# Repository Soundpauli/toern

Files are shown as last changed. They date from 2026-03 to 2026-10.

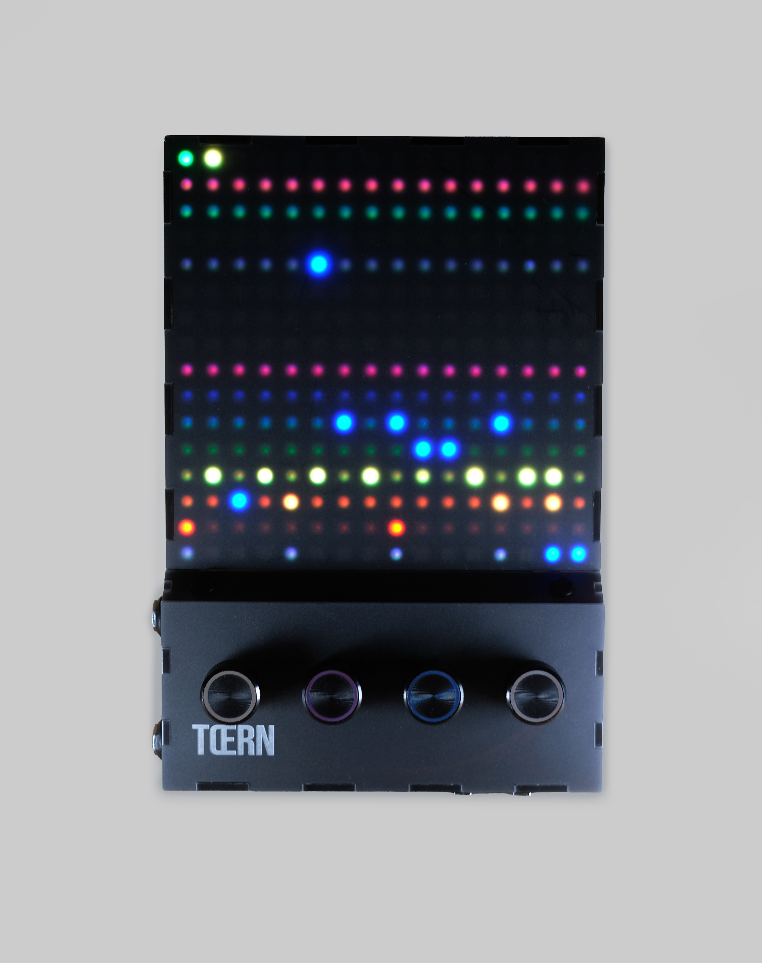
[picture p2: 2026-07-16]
handbook/topview.jpg

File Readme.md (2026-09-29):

# TŒRN `[tɜːn]`

**Open-source sequencer and sampler** — by [warft_ctrl](mailto:jpkuntoff@gmail.com)

> Say it like *turn*. As in: turn the knobs. Turn a doodle into a beat. Turn “I can’t play piano” into “wait, that slap though.”

TŒRN is a sequenced musical device for beginners, makers, and anyone who likes blinking lights more than plugin menus. Think **Etch-A-Sketch™ energy**, but instead of drawing a wobbly staircase you draw drums, synths, and happy accidents — on a vivid **16×16 RGB LED matrix** that is both the screen *and* the keyboard.

It sits on a Teensy 4.1, runs from a Micro SD card full of your WAVs, and is happy on a desk, in a backpack, or on battery at the park where strangers will ask “what *is* that?”

**Status:** under very active development. Things move fast. Stay tuned, and don’t be surprised if yesterday’s weird bug is today’s charming feature (or the other way around).

---

## What it is (in plain language)

You get:

- **8 sample voices** for drums, one-shots, loops, and “that weird recording from the metro”
- **1 three-voice polyphonic synth** with presets (bass, keys, chiptune, pads… the usual suspects)
- **2 monophonic synths** with LFO and arpeggiator for leads that refuse to sit still
- A **16-step × 16-page** sequencer (256 steps of room to overthink), pattern chaining into songs, MIDI in/out, filters, bitcrush, reverb, and enough real-time knobs to keep your hands busy and your laptop jealous

No laptop required once it’s built. Samples live on the SD card. Patterns autosave. You twist, tap, and suddenly it’s 2 a.m.

For the friendly guided tour (first beat in about a minute), open the **[handbook](./handbook/index.html)** in this repo.

---

## A tiny history

TŒRN builds on the legacy of the **NI404**, with more features, fewer cables dangling off the side, and a custom PCB where everything mounts cleanly. The older “extra boards and hope” era is over.

Meet the glow-up:

- **RGB-I2C rotary encoders** — smoother, prettier, and they light up like they mean it  
- **Custom PCB** — codec, charging, and jacks on one board  
- **USB-C** — because micro-USB was a character-building experience we no longer need  
- **LiPo charging port** — optional battery for true “make beats on a train” energy (battery not included; we trust you with electricity)  
- **Proper audio I/O** — 6.35 mm headphone out, line in/out, mic in, *plus* a built-in mic for “sample the room right now” moments  
- **TRS MIDI in/out** — play nice with the rest of your setup  
- **On/off switch** — underrated luxury  
- **Touch buttons** — for the things knobs shouldn’t monopolize  
- **Laser-cut acrylic case** — files included; looks finished, not “breadboard cosplay”  
- **JST connectors** — expansion leads plug in  

Open source as always: schematics, code, and design files are here for you to poke, fork, and improve.

---

## Features (the longer version)

### Sequencer

- **16 channels** in spirit: 8 sample voices (1–8), one 3-voice poly synth (11), two mono synths (13–14)  
- **16 steps per page × 16 pages** → 256 steps per song arrangement space  
- **Voice mode**: each voice keeps its own pattern length. It loops the pages that hold its notes, pitches included, while the other voices keep looping on their own  
- **FIRE** (ETC menu): optional playhead sparks when a chosen voice’s notes light white  
- Store up to **999 patterns**, **999 samples**, **100 samplepacks**  
- **Autosave / autoload** so your 3 a.m. genius doesn’t vanish at boot  
- **Switch patterns live** without stopping playback  
- **Song mode**: chain up to **64** patterns into something resembling a composition  
- Pattern ops: copy/paste, transpose page/channel (±1 octave), smart random notes (major/minor + rhythm ideas), clear page/channel  

### Sample voices (channels 1–8)

- Up to **~12 seconds** per voice at 44.1 kHz  
- Browse and load samples **while playing** (yes, really)  
- Per-voice start/end trim, forward/reverse  
- Samplepacks (including pack 0 = custom per-voice assignment)  
- Record from **built-in mic / line-in / mic-in** straight in the sample browser  
- Save or merge used samples back to the SD card as a pack  

### Synth voices

**Channel 11 — poly synth**

- 3 oscillators per voice × 3 voices  
- Presets: BASS, KEYS, CHPT, PAD, WOW, ORG, FLT, LEAD, ARP, BRSS  
- Per-voice ADSR, filter envelope, pan, volume, pitch (cents & semitones), waveform  

**Channels 13–14 — mono synths**

- 2 oscillators each  
- ADSR, LFO (rate/depth), arpeggiator (step/span)  
- Waveforms: sine, saw, square, triangle  

### Effects (all channels)

- **ADSR** — attack / decay / sustain / release (0–32 range)  
- **Bitcrusher** — bit depth 1–16 (0 = bypass), sample-rate reduction down to glorious crunch  
- **Filter** — LP / HP / BP, 0–10 kHz, resonance 0.7–5.0, smooth transitions  
- **Reverb** — room size, damping, wet/dry  
- Fast filter access on encoder #3 during runtime (assignable default per channel)  

### MIDI, clock & extras

- TRS MIDI in/out, clock send/receive, notes, transport  
- BPM **40–300**, internal clock, external MIDI clock, tap tempo via touch  
- Live recording / looping (touch-hold), up to ~12 s per voice  
- Note probability, velocity, condition triggers (those “only every other bar” tricks)  
- Global transpose, per-channel detune & octave, fine cents on the poly synth  
- Mute / solo, pattern modes (OFF, ON, SONG, NEXT)  
- Stereo routing options, optional external WS2812 strip for ripple eye-candy synced to the music  

---

## Tech specs

| | |
|---|---|
| **Brain** | Teensy 4.1, PSRAM fitted. Audio codec is the SGTL5000 on the carrier |
| **Memory** | 16 MB PSRAM target; Micro SD (handbook suggests up to 64 GB, SanDisk Ultra) |
| **Audio** | 44.1 kHz, 16-bit mono WAV |
| **Controls** | 4× RGB illuminated I2C rotary-push encoders, 3 touch switches |
| **Display** | 16×16 RGB LED matrix (FastLED); up to 2 modules → 32×16 |
| **LED strip** | External 5 V WS2812 connector (configurable length) |
| **I/O** | 6.35 mm headphones, line in/out, mic in; built-in mic; TRS MIDI in/out |
| **Power** | USB-C or optional LiPo + charging |

---

## SD card over USB (Menu → ETC → SD)

TŒRN does **not** mount the Micro SD as USB mass storage. That would be too easy, and also fight the audio engine. Instead:

While **Menu → ETC → SD** is open (screen: WAIT → OK), you can browse and transfer files over **USB Serial**.

### Primary — browser tool

1. On the device: open **Menu → ETC → SD**  
2. On a computer: open **[https://sdtool.tyng.app](https://sdtool.tyng.app)** in desktop **Chrome or Edge**  
3. Click **Connect**, pick the Teensy serial port  
4. Stay on ETC → SD for the whole session  

WAV uploads are converted in the browser to **44.1 kHz mono 16-bit**. Drag folders, multi-file drops, and zip archives are supported.

### Secondary — local CLI / scripting

Any USB Type that includes Serial (e.g. **Serial + MIDI**):

```bash
cd standalone-tools/sd-tool-standalone
pip install pyserial
python3 toern_sd.py -p /dev/cu.usbmodemXXXX list /
# also: put / rm / mkdir / get
python3 toern_sd.py web       # optional local UI at http://127.0.0.1:8787
```

Insert or eject the SD card only with the unit **off** — the firmware re-indexes on boot.

---

## Repo map (where stuff lives)

| Path | What’s there |
|---|---|
| `toern.ino` + `toern_*.ino` | Firmware (the fun / terrifying part) |
| `src/` | Modified audio bits (resampler, freeverb DMA) |
| [`BUILD.md`](./BUILD.md) | Order the rev H board, what to solder, first power-up |
| [`info.md`](./info.md) | Compile and flash (PlatformIO) |
| `PCB/toern_revH/` | Current KiCad board, gerbers, JLCPCB BOM |
| `handbook/` | Human-friendly operator’s guide (how to *use* the device) |
| `devdocs/` | [Docusaurus](./devdocs/) code and hardware (rev H) docs → published at `/docs/` |
| `tools/` / `standalone-tools/` | Helpers; SD tool, sample converter, browser sim → tyng.app |
| `standalone-tools/web-standalone/` | Browser simulator → [sim.tyng.app](https://sim.tyng.app/) |
| `standalone-tools/teensyloader-standalone/` | Firmware flasher → [firmware.tyng.app](https://firmware.tyng.app/) (GPL-3.0) |
| `website/` | Project site (local/deploy-only; handbook + docs copied in manually) |

---

## External libraries & modifications

This project leans on several libraries. Some are stock; some got lovingly (and necessary-ly) poked.

### Modified

- **ResamplingReader.h** (`teensy-variable-playback`)  
  Variable rates, interpolation, multi-channel, loop types (repeat / ping-pong), crossfading — in `src/resamplerReader.h`

- **Freeverb** (`effect_freeverb_dmabuf`)  
  DMAMEM-friendly reverb for Teensy 4.1 — `src/effect_freeverb_dmabuf.*`

- **FastLED**  
  `FASTLED_ALLOW_INTERRUPTS 0` so LEDs and audio don’t argue mid-beat; custom `FastLEDshow()` / `FastLEDclear()` wrappers

- **MIDI**  
  Bigger Serial8 buffers for dense clock traffic (`RX 2048`, `TX 128`) and custom TRS MIDI settings

### Standard / upstream

- **TeensyPolyphony** by Nic Newdigate — polyphonic heart of the thing  
- **Audio Library** (PJRC)  
- **WS2812Serial**, **i2cEncoderLibV2**, **FastTouch**

---

## Get one

Order a TŒRN at **[toern.live](https://toern.live/)**. Questions go to **info@toern.live**.

When it arrives, open the **[handbook](./handbook/index.html)** and start at First beat. Power is USB-C. A battery and a microSD card are not in the parcel; the buy page and the handbook hardware chapter name what to get.

Firmware changes: [`info.md`](./info.md) to flash, [`devdocs/`](./devdocs/) for how the code is shaped, [`firmware-edits`](./devdocs/docs/contributing/firmware-edits.md) for a new menu page. Fabricating a board from the design files is [`BUILD.md`](./BUILD.md) — that is not how a TŒRN is ordered.

---

## License

- **Software / code**: [MIT](./LICENSE) — free for personal and commercial use.  
- **Firmware loader** (`standalone-tools/teensyloader-standalone/` and `tools/teensyloader/`): [GPL-3.0](./standalone-tools/teensyloader-standalone/LICENSE), because that tool is Teensy Loader Javascript. GPL-3.0 applies only to those folders.  
- **Hardware design files** (schematics, PCB layouts, Gerbers, etc.): [CC BY-NC 4.0](https://creativecommons.org/licenses/by-nc/4.0/) — personal / non-commercial use and modification. **Commercial hardware use needs written consent.**

Commercial hardware licensing: Jan aka **warft_ctrl** — jpkuntoff@gmail.com (Hamburg, Germany)

---

## Thank you

Huge thanks to **Paul Stoffregen** and the PJRC crew for Teensy, to the wider open-source audio community, and an especially loud shoutout to **Nic Newdigate** for teensy-polyphony — basically the soul of this project.

Made with too many late nights and exactly the right number of RGB LEDs.

**Jan aka warft_ctrl** (formerly soundpauli)  
Hamburg, 2026

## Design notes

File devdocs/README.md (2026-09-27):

# TŒRN Code Docs

Developer documentation for the TŒRN firmware — how the code is structured and how the pieces talk to each other.

This is **not** the operator handbook (device usage). That lives in the repo-root [`handbook/`](../handbook/) tree (copied into `website/handbook/` for deploy, same pattern as this docs site).

## Layout

| Path | Role |
|---|---|
| `devdocs/` | This Docusaurus app (source of truth in the repo) |
| `website/docs/` | Built static files served at `/docs/` (copied in manually for deploy) |

Like `handbook/`, sources live at the repo root. Publish by building here and copying the output into `website/docs/` before deploy.

## Local preview

```bash
cd devdocs
npm install
npm start
```

Open the URL from the terminal (routes are under `/docs/…`).  
`baseUrl` is `/docs/` to match production: https://toern.live/docs/

## Production build (then copy into website)

```bash
cd devdocs
npm install
npm run build
# copy build/ → website/docs/  (manual, like handbook → website/handbook/)
```

Or from the website package (if present locally):

```bash
cd website
npm run build:docs   # uses scripts/sync-docs.js against ../devdocs
```

Details: [docs → Contributing → This docs site](./docs/contributing/docs-site.md).

## Docs sections

| Section | What it covers |
|---|---|
| Architecture | Big picture, file map, main loop / ISR split |
| Core concepts | Modes, note/pattern data, channel map |
| Audio | Teensy Audio graph, samples, synths, FX |
| Subsystems | UI/LEDs, MIDI/clock, menu, SD |
| Tools | Sample converter, simulator, SD tool, firmware loader, color editor |
| Hardware (rev H) | KiCad board map, connectors, power, fab exports |
| Contributing | Firmware build, menu/EEPROM edit map, memory tips, this docs site |

Edit Markdown under `docs/`. Sidebar order is in `sidebars.js`.

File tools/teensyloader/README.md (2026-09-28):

# Teensy Loader Javascript for Chromium Browsers

This folder is **GPL-3.0** (see `LICENSE`). It is the upstream Teensy Loader Javascript tree. The TŒRN-hosted copy, with the project hex files, is `standalone-tools/teensyloader-standalone/` and is under the same license. The rest of the TŒRN repository is MIT.

This repository hosts a minimal web page and JavaScript library for flashing Teensy firmware via WebHID and opening a Serial connection.

## Quick Start

To test this repository go to the Github pages deployment here: https://coelacant1.github.io/Teensy-Loader-Javascript/Teensy-Loader-Example.html




## Repository Structure

- Teensy-Loader.js  
  The core library containing classes for FirmwareFile, TeensyFlasher, and SerialPortManager.

- Teensy-Loader-Example.html  
  A simple HTML page demonstrating how to:
  - Load a local .hex or .bin file
  - Select a Teensy device via WebHID
  - Flash the firmware
  - Open/close a serial port to display text output

- firmware/
  Example firmware files (e.g., blink_slow_Teensy40.hex, blink_slow_Teensy41.hex). These can be downloaded directly via links or used with the test page.

- .github/workflows/DeployPages.yml  
  A GitHub Actions workflow file that builds and deploys this project to the gh-pages branch, allowing GitHub Pages hosting.

## Local Development

1. Clone or download this repository.
2. If you want to run locally, open a terminal in the project’s directory and start a local server. For example:
```bash
python -m http.server
```
3. Visit http://localhost:8000/Teensy-Loader-Example.html in your browser (Chrome or Edge) and navigate to the HTML file.
4. Select your firmware file and click “Select Teensy Device” to pick a board via WebHID, then “Upload Firmware” to flash. You can also open or close a serial port to see debug output from the Teensy.

## Questions and Support

For additional information or recommendations, use the **Discussions** tab on GitHub.

## Contributing

Contributions are welcome! To contribute:
1. Fork the repository on GitHub.
2. Commit your changes with a descriptive message (git commit -m 'Add YourFeature').
3. Push the branch (git push origin main).
4. Submit a pull request on GitHub.

## License Agreement

This project is licensed under the [GPL-3.0](./LICENSE). The copy in this repository is GPL-3.0, not AGPL.

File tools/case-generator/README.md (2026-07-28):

# Case Generator

Parametric laser-cut case designer. Defaults to an editable profile derived from the outer contour of the production **TŒRN M1 FRONT** panel.

> **Attention:** this is (still) only a demo. If you want to print your own case, use [`TOERN_M1_FINAL.dxf`](./TOERN_M1_FINAL.dxf) (kerf: ca. −0.125 mm) and adapt to your needs. Do not think the results will be 110% perfect ;)

## Run

```bash
cd tools
python3 -m http.server 8766
# open http://127.0.0.1:8766/case-generator/
```

Or from this folder: `npm start` (serves the `tools/` parent so `../tool-shell.css` resolves).

## Workflow

1. **Profile** — click-draw free outline (diagonals OK; **Shift** = H/V). Drag corners, click edge/**+** to add one point, **Delete** to remove. Profile is simplified on close/generate.
2. **Viewer** — orbit the finished plywood case with visible finger joints (opaque).
3. **Nest / Export** — generate and inspect all panels from the FRONT profile. Set **kerf**, export SVG.
4. **Features** — add circles / rounded rects on any panel. Set a profile corner as the **template origin** (FRONT default: bottom-left `(0,0)`), then apply the built-in **TŒRN revG holes** template (from `TOERN_M1_FINAL.dxf`, nudged toward `toern_revG`) or save your own.

## Tips

- The FRONT preset strips the individual production teeth but includes their 3 mm top/bottom depth in the sloped outer contour.
- Drawn profile = finished outside size. Joints are generated on an inset body so male tabs restore that envelope; gaps stay on the baseline (no inward “negative” notches).
- Colinear mid-edge points are removed automatically before finger generation.
- Hole templates use assembly X/Y/Z offsets from the selected profile origin and persist in project JSON plus the browser library.
- Save JSON to reopen a design later.

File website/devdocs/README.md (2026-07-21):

# TŒRN Code Docs

Developer documentation for the TŒRN firmware — how the code is structured and how the pieces talk to each other.

This is **not** the operator handbook (device usage). That lives in [`../handbook/`](../handbook/) on the site, and in the repo-root `handbook/` tree.

## Layout (important for Netlify)

| Path | Role |
|---|---|
| `website/devdocs/` | This Docusaurus app (source of truth) |
| `website/docs/` | Built static files served at `/docs/` |
| `website/scripts/sync-docs.js` | `npm run build:docs` helper |

Netlify uses **`base = website`**, so the docs app must live **inside** `website/` (a repo-root `devdocs/` sibling is invisible to that build).

## Local preview

```bash
cd website/devdocs
npm install
npm start
```

Open the URL from the terminal (routes are under `/docs/…`).  
`baseUrl` is `/docs/` to match production: https://toern.live/docs/

## Production build

```bash
cd website
npm run build:docs   # or full site: npm run build
```

Details: [docs → Contributing → This docs site](./docs/contributing/docs-site.md).

## Docs sections

| Section | What it covers |
|---|---|
| Architecture | Big picture, file map, main loop / ISR split |
| Core concepts | Modes, note/pattern data, channel map |
| Audio | Teensy Audio graph, samples, synths, FX |
| Subsystems | UI/LEDs, MIDI/clock, menu, SD |
| Tools | Sample converter, MIDI convert, SD tool, firmware loader, color editor |
| Hardware (rev G) | KiCad board map, connectors, power, fab exports |
| Contributing | Firmware build, memory tips, this docs site |

Edit Markdown under `docs/`. Sidebar order is in `sidebars.js`.

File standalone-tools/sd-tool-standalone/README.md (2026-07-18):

# TŒRN SD tool (standalone)

Serial file explorer for the TŒRN SD card. The unit does **not** mount the card as USB mass storage; transfers use the USB Serial file server while **Menu → ETC → SD** is open.

## Hosted site (Web Serial)

https://sdtool.tyng.app serves **static files**. The browser talks to the Teensy over **Web Serial**.

### Usage

1. On the device: **Menu → ETC → SD** (screen shows **WAIT**, then **OK** when a host connects)
2. On a computer: open the site in **Chrome or Edge** (desktop)
3. Click **Connect** and pick the Teensy serial port
4. Browse, upload, download, rename, or delete files — stay on **ETC → SD** for the whole session

**Notes:**

- Desktop Chrome/Edge only. Android / Pixel Chrome usually cannot see the Teensy USB serial port.
- Opening the serial port can reboot the Teensy — if the screen leaves the SD page, open **ETC → SD** again after Connect.
- WAV uploads are converted in the browser to **44.1 kHz mono 16-bit**.
- Drag-and-drop accepts **multiple files**, **folders** (nested paths kept), and **`.zip`** archives (extracted in the browser into the current folder). Use **Folder** in the toolbar to pick a directory.

### Deploy to `/var/www/sdtool.tyng.app`

```bash
rsync -avz --delete \
  /Users/jank/git/toern/tools/sd-tool-standalone/index.html \
  /Users/jank/git/toern/tools/sd-tool-standalone/styles.css \
  /Users/jank/git/toern/tools/sd-tool-standalone/tool-shell.css \
  /Users/jank/git/toern/tools/sd-tool-standalone/favicon.svg \
  root@tyng.app:/var/www/sdtool.tyng.app/
```

Apache should use **DocumentRoot** (no Python reverse proxy):

```apache
<VirtualHost *:80>
    ServerName sdtool.tyng.app
    DocumentRoot /var/www/sdtool.tyng.app
    <Directory /var/www/sdtool.tyng.app>
        Options -Indexes +FollowSymLinks
        AllowOverride None
        Require all granted
        DirectoryIndex index.html
    </Directory>
</VirtualHost>
```

Then `certbot --apache -d sdtool.tyng.app` for HTTPS.

Disable the old Python service if it was installed:

```bash
systemctl disable --now toern-sdtool
```

## Local CLI / local web (Python + pyserial)

Still useful for scripting or when Web Serial is unavailable:

```bash
pip install pyserial
python3 toern_sd.py ports
python3 toern_sd.py -p /dev/cu.usbmodemXXXX list /
python3 toern_sd.py web   # http://127.0.0.1:8787 (also uses explorer.html)
```

Requires USB Type with Serial (e.g. **Serial + MIDI**). Protocol commands include ACK-framed `GET` / `PUT`.

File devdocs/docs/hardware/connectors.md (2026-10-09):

---
sidebar_position: 2
title: Connectors & pinouts
description: Audio jacks, MIDI, USB-C, microSD, and JST expansion headers on toern_revH.
---

# Connectors & pinouts (rev H)

Pin tables below follow the **rev H netlist** (`toern_revH.net`). Teensy pin names use the schematic global-label style (`18_A4_SDA` = digital pin 18 / A4 / SDA, etc.). The [schematic PDF](../../../PCB/toern_revH/schematic.pdf) wins if a silk label disagrees.

For *which jack is which on the finished box*, see the handbook hardware page — this doc is the electrical map.

## Panel audio / MIDI / USB

| Ref | Footprint (BOM) | Role |
|-----|---|---|
| **J4** | USB-C receptacle | Host USB (D+/D−, VBUS) |
| **J1** | 6.35 mm Neutrik-style | Headphone out from SGTL5000 HP_L / HP_R / HP_VGND |
| **J5**, **J6** | 6.35 mm | Line-level paths (AC-coupled nets into/out of the codec side) |
| **J7** | 6.35 mm | Mic / related input path (tip tied toward mic capsule net; sleeve GND) |
| **J3**, **J17** | CUI SJ1-3533 (3.5 mm) | TRS MIDI in/out (opto / serial side via TLP2361 etc.) |
| **MK1** | POM-2244P condenser | Built-in mic → codec MIC / MICBIAS path |
| **J8** | Hirose microSD | SPI SD: CS=`10`, MOSI=`11`, MISO=`12`, SCK=`13`, VDD=+3.3V |

Exact silk labels on a built unit may use friendly names (LINE OUT, MIDI IN, …); match by connector family and position on the edge.

## Power / speaker

| Ref | Type | Pins (PCB) |
|-----|---|---|
| **J16** | JST-PH 1×02 | `1` GND · `2` VBAT — LiPo |
| **J10** | JST-PH 1×02 | Speaker outputs from PAM8403 (`U13`) |
| **J9** | JST-PH 1×03 | Matrix / strip: pin 1 = Teensy **17** through **R20** (220 Ω), pin 2 = GND, pin 3 = switched 5 V from **TPS22918** `U8` (enable is Teensy **36**) |
| **S1** | EG2219 slide switch | Main power path between charger system rail and +5V distribution |

## Encoder sockets (I2C RGB encoders)

Several **1×05 pin sockets** share the same bus (examples: `J2`, `J18`–`J24`):

| Pad | Net |
|-----|-----|
| 1 | GND |
| 2 | +5V |
| 3 | `18` SDA |
| 4 | `19` SCL |
| 5 | `27` — encoder interrupt (`INT_PIN` in firmware) |

These match Duppa / i2cEncoderLibV2-style modules used in firmware.

## Analog clock / sidechain (JST-PH 1×02)

Silk on rev H. Pads: **1** = signal, **2** = GND.

| Silk | Ref | Teensy pin | Path |
|---|-----|---|---|
| **CLK-OUT(5V)** | **J25** | **37** | MCU → 74AHCT1G125 (`U15`, 5 V) → 1 kΩ → jack |
| **CLK-IN(3-5V)** | **J26** | **38** | Jack → 22 kΩ → Schottky clamp (`D2`) → 74LVC1G17 Schmitt (`U14`, 3.3 V) → MCU |
| **SIDEC-5V** | **J27** | **28** | MCU → 74AHCT1G125 (`U16`, 5 V) → 1 kΩ → jack |

Firmware: MENU → MIDI → PPQN drives **J25** (rate / width / polarity / STOP). MENU → MIDI → **CIN** sets the **J26** rate (1–32 PPQN) and hold-off. The pin-38 interrupt is attached only in BPM orange EXT and then calls `playNote()` / `playFillNote()` directly; `fillTimer` stays stopped, and `playTimer` only runs as a pulse-relocked one-shot that spaces the extra steps at 1/2 PPQN. **D2** is BAT54S in standard SOT-23 (`toern:BAT54S`: pin 1 anode to GND, pin 2 cathode to +3.3 V, pin 3 common to the clamp node). Early rev H boards used KiCad `D_Schottky_Dual_Series_ACK` (pin 2 = common, pin 3 = cathode), which pulled U14's input to 3.3 V; those boards need D2 removed or bodged. MENU → MIDI → **SIDE** picks which voice pulses **J27** (same width/polarity as PPQN; OFF disables).

Do not use **J11** pin 31 for clock — that pad is unused GPIO.

## Expansion JST-PH 1×05

| Ref | Pad 1 | Pad 2 | Pad 3 | Pad 4 | Pad 5 |
|-----|---|---|---|---|---|
| **J11** | `24` SCL2 | `25` SDA2 | `31` CTX3 | **+3.3V** | GND |
| **J11.5** | `24` SCL2 | `25` SDA2 | `31` CTX3 | **+5V** | GND |
| **J12** | `22` | `5` IN2 | `15` | +3.3V | GND |
| **J13** | `2` OUT2 | `4` BCLK2 | `3` LRCLK2 | `6` | `39` |
| **J14** | `14` | `9` | `16` | +3.3V | GND |
| **J15** | `33` MCLK2 | `32` | `41` | +3.3V | GND |

**J11** / **J11.5** are I2C2 + pin 31 expansion, not the analog clock jacks (those are **J25–J27** above).

## Codec I²C

SGTL5000 (`U3`) control lines:

- SDA → Teensy `18`  
- SCL → Teensy `19`  

Same I²C bus as the encoder chain (distinct 7-bit addresses).

## Schematic PDF

Full readable schematic: [`PCB/toern_revH/schematic.pdf`](../../../PCB/toern_revH/schematic.pdf).

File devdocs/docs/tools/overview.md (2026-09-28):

---
sidebar_position: 1
title: Overview
description: Host-side tools that support TŒRN — sample conversion, SD transfer, firmware, and more.
---

# Tools overview

Besides the firmware and PCB, the repo ships **browser and CLI tools** for samples, patterns, SD files, firmware flashing, and docs imagery.

## Public / hosted

| Tool | URL | Source |
|---|-----|---|
| Sample converter | [audioconvert.tyng.app](https://audioconvert.tyng.app/) | `standalone-tools/audio-converter-standalone/` |
| SD tool | [sdtool.tyng.app](https://sdtool.tyng.app/) | `standalone-tools/sd-tool-standalone/` |
| Browser simulator | [sim.tyng.app](https://sim.tyng.app/) | `standalone-tools/web-standalone/` |
| Firmware tool | [firmware.tyng.app](https://firmware.tyng.app/) | `standalone-tools/teensyloader-standalone/` (GPL-3.0) |
| Color scheme editor | [toern.live/tools/colorsheme/](https://toern.live/tools/colorsheme/) | `tools/colorsheme/` |
| Case generator (demo) | [toern.live/tools/case-generator/](https://toern.live/tools/case-generator/) | `tools/case-generator/` |

## Local / contributor helpers

| Tool | Path | Role |
|---|---|---|
| SD CLI | `standalone-tools/sd-tool-standalone/toern_sd.py` | Scripted list/put/get over USB serial |

## How they relate to the device

```mermaid
flowchart LR
  WAV[WAVs / ZIPs] --> CONV[Sample converter]
  CONV --> SD[microSD layout]
  MID[MIDI file] --> SIM[Simulator]
  HOST[Browser / CLI] --> SDTOOL[SD tool]
  SDTOOL -->|ETC → SD serial| TEENSY[Teensy]
  HEX[.hex firmware] --> LOADER[Firmware tool]
  LOADER -->|WebHID| TEENSY
```

Operator-facing how-to stays in the **handbook**; these pages describe **what each tool is, where the code lives, and how to run or extend it**.

## Next

- [Sample converter](./sample-converter)  
- [SD tool](./sd-tool)  
- [Firmware loader](./firmware-loader)  
- [Color scheme editor](./color-scheme)

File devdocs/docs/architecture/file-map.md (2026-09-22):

---
sidebar_position: 2
title: File map
description: What each firmware file is responsible for.
---

# File map

Arduino builds every `.ino` in the sketch root as one program. Treat the filenames as modules even though they share a global namespace.

## Sketch root

| File | Responsibility |
|---|---|
| [`toern.ino`](https://github.com/Soundpauli/toern/blob/main/toern.ino) | Version, includes, enums, `Mode`/`Note`/`Device`/`GlobalVars`, encoder + touch input, mode switching, playback timers, `setup`/`loop`, most glue |
| [`toern_ui.ino`](https://github.com/Soundpauli/toern/blob/main/toern_ui.ino) | LED matrix drawing: grid, cursor, status, BPM screen, overlays |
| [`toern_menu.ino`](https://github.com/Soundpauli/toern/blob/main/toern_menu.ino) | Nested menu UI (LOOK / RECS / MIDI / VOL / ETC), settings persistence hooks |
| [`toern_helpers.ino`](https://github.com/Soundpauli/toern/blob/main/toern_helpers.ino) | Pattern generation helpers, sample browser lists, misc utilities |
| [`toern_sample.ino`](https://github.com/Soundpauli/toern/blob/main/toern_sample.ino) | Sample preview, trim, load into voices, SD I/O yielding while audio runs |
| [`toern_synths.ino`](https://github.com/Soundpauli/toern/blob/main/toern_synths.ino) | Poly/mono synth voice allocation, presets, `playSound` / `stopSound` |
| [`toern_midi.ino`](https://github.com/Soundpauli/toern/blob/main/toern_midi.ino) | MIDI in/out, clock master/slave, transport, pulse-clock options |
| [`toern_filter.ino`](https://github.com/Soundpauli/toern/blob/main/toern_filter.ino) | Apply filter/FX graph parameters; smooth mixer gain transitions |
| [`toern_filterUI.ino`](https://github.com/Soundpauli/toern/blob/main/toern_filterUI.ino) | Filter-mode sliders on the matrix, encoder color cues |
| [`toern_parameters.ino`](https://github.com/Soundpauli/toern/blob/main/toern_parameters.ino) | Defaults and parameter setters (`setParams`, envelopes, synth presets) |
| [`toern_fileoperations.ino`](https://github.com/Soundpauli/toern/blob/main/toern_fileoperations.ino) | Pattern/project save & load on SD |
| [`toern_sd_serial.ino`](https://github.com/Soundpauli/toern/blob/main/toern_sd_serial.ino) | USB-serial SD file server (Menu → ETC → SD) |
| [`toern_leds.ino`](https://github.com/Soundpauli/toern/blob/main/toern_leds.ino) | Optional external WS2812 strip ripples synced to notes |

## Headers

| File | Responsibility |
|---|---|
| [`audioinit.h`](https://github.com/Soundpauli/toern/blob/main/audioinit.h) | Full Teensy Audio object graph + connections |
| [`notes.h`](https://github.com/Soundpauli/toern/blob/main/notes.h) | Pitch/frequency tables |
| [`colors.h`](https://github.com/Soundpauli/toern/blob/main/colors.h) | Channel / UI color definitions |
| [`font_3x5.h`](https://github.com/Soundpauli/toern/blob/main/font_3x5.h) | Tiny bitmap font for matrix text |
| [`icons.h`](https://github.com/Soundpauli/toern/blob/main/icons.h) | Icon bitmaps for menu/status |

## `src/` (custom audio)

| File | Responsibility |
|---|---|
| [`src/resamplerReader.h`](https://github.com/Soundpauli/toern/blob/main/src/resamplerReader.h) | Modified variable-rate sample playback (from teensy-variable-playback lineage) |
| [`src/effect_freeverb_dmabuf.*`](https://github.com/Soundpauli/toern/blob/main/src/effect_freeverb_dmabuf.h) | Freeverb variant that keeps large buffers in DMAMEM |

## Other trees (not the firmware sketch)

| Path | Role |
|---|---|
| `handbook/` | End-user guide (HTML); copied into `website/handbook/` for deploy |
| `PCB/toern_revH/` | Current KiCad board — see [Hardware overview](../hardware/overview) |
| `tools/`, `standalone-tools/` | Host-side utilities — see [Tools overview](../tools/overview) |
| `devdocs/` | **This** Docusaurus site (code + hardware + tools docs) → published at `/docs/` |
| `website/docs/` | Built static output copied in for deploy (see [This docs site](../contributing/docs-site)) |
| `website/` | Project website (local / deploy-only; gitignored) |
| `_internal-docs/` | Scratch notes / plans (gitignored) |

## Size intuition

`toern.ino` is the largest file by far (~8k+ lines). Prefer adding focused logic to an existing `toern_*.ino` (or a new one) rather than growing the main file further when practical.

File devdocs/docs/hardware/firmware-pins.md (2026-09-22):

---
sidebar_position: 4
title: Firmware pin map
description: How toern.ino pin defines line up with toern_revH nets.
---

# Firmware ↔ rev H pin map

Defines live in [`toern.ino`](../../../toern.ino). Net names below match the rev H netlist (`PCB/toern_revH/toern_revH.net`). The [schematic PDF](../../../PCB/toern_revH/schematic.pdf) wins if a silk label disagrees.

## Core defines

| Firmware | Teensy pin | Board use |
|---|---|---|
| `DATA_PIN` | **17** | WS2812 data. Series **R20** (220 Ω) then **J9 pin 1** |
| `INT_PIN` | **27** | Shared encoder interrupt (pad 5 on encoder sockets) |
| `INT_SD` | **10** | microSD chip-select |
| `SWITCH_1` | **2** | Touch / TTP223 — single mode |
| `SWITCH_2` | **3** | Touch — menu |
| `SWITCH_3` | **4** | Touch — record |
| `SWITCH_4` | **6** | Extra switch net (board-dependent) |
| `SWITCH_5` | **39** | Extra switch net (board-dependent) |
| `BATT_ADC_PIN` | **A16** (40) | VBAT divider |

MIDI on **Serial8** uses pins **34/35** (`RX8`/`TX8`) with enlarged buffers — TRS jacks go through the opto / buffer stage (`TLP2361` `U4`, Schmitt `74LVC2G14` `U5`).

## Buses (by convention)

| Bus | Pins | Devices |
|-----|---|---|
| I²C0 | 18 / 19 | Encoders + SGTL5000 control |
| SPI (SD) | 10–13 | microSD `J8` |
| I²S (codec) | (Audio library defaults on Teensy 4 + SGTL wiring) | `U3` data/clocks — see schematic |
| USB | D+/D− pads on `U6` | USB-C `J4` via pogo pins **CN1** (D−) and **CN2** (D+) |

## When changing pins

1. Update the PCB net / jumper **and** the `#define`s.  
2. Re-check encoder INT (must be common open-drain style as wired).  
3. Re-check SD CS vs any other SPI CS uses.  
4. Battery divider in firmware must match the assembled resistors. On rev H that is **R15** 1 MΩ (VBAT → A16) and **R19** 1.5 MΩ (A16 → GND).

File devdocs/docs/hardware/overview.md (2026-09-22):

---
sidebar_position: 1
title: Overview (rev H)
description: Current PCB revision — KiCad sources, major blocks, and how hardware docs relate to the handbook.
---

# Hardware overview — toern_revH

Current board lives in [`PCB/toern_revH/`](../../../PCB/toern_revH/). Ordering, the off-board shopping list, and first power-up are in the repo-root [BUILD.md](../../../BUILD.md). These pages are the electrical map, not how to play the device (that’s the [handbook](../../../handbook/index.html)).

## What rev H is

A custom carrier that mounts a **Teensy 4.1** and an **SGTL5000** codec, and brings the panel I/O out on **JST** headers. Jacks, sockets, and the power switch are through-hole; the shopping list is in [BUILD.md](../../../BUILD.md).

| Area | On-board parts (high level) |
|---|---|
| MCU | Teensy 4.1 (`U6`) |
| Audio codec | SGTL5000 (`U3`) |
| Power | USB-C (`J4`), BQ24075 charger (`IC1`), EG2219 switch (`S1`), SPX3819 LDOs, TPS22918 load switch |
| Storage | microSD (`J8`) |
| User I/O | 6.35 mm jacks, 3.5 mm MIDI TRS, mic, encoder / expansion JST headers |
| Speaker amp | PAM8403 (`U13`) optional speaker path |

Board stackup: **4-layer**, **1.6 mm** (`F.Cu` / `In1.Cu` / `In2.Cu` / `B.Cu`).

## Files in `PCB/toern_revH/`

| Path | Role |
|---|---|
| [`toern_revH.kicad_pro`](../../../PCB/toern_revH/toern_revH.kicad_pro) / `.kicad_sch` / `.kicad_pcb` | KiCad project (schematic + layout) |
| [`schematic.pdf`](../../../PCB/toern_revH/schematic.pdf) | Plot of the schematic |
| [`Gerber/`](../../../PCB/toern_revH/Gerber) | Gerber + drill export |
| [`jlcpcb/`](../../../PCB/toern_revH/jlcpcb) | JLCPCB-oriented gerbers, BOM, CPL |
| [`teensy/teensy.kicad_sym`](../../../PCB/toern_revH/teensy/teensy.kicad_sym) | Teensy 4.1 symbol, vendored so the schematic opens off this repo |
| `LIB_*`, `TPS22918DBVR/`, `SJ1-3533/` | Local footprints / symbols for key parts. The `LIB_*` trees also contain unused EasyEDA / Eagle / Altium exports |
| `toern_revH-backups/` | KiCad autosave archives |

## Block diagram

```mermaid
flowchart TB
  USB[USB-C J4] --> CHG[BQ24075 IC1]
  BAT[LiPo J16] --> CHG
  CHG --> SW[Power switch S1]
  SW --> LDO[SPX3819 3V3 / 1V8]
  SW --> FIVE[+5V rail]
  LDO --> MCU[Teensy 4.1 U6]
  LDO --> CODEC[SGTL5000 U3]
  FIVE --> ENC[Encoder sockets]
  FIVE --> AMP[PAM8403 U13]
  MCU --> CODEC
  MCU --> SD[microSD J8]
  MCU --> LED[Matrix / strip headers]
  CODEC --> HP[Headphone / line jacks]
  CODEC --> MIC[Mic MK1 / mic jack]
```

## License

Hardware design files are **[CC BY-NC 4.0](https://creativecommons.org/licenses/by-nc/4.0/)** — personal / non-commercial use and modification. Commercial hardware use needs written consent (see root README).

## Next

- [Connectors & pinouts](./connectors) — jacks and JST headers as laid out  
- [Power](./power) — USB, battery, rails, load switch  
- [Firmware pin map](./firmware-pins) — how `toern.ino` matches the board  
- [Fabrication](./fabrication) — ordering from Gerbers / JLCPCB exports

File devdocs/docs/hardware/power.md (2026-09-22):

---
sidebar_position: 3
title: Power
description: USB-C, LiPo charger, regulators, switch, and load-switched accessory rail.
---

# Power (rev H)

## Sources

1. **USB-C (`J4`)** — VBUS into the charger / power-path IC; D+/D− to the Teensy USB pads.  
2. **LiPo (`J16`)** — VBAT / GND into **BQ24075** (`IC1`).

The BQ24075 provides USB-friendly charging and power-path management (system rail while charging). Status LEDs **D4** (red) / **D5** (yellow) hang off charger status pins.

## Main switch

**EG2219 (`S1`)** sits between the charger system output path and the board **+5V** distribution used by Teensy VIN-side power, encoder 5V, PAM8403, etc.

`JP1` is a 3-pad solder jumper and it **ships open**. The center pad goes to the “on” side of **S1**. The switch common is the board **+5V** rail (Teensy VIN, the LDOs, encoder 5 V, PAM8403). With no bridge, sliding the switch does nothing and the rail stays dead.

Bridge **one** side only:

| Bridge | What runs |
|---|---|
| Center ↔ **VYS** (pad B, the end opposite the pin-1 mark) | Normal use. +5V comes from the BQ24075 system output. USB and the LiPo both feed the board through the charger, and **S1** switches that rail. |
| Center ↔ **VBUS** (pad A, the pin-1 end) | USB only. +5V is raw USB 5 V, ahead of the charger output. Unplugging USB kills the rail even if a battery is connected. Useful while checking the board before you trust the charger path. |

Bridging both ends shorts USB 5 V to the charger output.

## Regulated rails

| Regulator | Part | Rail |
|---|---|---|
| `U1`, `U7` | SPX3819 3.3V | `+3.3V` (logic / SD / parts of codec digital) |
| `U2` | SPX3819 1.8V | `+1V8` (SGTL5000) |
| Codec analog | derived | `+3.3VA` net for SGTL analog supply |

Keep digital and analog returns as in the layout — don’t casually short `+3.3V` and `+3.3VA` plane strategy when editing copper.

## Load switch (accessory / strip)

**TPS22918 (`U8`)**:

- Input from **+5V**  
- Enable from Teensy pin **`36`**  
- Switched output feeds **`J9`** (with GND)

Firmware can gate power to an external WS2812 strip / accessory so it isn’t drawing when disabled.

## Battery sense (firmware)

Firmware reads battery through **`A16` (pin 40)** with a divider documented in `toern.ino`:

- **1M (`R15`)** top (VBAT → A16), **1.5M (`R19`)** bottom (A16 → GND), plus smoothing cap  
- Nominal divider ratio: `1.5 / (1.0 + 1.5) = 0.600`; firmware uses calibrated `0.595`

See [Firmware pin map](./firmware-pins) for the ADC constants.

## Speaker amp

**PAM8403 (`U13`)** runs from **+5V**, takes analog feed from the audio path, and drives **`J10`**. Shutdown / control ties into Teensy GPIO (net `30_CRX3` on the enable-related pin in the PCB netlist).

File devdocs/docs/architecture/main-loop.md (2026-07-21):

---
sidebar_position: 3
title: Main loop & timers
description: What runs in ISRs vs loop — and why that split matters.
---

# Main loop & timers

Playback must stay steady even when the UI is busy (drawing LEDs, talking I2C to encoders, reading the SD card). The firmware splits work into **timer ISRs** and **`loop()`**.

## Timers

Declared in `toern.ino`:

| Timer | Job |
|---|-----|
| `playTimer` | Advance sequencer / trigger notes (`playNote` path) |
| `midiClockTimer` | MIDI clock related timing |
| `fillTimer` | Fill triggers at a multiple of beat rate |

`playNote()` is ISR-facing: keep it short. No Serial spam, no SD, no I2C encoder RGB writes, no `FastLED.show()` inside the hot path.

## Main `loop()` responsibilities

Rough order of concerns (see `void loop()` in `toern.ino`):

1. Optional SD serial server poll when Menu → ETC → SD is open  
2. MIDI input (`checkMidi`) early for latency  
3. Deferred settings backup / pause UI / autosave flags  
4. Encoder + button + touch handling (`checkEncoders`, `checkButtons`, `checkTouchInputs`, …)  
5. Mode-specific UI updates and drawing  
6. A single (or carefully limited) LED refresh per frame  

Flags such as `pendingPauseUIUpdate` / `pendingPauseAutoSave` exist so pause can return quickly from timing-sensitive code and finish I2C/SD on a later iteration.

## ISR → loop handoff pattern

```text
ISR sets volatile flag / queues minimal data
        │
        ▼
loop() notices flag
        │
        ▼
does Serial / I2C / SD / FastLED / autosave
```

Example: play-button LED redraw is deferred via `isrPlayButtonTick` so the ISR never blocks on matrix updates.

## SD + audio coexistence

Sample load and file ops call `sdIoBeginAudioSafe()` / `sdIoYield()` / `sdIoEndAudioSafe()` (see `toern_sample.ino`) so the Audio library keeps getting CPU while the SD card stalls.

## Practical rules when editing

1. **If it must happen on the beat** → keep it in the timer path, but only the minimal trigger.  
2. **If it touches hardware slowly** (I2C, SD, Serial, LEDs) → do it from `loop()`.  
3. **Avoid nested `FastLED.show()`** inside draw helpers — prefer one show per frame (see historical notes in `_internal-docs/OPTIMIZATION_PLAN.md` locally).  
4. **Don’t add `yield()` per pixel** in `light()`-style helpers; yield at frame/block granularity.

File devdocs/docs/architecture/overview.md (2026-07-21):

---
sidebar_position: 1
title: Overview
description: How firmware subsystems connect — data, modes, audio, and timing.
---

# Architecture overview

TŒRN is a single Teensy sketch that behaves like a small OS for a sampler-sequencer: a **mode machine** drives the UI, a **note grid** is the musical source of truth, **IntervalTimers** advance playback, and the **Teensy Audio library** renders sound.

```mermaid
flowchart TB
  subgraph inputs [Inputs]
    ENC[Encoders + buttons]
    TOUCH[Touch switches]
    MIDI_IN[TRS / USB MIDI]
    SD[Micro SD]
  end

  subgraph core [Core]
    MODE[currentMode]
    GLOB[GLOB / SMP]
    NOTE["note[x][y]"]
    LOOP[loop]
    ISR[playTimer ISR]
  end

  subgraph out [Outputs]
    LED[16×16 LED matrix]
    ENCLED[Encoder RGB]
    AUDIO[Audio graph]
    MIDI_OUT[MIDI out / clock]
  end

  ENC --> LOOP
  TOUCH --> LOOP
  MIDI_IN --> LOOP
  SD --> LOOP
  LOOP --> MODE
  LOOP --> GLOB
  LOOP --> NOTE
  LOOP --> LED
  LOOP --> ENCLED
  ISR --> NOTE
  ISR --> AUDIO
  ISR --> MIDI_OUT
  MODE --> LOOP
  GLOB --> LOOP
  NOTE --> ISR
```

## Mental model in one paragraph

You edit a 2D grid of `Note` cells (step × pitch/row). Playback walks the X axis on a timer interrupt and triggers sample or synth voices through the Audio graph. The UI never owns music data directly — it mutates `note[][]`, `GLOB`, and `SMP`, then redraws LEDs to mirror that state. Modes (`DRAW`, `FILTERMODE`, `MENU`, …) only change which encoder axes mean what and what `loop()` draws.

## Runtime pillars

### 1. Mode machine

`Mode *currentMode` points at a struct with name, encoder min/max/pos, and knob colors. Switching modes (`switchMode`) rebinds encoder hardware to those ranges. See [Modes](../core/modes).

### 2. Pattern + session state

- `note[x][y]` — packed note events for the loaded pattern (in EXTMEM)  
- `Device SMP` — BPM, samplepack/paths, filter/synth params, mutes, song arrangement  
- `GlobalVars GLOB` — cursor, channel, page, velocity, copy state, …

See [Data model](../core/data-model).

### 3. Timing

`IntervalTimer playTimer` calls playback logic in an ISR so the sequencer keeps running during SD/UI stalls. Heavy work (Serial, I2C, SD, FastLED) is deferred to `loop()` via flags. See [Main loop](./main-loop).

### 4. Audio graph

Declared in `audioinit.h`: sample players, synth oscillators, envelopes, bitcrushers, filters, freeverb, mixers → SGTL5000. Parameters are applied from filter/synth setting arrays. See [Audio graph](../audio/graph).

## Channel map (quick)

| Channels | Engine |
|---|---|
| 1–8 | Sample voices (`AudioPlayArrayResmp`) |
| 11 | 3-voice poly synth |
| 13–14 | Mono synths (LFO / arp capable) |

Details: [Channels](../core/channels).

## Where to change things

| You want to… | Start in… |
|---|---|
| Change what a knob does in a screen | Mode defs + handlers in `toern.ino`, UI in `toern_ui.ino` / `toern_filterUI.ino` |
| Change how notes play | Playback / `playNote` path in `toern.ino` |
| Change sound routing or FX order | `audioinit.h` + `toern_filter.ino` / `toern_parameters.ino` |
| Change menu pages | `toern_menu.ino` |
| Change MIDI / clock | `toern_midi.ino` |
| Change sample load/browse | `toern_sample.ino` + `toern_helpers.ino` |
| Change LED drawing primitives | `toern_ui.ino` / `toern_leds.ino` |

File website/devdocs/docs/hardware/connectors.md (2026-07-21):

---
sidebar_position: 2
title: Connectors & pinouts
description: Audio jacks, MIDI, USB-C, microSD, and JST expansion headers on toern_revG.
---

# Connectors & pinouts (rev G)

Pin tables below are taken from the **rev G PCB netlist** (`toern_revG.kicad_pcb`). Teensy pin names use the schematic global-label style (`18_A4_SDA` = digital pin 18 / A4 / SDA, etc.).

For *which jack is which on the finished box*, see the handbook hardware page — this doc is the electrical map.

## Panel audio / MIDI / USB

| Ref | Footprint (BOM) | Role |
|-----|---|---|
| **J4** | USB-C receptacle | Host USB (D+/D−, VBUS) |
| **J1** | 6.35 mm Neutrik-style | Headphone out from SGTL5000 HP_L / HP_R / HP_VGND |
| **J5**, **J6** | 6.35 mm | Line-level paths (AC-coupled nets into/out of the codec side) |
| **J7** | 6.35 mm | Mic / related input path (tip tied toward mic capsule net; sleeve GND) |
| **J3**, **J17** | CUI SJ1-3533 (3.5 mm) | TRS MIDI in/out (opto / serial side via TLP2361 etc.) |
| **MK1** | POM-2244P condenser | Built-in mic → codec MIC / MICBIAS path |
| **J8** | Hirose microSD | SPI SD: CS=`10`, MOSI=`11`, MISO=`12`, SCK=`13`, VDD=+3.3V |

Exact silk labels on a built unit may use friendly names (LINE OUT, MIDI IN, …); match by connector family and position on the edge.

## Power / speaker

| Ref | Type | Pins (PCB) |
|-----|---|---|
| **J16** | JST-PH 1×02 | `1` GND · `2` VBAT — LiPo |
| **J10** | JST-PH 1×02 | Speaker outputs from PAM8403 (`U13`) |
| **J9** | JST-PH 1×03 | Load-switched rail via **TPS22918** (`U8`, enable on Teensy `36`) — typically external LED-strip / accessory 5V |
| **S1** | EG2219 slide switch | Main power path between charger system rail and +5V distribution |

## Encoder sockets (I2C RGB encoders)

Several **1×05 pin sockets** share the same bus (examples: `J2`, `J18`–`J24`):

| Pad | Net |
|-----|-----|
| 1 | GND |
| 2 | +5V |
| 3 | `18` SDA |
| 4 | `19` SCL |
| 5 | `27` — encoder interrupt (`INT_PIN` in firmware) |

These match Duppa / i2cEncoderLibV2-style modules used in firmware.

## Expansion JST-PH 1×05

| Ref | Pad 1 | Pad 2 | Pad 3 | Pad 4 | Pad 5 |
|-----|---|---|---|---|---|
| **J11** | `24` SCL2 | `25` SDA2 | `31` CTX3 | **+3.3V** | GND |
| **J11.5** | `24` SCL2 | `25` SDA2 | `31` CTX3 | **+5V** | GND |
| **J12** | `22` | `5` IN2 | `15` | +3.3V | GND |
| **J13** | `2` OUT2 | `4` BCLK2 | `3` LRCLK2 | `6` | `39` |
| **J14** | `14` | `9` | `16` | +3.3V | GND |
| **J15** | `33` MCLK2 | `32` | `41` | +3.3V | GND |

Handbook note: **J11** exposes pin **31** (+ GND) for a DIY pulse-clock / trigger cable (MIDI → PPQN). Prefer the **3.3V** header (`J11`) for logic-level accessories unless the peripheral needs 5V (`J11.5`).

## Codec I²C

SGTL5000 (`U3`) control lines:

- SDA → Teensy `18`  
- SCL → Teensy `19`  

Same I²C bus as the encoder chain (distinct 7-bit addresses).

## Schematic PDF

Full readable schematic: [`PCB/toern_revG/schematic.pdf`](https://github.com/Soundpauli/toern/blob/main/PCB/toern_revG/schematic.pdf).

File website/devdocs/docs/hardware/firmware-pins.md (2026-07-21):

---
sidebar_position: 4
title: Firmware pin map
description: How toern.ino pin defines line up with toern_revG nets.
---

# Firmware ↔ rev G pin map

Defines live in [`toern.ino`](https://github.com/Soundpauli/toern/blob/main/toern.ino). Net names below are from the rev G PCB.

## Core defines

| Firmware | Teensy pin | Board use |
|---|---|---|
| `DATA_PIN` | **17** | WS2812 / matrix data (`17_A3_TX4_SDA1` net family) |
| `INT_PIN` | **27** | Shared encoder interrupt (pad 5 on encoder sockets) |
| `INT_SD` | **10** | microSD chip-select |
| `SWITCH_1` | **2** | Touch / TTP223 — single mode |
| `SWITCH_2` | **3** | Touch — menu |
| `SWITCH_3` | **4** | Touch — record |
| `SWITCH_4` | **6** | Extra switch net (board-dependent) |
| `SWITCH_5` | **39** | Extra switch net (board-dependent) |
| `BATT_ADC_PIN` | **A16** (40) | VBAT divider |

MIDI on **Serial8** uses pins **34/35** (`RX8`/`TX8`) with enlarged buffers — TRS jacks go through the opto / buffer stage (`TLP2361` `U4`, Schmitt `74LVC2G14` `U5`).

## Buses (by convention)

| Bus | Pins | Devices |
|-----|---|---|
| I²C0 | 18 / 19 | Encoders + SGTL5000 control |
| SPI (SD) | 10–13 | microSD `J8` |
| I²S (codec) | (Audio library defaults on Teensy 4 + SGTL wiring) | `U3` data/clocks — see schematic |
| USB | D+/D− pads on `U6` | Via USB-C `J4` |

## When changing pins

1. Update the PCB net / jumper **and** the `#define`s.  
2. Re-check encoder INT (must be common open-drain style as wired).  
3. Re-check SD CS vs any other SPI CS uses.  
4. Battery divider ratios in firmware must match the assembled resistors.

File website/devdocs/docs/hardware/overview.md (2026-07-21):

---
sidebar_position: 1
title: Overview (rev G)
description: Current PCB revision — KiCad sources, major blocks, and how hardware docs relate to the handbook.
---

# Hardware overview — toern_revG

Current production-oriented board lives in [`PCB/toern_revG/`](https://github.com/Soundpauli/toern/tree/main/PCB/toern_revG). These pages document the **design files and electrical architecture**, not how to play the device (that’s the [handbook](https://github.com/Soundpauli/toern/tree/main/handbook)).

## What rev G is

A custom carrier that mounts a **Teensy 4.1**, integrates an **SGTL5000** codec path (same role as the Teensy Audio Board), and brings out front-panel I/O with **JST** interconnects so the usual build avoids soldering the harness.

| Area | On-board parts (high level) |
|---|---|
| MCU | Teensy 4.1 (`U6`) |
| Audio codec | SGTL5000 (`U3`) |
| Power | USB-C (`J4`), BQ24075 charger (`IC1`), EG2219 switch (`S1`), SPX3819 LDOs, TPS22918 load switch |
| Storage | microSD (`J8`) |
| User I/O | 6.35 mm jacks, 3.5 mm MIDI TRS, mic, encoder / expansion JST headers |
| Speaker amp | PAM8403 (`U13`) optional speaker path |

Board stackup: **4-layer**, **1.6 mm** (`F.Cu` / `In1.Cu` / `In2.Cu` / `B.Cu`).

## Files in `PCB/toern_revG/`

| Path | Role |
|---|---|
| [`toern_revG.kicad_pro`](https://github.com/Soundpauli/toern/blob/main/PCB/toern_revG/toern_revG.kicad_pro) / `.kicad_sch` / `.kicad_pcb` | KiCad 7+ project (schematic + layout) |
| [`schematic.pdf`](https://github.com/Soundpauli/toern/blob/main/PCB/toern_revG/schematic.pdf) | Plot of the schematic |
| [`Gerber/`](https://github.com/Soundpauli/toern/tree/main/PCB/toern_revG/Gerber) | Gerber + drill export |
| [`jlcpcb/`](https://github.com/Soundpauli/toern/tree/main/PCB/toern_revG/jlcpcb) | JLCPCB-oriented gerbers, BOM, CPL |
| `LIB_*`, `TPS22918DBVR/`, `SJ1-3533/` | Local footprints / symbols for key parts |
| `toern_revG-backups/` | KiCad autosave archives |
| Older `toern_revF_*` copies | Historical leftovers inside the rev G folder |

Also in `PCB/`: `toern_revF/` (previous revision) and `backups/`.

## Block diagram

```mermaid
flowchart TB
  USB[USB-C J4] --> CHG[BQ24075 IC1]
  BAT[LiPo J16] --> CHG
  CHG --> SW[Power switch S1]
  SW --> LDO[SPX3819 3V3 / 1V8]
  SW --> FIVE[+5V rail]
  LDO --> MCU[Teensy 4.1 U6]
  LDO --> CODEC[SGTL5000 U3]
  FIVE --> ENC[Encoder sockets]
  FIVE --> AMP[PAM8403 U13]
  MCU --> CODEC
  MCU --> SD[microSD J8]
  MCU --> LED[Matrix / strip headers]
  CODEC --> HP[Headphone / line jacks]
  CODEC --> MIC[Mic MK1 / mic jack]
```

## License

Hardware design files are **[CC BY-NC 4.0](https://creativecommons.org/licenses/by-nc/4.0/)** — personal / non-commercial use and modification. Commercial hardware use needs written consent (see root README).

## Next

- [Connectors & pinouts](./connectors) — jacks and JST headers as laid out  
- [Power](./power) — USB, battery, rails, load switch  
- [Firmware pin map](./firmware-pins) — how `toern.ino` matches the board  
- [Fabrication](./fabrication) — ordering from Gerbers / JLCPCB exports

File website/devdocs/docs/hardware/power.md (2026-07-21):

---
sidebar_position: 3
title: Power
description: USB-C, LiPo charger, regulators, switch, and load-switched accessory rail.
---

# Power (rev G)

## Sources

1. **USB-C (`J4`)** — VBUS into the charger / power-path IC; D+/D− to the Teensy USB pads.  
2. **LiPo (`J16`)** — VBAT / GND into **BQ24075** (`IC1`).

The BQ24075 provides USB-friendly charging and power-path management (system rail while charging). Status LEDs **D4** (red) / **D5** (yellow) hang off charger status pins.

## Main switch

**EG2219 (`S1`)** sits between the charger system output path and the board **+5V** distribution used by Teensy VIN-side power, encoder 5V, PAM8403, etc.

`JP1` is a 3-pad solder jumper between **VBUS**, a center node, and **VYS** (charger SYS) — for alternate power wiring / bring-up; leave as designed unless you know you need to change it.

## Regulated rails

| Regulator | Part | Rail |
|---|---|---|
| `U1`, `U7` | SPX3819 3.3V | `+3.3V` (logic / SD / parts of codec digital) |
| `U2` | SPX3819 1.8V | `+1V8` (SGTL5000) |
| Codec analog | derived | `+3.3VA` net for SGTL analog supply |

Keep digital and analog returns as in the layout — don’t casually short `+3.3V` and `+3.3VA` plane strategy when editing copper.

## Load switch (accessory / strip)

**TPS22918 (`U8`)**:

- Input from **+5V**  
- Enable from Teensy pin **`36`**  
- Switched output feeds **`J9`** (with GND)

Firmware can gate power to an external WS2812 strip / accessory so it isn’t drawing when disabled.

## Battery sense (firmware)

Firmware reads battery through **`A16` (pin 40)** with a divider documented in `toern.ino`:

- Target: **1.5M** top (VBAT → A16), **1M** bottom (A16 → GND), plus smoothing cap  
- BOM includes **1.5M (`R19`)** and **1M (`R15`)** matching that intent  

See [Firmware pin map](./firmware-pins) for the ADC constants.

## Speaker amp

**PAM8403 (`U13`)** runs from **+5V**, takes analog feed from the audio path, and drives **`J10`**. Shutdown / control ties into Teensy GPIO (net `30_CRX3` on the enable-related pin in the PCB netlist).

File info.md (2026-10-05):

# Compile & upload

Hardware order and first power-up: [BUILD.md](BUILD.md).

Firmware for **Teensy 4.1**. Open the sketch from the **repo root** (`toern.ino` plus the `toern_*.ino` tabs). Custom audio lives in `src/` and is compiled with the sketch.

Match these board options in both Arduino IDE and PlatformIO
(canonical / verified config — keep FLASHMEM on large UI handlers):

| Setting | Value |
|---|---|
| Board | Teensy 4.1 |
| USB Type | **Serial + MIDI + Audio** (`USB_MIDI_AUDIO_SERIAL`) |
| CPU Speed | **816 MHz** |
| Optimize | **Smallest Code** (`TEENSY_OPT_SMALLEST_CODE`) |
| Serial | required for the SD tool and diagnostics |

Serial monitor: **115200** baud.

ITCM (RAM1 code) must stay **under 262144 bytes**. Crossing that line steals a FlexRAM bank from DTCM and the link fails (`free for local variables: -544`). Keep ISR-heavy audio (`src/effect_freeverb_dmabuf.cpp`) small.

---

## PlatformIO (preferred)

Pinned env: `platformio.ini` → `env:teensy41` (`platformio/teensy@6.0.0`). A pre-build script (`scripts/platformio_patch_dependencies.py`) applies the project’s sampler / amplitude-ramp / resampler patches to the downloaded libraries, so you do **not** need hand-edited Arduino libraries.

```bash
cd /path/to/toern
pio run                         # .pio/build/teensy41/firmware.hex
pio run --target upload         # build + Teensy Loader
pio device monitor              # 115200
pio run --target compiledb      # compile_commands.json
```

### CLI upload (no PIO upload target)

Build first, then push the hex with PJRC’s helper (same binary PlatformIO uses). If another Teensy Loader window is already open, quit it so it does not steal the board.

**macOS / Linux** (PlatformIO package install):

```bash
pio run

TEENSY_TOOLS="$HOME/.platformio/packages/tool-teensy"
"$TEENSY_TOOLS/teensy_post_compile" \
  -v \
  -file=firmware \
  -path="$(pwd)/.pio/build/teensy41" \
  -tools="$TEENSY_TOOLS" \
  -board=TEENSY41 \
  -reboot
```

**Windows** (PowerShell):

```powershell
pio run
$tools = "$env:USERPROFILE\.platformio\packages\tool-teensy"
& "$tools\teensy_post_compile.exe" -v -file=firmware `
  -path="$PWD\.pio\build\teensy41" -tools=$tools -board=TEENSY41 -reboot
```

If the helper prints **No Teensy boards were found**, tap the **PROGRAM** button on the Teensy and run the same command again.

Arduino IDE Teensyduino tools (if PlatformIO is not installed):

```bash
# typical Arduino Boards Manager path — adjust the Teensyduino version
TEENSY_TOOLS="$HOME/Library/Arduino15/packages/teensy/tools/teensy-tools/1.59.0"   # macOS
# TEENSY_TOOLS="$HOME/.arduino15/packages/teensy/tools/teensy-tools/1.59.0"        # Linux
# HEX is the .hex Arduino produced, e.g. /tmp/arduino/sketches/.../toern.ino.hex

"$TEENSY_TOOLS/teensy_post_compile" \
  -v -file=toern.ino -path=/path/to/hex-directory \
  -tools="$TEENSY_TOOLS" -board=TEENSY41 -reboot
```

`-file` is the hex **basename without `.hex`**. `-path` is the directory that contains it.

---

## Arduino IDE

1. Install [Arduino IDE](https://www.arduino.cc/) and [Teensyduino](https://www.pjrc.com/teensy/td_download.html) (1.59.x / Teensy AVR core **1.59.0** matches this tree).
2. **File → Open** `toern.ino` from the repo root (not a copy of a single tab).
3. **Tools**:
   - Board: **Teensy 4.1**
   - USB Type: **Serial + MIDI + Audio**
   - CPU Speed: **816 MHz**
   - Optimize: **Smallest Code**
4. **Sketch → Upload** (opens Teensy Loader). Or compile only, then use `teensy_post_compile` as above.

### Libraries

Teensyduino already provides Audio, SD, SdFat, EEPROM, SPI, Wire, LittleFS, SerialFlash, WS2812Serial.

Install (Library Manager or git), versions as in `platformio.ini` where pinned:

| Library | Notes |
|---|---|
| FastLED **3.9.10** | sketch sets `FASTLED_ALLOW_INTERRUPTS 0` |
| MIDI Library **5.0.2** (FortySevenEffects) | |
| Adafruit BusIO **1.17.4** | |
| Adafruit seesaw **1.7.9** | |
| Mapf **1.0.2** | |
| [ArduinoDuPPaLib](https://github.com/Fattoresaimon/ArduinoDuPPaLib) **v1.2.0** | `i2cEncoderLibV2.h` |
| [FastTouch](https://github.com/AdrianFreed/FastTouch) | |
| [teensy-polyphony](https://github.com/newdigate/teensy-polyphony) `#548180ac` | last commit before the multi-channel MIDI API break |
| [teensy-variable-playback](https://github.com/newdigate/teensy-variable-playback) **1.0.16** | |

Arduino IDE does **not** run `scripts/platformio_patch_dependencies.py`. Either build with PlatformIO, or apply the same sampler / `ResamplingReader.h` / `playresmp.h` changes by hand (the repo copies used by PIO are `src/resamplerReader.h` and the patch script).

### Arduino CLI

```bash
arduino-cli compile --fqbn teensy:avr:teensy41:usb=serialmidi,speed=600,opt=o2std

# Upload uses Teensy Loader, not a normal serial port:
arduino-cli upload --fqbn teensy:avr:teensy41:usb=serialmidi,speed=600,opt=o2std
```

If upload cannot see the board, press **PROGRAM** on the Teensy.

---

## After flashing

USB enumerates as **Serial + MIDI**. Keep **Menu → ETC → SD** open if you use the SD serial tool. Insert or eject the Micro SD only with the unit **off**.

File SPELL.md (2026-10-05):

# Spell — concept

Spell is a **2-slot DJ player** product concept for the TŒRN hardware (Teensy 4.1 + 32×16 LED matrix + 4 encoders + 2 capacitive touches + SD + MIDI). It is **not** a step sequencer. The `spell` git branch exists to hold this concept and future implementation; it is not a live firmware product yet.

This document is the source of truth for UX, audio, storage, and implementation constraints.

---

## Product intent

Turn the same physical device into a dual-deck looper / DJ sketch:

- Load one long WAV into **slot 1** and another into **slot 2**
- Play both at once, mix volumes, tweak playback speed per slot
- Browse and preview songs from the SD card without a sequencer grid
- Keep the parts of TŒRN that already feel solid: boot, SD mount, encoders, MIDI clock, headphone/VOL path

Everything sequencer-shaped (grid paint, pages, fills, pattern save, synth channels, etc.) is out of scope for Spell.

---

## Hardware assumptions

| Item | Spell requirement |
|---|---|
| LED matrix | **Always 2 modules** → `maxX = 32`, `maxY = 16` (LEDS=2). Persist this so UI never boots 16-wide by accident. |
| Encoders | 4 × i2cEncoderLibV2 (same addresses / interrupt pin as main) |
| Touches | Touch1 + Touch2 (capacitive); chord = both |
| Audio | SGTL5000 + existing Teensy Audio graph habits |
| Storage | BUILTIN SD; library WAVs live under **`songs/`** (create on first boot if missing) |
| MIDI | Serial8 DIN; clock in/out; BPM report/send |
| Host file transfer | USB Serial SD server (existing `toern_sd.py` / web tool) stays available to move WAVs onto the card |

---

## Modes

Three modes only:

1. **`spellSlots`** — default home (slot view)
2. **`spellBrowse`** — shared file browser, targeted at slot 1 or 2
3. **`menu`** — pruned settings (BPM, VOL, MIDI, SD)

No DRAW / SINGLE / FILTER / SET_WAV-as-product / SONG / IMG / etc. as user-facing modes.

---

## Slot view (home)

### Display (32×16)

- **Row `y == 1`**: bottom border
  - Left half (`x = 1 … mid`): **slot 1** — blue
  - Right half (`x = mid+1 … 32`): **slot 2** — violet
- Above the border: **waveform snippet** per half (from peaks captured at load / browse)
- While a slot is playing: that slot’s waveform (and/or encoder RGB) goes **green**
- Empty slot: dim `S1` / `S2` label is fine
- Optional: battery-low warning overlay (reuse existing battery path)

### Encoder map

| Encoder | Rotate | Press |
|---|---|---|
| 1 | Slot 1 **speed** | Slot 1 **play / stop** |
| 2 | Slot 1 **volume** | — |
| 3 | Slot 2 **volume** | — |
| 4 | Slot 2 **speed** | Slot 2 **play / stop** |

Details:

- **Speed**: continuous playback rate via `AudioPlayArrayResmp::setPlaybackRate` (suggested UI range ~0.50×–2.00×, unity = 1.00×)
- **Volume**: per-slot gain into the mix (map onto voice 1 / voice 2 channel volume → amps / `setAmplitude`)
- Both slots may play and **sum** in the mixer
- Play/stop is **one-shot transport per slot**, not the sequencer playhead

### Touch map (from home)

| Gesture | Action |
|---|---|
| Touch1 | Open browser for **slot 1** |
| Touch2 | Open browser for **slot 2** |
| Touch1+2 | Enter **menu** |

---

## Browser

Shared browser UI; which slot is being filled is set when entering (`browseTarget = 1|2`).

### Behaviour

- Root directory on SD: **`songs/`** (not `samples/`)
- Create `songs/` at boot if absent
- **Enc4**: browse list + start preview of the selected WAV
- **Enc3 press**: **load** selection into the target slot’s RAM voice, capture waveform peaks, return to slot view
- **No seek / seekEnd / trim UI** — loads are full-file (within RAM budget)
- Touch1 / Touch2 again: toggle back home if already browsing that slot, or switch target slot
- Touch1+2: menu

### Preview

- Reuse SD preview path (`playSdWav1` + peak meter) for audition while browsing
- Stop preview when loading, leaving browser, or opening menu
- Do not block the UI on huge peak scans; progressive peaks are OK

### Load

- Decode WAV data chunk → EXTMEM sample buffer for voice **1** or **2**
- Refresh that slot’s peak cache for the home waveform strip
- After load: stop that slot’s playback; user presses Enc1/Enc4 to play

---

## Menu

Touch1+2 opens the existing menu **shell**, but only these top-level pages:

| Page | Role |
|---|---|
| **BPM** | Tempo + **INT / EXT** clock + brightness (same idea as today’s VOLUME_BPM screen) |
| **VOL** | MAIN, GAIN (1–4 bus + master; drop 5–8/SYN if unused), LOUT, PREV, 2-CH, SPKR, HFC |
| **MIDI** | Keep clock send mode / transport / PPQN as needed so BPM send & receive stay real |
| **SD** | USB Serial SD file server (LIST/PUT/GET/…) so a host can push WAVs into `songs/` |

Exit menu (touch or encoder back) → slot view.

### BPM / MIDI requirements

- **INT**: device is clock master; send MIDI clock at `SMP.bpm` (24 PPQN) on Serial8
- **EXT**: follow incoming MIDI clock; estimate/filter BPM; show it on the BPM page (stable indicator when locked)
- Keep battery / CrashReport / EEPROM defer-while-playing habits from main where they still apply

---

## Audio architecture

### Keep / prune

Keep a **small** sample graph:

- Voices `sound1`–`sound4` (+ envelopes / bitcrush / amps / filters / filtermixers)
- **Freeverb on all 4** (wet/dry mixers) — even if UI only uses slots 1–2
- `mixer1` → `mixer_end` → stereo → SGTL5000
- Preview: `sound0` and/or `playSdWav1`
- `AudioAnalyzePeak` for waveforms / optional output meter

Slots map to voices **1 and 2**. Voices 3–4 stay in the graph for headroom / FX consistency unless later used.

### Cut (for a real Spell firmware)

- Synths 11 / 13 / 14
- Sample bank UI for ch 5–8 as product features
- Sequencer `note[][]`, pages, fills, pattern load/save
- FIRE / IMG / EYES / SONG / SETT / RECS / DAT / KIT / WAV-as-sequencer-menu, filter UI, record, child lock, pong, etc.

### Speed

Wire encoder speed → `setPlaybackRate` on the slot’s `AudioPlayArrayResmp`. Interpolation on.

---

## Storage & host workflow

```
SD card
└── songs/
    ├── track_a.wav
    └── track_b.wav
```

- Device browses only `songs/` for Spell loads
- Host uses SD serial tool (`standalone-tools/sd-tool-standalone/toern_sd.py` or web UI) to `mkdir songs` and `put` WAVs
- Prefer simple filenames on-card (spaces work if the tool escapes them; underscore names are safer)

---

## Implementation principles (hard lessons)

These are part of the concept because ignoring them produced a broken device:

1. **Reuse original boot and I/O first**  
   Startup animation, `drawNoSD` / SD wait, encoder ISR + `checkEncoders` / touch debounce, LED power pin, CrashReport — keep working code paths. Do not rewrite the board bring-up.

2. **Do not leave the sequencer home path half-alive**  
   If home is Spell slots, encoder rotation must **not** still drive `GLOB.x` / `GLOB.y` / page cursor. That causes a visible cursor, lag, and “nothing works” while Spell drawing fights DRAW logic.

3. **I2C budget**  
   Do not write encoder RGB every frame. Update RGB on state changes only. Same for unnecessary `writeMin`/`writeMax` thrash.

4. **LEDS=2 is mandatory**  
   Force and persist 2-module mode on Spell builds.

5. **Overlay vs strip**  
   Preferred long-term: a lean Spell firmware on a branch.  
   Acceptable approach: thin overlay on main **only if** DRAW/cursor/sequencer paths are fully gated off on home. A partial overlay is worse than no Spell.

6. **Versioning**  
   Spell firmware versions should use a clear prefix, e.g. `vSpell.01a`.

---

## Suggested architecture (when implementing)

```mermaid
flowchart LR
  touch1 --> browse1[spellBrowse slot1]
  touch2 --> browse2[spellBrowse slot2]
  touchBoth --> menu[menu BPM/VOL/MIDI/SD]
  browse1 -->|enc3 load| slot1
  browse2 -->|enc3 load| slot2
  spellSlots --> mix[mixer1 to mixer_end]
  slot1 --> voice1
  slot2 --> voice2
  voice1 --> mix
  voice2 --> mix
```

**Files likely involved (when coded):**

- `toern.ino` — modes, loop, touches, encoder map, boot
- `toern_sample.ino` / helpers — `songs/` browser, preview, load, peaks
- `toern_menu.ino` — BPM / VOL / MIDI / SD only
- `toern_midi.ino` — clock send/receive, BPM estimate
- `toern_sd_serial.ino` — host WAV transfer
- `toern_ui.ino` — slot borders + dual waveforms
- `audioinit.h` — pruned 4-voice + reverb-all-4 + preview + peaks

---

## Out of scope

- Beatmatching / sync lock between slots
- EQ, cue points, loops-within-file, playlist engine
- Pattern sequencer compatibility on the Spell product build
- Keeping the full main-menu surface “just in case”

---

## Acceptance checklist (for a future first flash)

- [ ] Boot: animation + SD check; matrix is 32×16
- [ ] Home: blue/violet borders, no sequencer cursor
- [ ] Enc1/4 press play/stop; rotate speed; Enc2/3 volume; dual play mixes
- [ ] Touch1/2 browse `songs/`; Enc4 preview; Enc3 load returns home
- [ ] Touch1+2 menu: BPM (INT/EXT + send/receive), VOL, MIDI, SD
- [ ] Host can PUT WAVs into `songs/` over USB serial
- [ ] No 7-blink / encoder I2C death under normal use
- [ ] Lag feels comparable to main on home (no per-frame encoder RGB spam)

---

## Status

Concept only on branch `spell`. No Spell product firmware is checked in; mainline TŒRN sequencer firmware remains the device software until Spell is implemented deliberately against this doc.

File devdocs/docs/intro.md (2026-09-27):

---
slug: /
sidebar_position: 1
title: Introduction
description: Developer docs for how TŒRN firmware is structured — not the device handbook.
---

# TŒRN code docs

These pages explain **how the firmware is organized** and how the major pieces cooperate: sequencer data, UI modes, the Teensy Audio graph, MIDI/clock, and SD I/O — plus **hardware design docs** for the current PCB (`toern_revH`) and **host-side tools** (sample converter, simulator, SD tool, …).

If you want to *use* the device (first beat, controls, sequencing), open the **[operator handbook](https://github.com/Soundpauli/toern/tree/main/handbook)** instead.

## What you are looking at

TŒRN runs on a **Teensy 4.1** as an Arduino multi-file sketch:

| Layer | Role |
|---|---|
| `toern.ino` | Globals, mode state, setup/loop, playback timers, most interaction glue |
| `toern_*.ino` | Focused subsystems (UI draw, menu, MIDI, samples, …) compiled into one sketch |
| `*.h` | Shared tables (notes, colors, fonts) and the audio object graph (`audioinit.h`) |
| `src/` | Forked/custom audio code (resampler, DMA freeverb) |

Arduino concatenates all `.ino` files in the sketch folder; headers and `src/` are normal includes/compile units.

## Start here

1. [Architecture overview](./architecture/overview) — mental model of the whole system  
2. [File map](./architecture/file-map) — which file owns which concern  
3. [Main loop](./architecture/main-loop) — ISR vs loop work (timing-critical path)  
4. [Modes](./core/modes) — how encoders and screens switch behavior  
5. [Hardware overview (rev H)](./hardware/overview) — KiCad board, connectors, power  
6. [Tools overview](./tools/overview) — sample converter, simulator, SD tool, firmware loader, …  

## Explicit non-goals

- Device operation / music-making tutorials → handbook  
- How to play a TŒRN → handbook  
- Marketing / shop chrome → `website/` (local/deploy-only; this Docusaurus app is repo-root `devdocs/`)

## Where this site lives

Source: **`devdocs/`** in the repo. Published at **`/docs/`** on [toern.live](https://toern.live/docs/) (built output copied into `website/docs/` for deploy, like the handbook).  
How to edit and preview: [This docs site](./contributing/docs-site).

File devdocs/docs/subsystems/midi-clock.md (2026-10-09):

---
sidebar_position: 2
title: MIDI & clock
description: MIDI I/O, master/slave clock, and transport handling.
---

# MIDI & clock

[`toern_midi.ino`](https://github.com/Soundpauli/toern/blob/main/toern_midi.ino) owns MIDI parsing, clock generation/following, and note/transport bridging into the sequencer/synths.

## Hardware / library setup

- TRS MIDI via Serial (custom `MidiSettings`, enlarged Serial8 buffers in `toern.ino`)  
- `MIDI.h` handlers for note on/off, clock, start/stop  
- Analog pulse I/O: CLK-OUT pin 37 (`pulseClock*`), CLK-IN pin 38, SIDEC pin 28 (`sidechainOnVoice`, MIDI → SIDE). The CLK-IN GPIO interrupt is attached only in BPM orange EXT.

## Clock paths

| Direction | Entry points |
|---|---|
| Soft MIDI clock out | `updateMidiClockOutput`, `midiClockTick` |
| External clock in | `myClock` (MIDI F8) and `analogClockIsr` (J26, orange EXT only) |
| Sequencer beat | `playTimer` / playback aligned with transport state |

`checkMidi()` is called early in `loop()` for lower latency.

## Notes ↔ engine

- Incoming notes → `handleNoteOn` / `handleNoteOff` → sample or synth triggers (respecting mutes / child lock)  
- Outgoing notes → `MidiSendNoteOn` and related send helpers when MIDI out is enabled  

## Editing safely

Clock math and ISR interplay are easy to break. Prefer small, well-tested changes; there are local planning notes (`_internal-docs/MIDI_CLOCK_RELIABILITY_PLAN.md`) describing past reliability work if you have that folder checked out.

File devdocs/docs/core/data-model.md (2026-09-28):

---
sidebar_position: 2
title: Data model
description: Note grid, Device (SMP), GlobalVars (GLOB), and song arrangement.
---

# Data model

Music and session state live in a few global structures. UI and MIDI are views/controllers over this data.

## `Note` — one grid cell

```cpp
struct Note {
  uint8_t channel;      // 0 = empty; else voice/channel id
  uint8_t velocity;     // 0–127 internally
  uint8_t probability;  // 0–100
  uint8_t condition;    // conditional trigger encoding
  uint8_t midiPitch;    // 0–127 preserved MIDI pitch; 255 = derive from Y
} __attribute__((packed));
```

The live pattern grid:

```cpp
EXTMEM Note note[maxlen + 1][maxY + 1];
```

- **X** is step (across pages × matrix width).  
- **Y** is row / pitch lane on the matrix.  
- Empty cells use `channel == 0`.
- `midiPitch == 255` keeps the historical row-derived pitch. With
  `MIDI > CLMP` off, recorded YPOS/MIDI notes store their absolute incoming
  pitch here while Y remains a folded display/edit position.
- Condition bytes `1,2,4,8,16,17–20` encode loop conditions, `21` is F/F
  fill, and `22` is G/L destination-note glide/legato. Unknown values should
  fall back to always-trigger behavior rather than becoming sparse implicitly.

UI often maps displayed velocity (1–16 rows) to MIDI-ish 1–127 with `mapf`.

## `Device SMP` — pattern / project bag

`EXTMEM Device SMP` holds the loaded project’s non-grid settings, including:

| Field area | Meaning |
|---|---|
| `bpm`, `file`, `pack` | Tempo, pattern id, samplepack id |
| `wav[]`, `samplePathRel[][]` | Sample browser selection + custom paths |
| `param_settings` / `filter_settings` / `synth_settings` | Per-channel parameter tables |
| `mute[]`, `channelVol[]` | Mutes and channel volumes |
| `globalMutes` / `pageMutes` | Mute behavior depending on pattern mode |
| `sp0Active[]` | Samplepack-0 (per-voice custom sample) flags |
| `songArrangement[64]` | Song mode: pattern id per arrangement slot |

Placing `SMP` in **EXTMEM** (PSRAM) keeps DTCM (RAM1) free for hot code/data.

## `GlobalVars GLOB` — cursor & edit context

`GLOB` tracks ephemeral editor state: current channel, page, cursor `(x,y)`, velocity, copy/paste, seek/trim positions, note-shift amounts, subpattern index, etc.

Playback page vs edit page can diverge (e.g. FLOW mode follows `beatForUI` for the visible page while playback owns `GLOB.page` carefully — see comments in `loop()`).

Voice mode (`voiceMode`, SETT → VMOD) gives each channel its own loop length: the highest page that contains any cell of that channel. The transport cycle is the longest voice. At global page G, voice C reads page `((G − 1 + offset) mod len) + 1` in the same column. The offset is set when encoder 2 cues that voice. Notes are matched by `note.channel`, so pitches on other rows stay with the voice. While it is on, FLOW, LOOP, and pattern-mode page lock do not steer playback or the page dots. Song mode is left alone. Encoder 2 steps only pages that contain the current voice (full range if the voice is empty). Changing voice snaps the edit page to that voice. Encoder 4 does not change pages while voice mode is playing. Condition repeats count that voice’s wraps (`voiceLoopCount`).

## Song mode

- `songModeActive` — follow arrangement instead of a single pattern loop.  
- `SMP.songArrangement[i]` — pattern number at song position `i` (0 = empty).  
- `currentSongPosition` — arrangement cursor.

## Persistence

Patterns and settings are written through file-operation helpers (`toern_fileoperations.ino`) and autosave paths triggered from UI/transport (often deferred so SD I/O doesn’t land inside an ISR). EEPROM is used for a smaller set of device preferences (menu address constant `EEPROM_MENU_ADDR`, pulse-clock settings, etc.).

Pattern files retain the legacy `4096 × 4-byte Note` prefix, `FF FE` marker,
and raw `SMP` payload. New saves append an optional `TPIT` version-1 extension
containing one `midiPitch` byte per grid cell. New firmware treats files without
that extension as row-derived; older firmware ignores the trailing extension.

## Invariants worth preserving

- Treat `channel == 0` as empty; reset its probability/condition and
  `midiPitch` metadata rather than leaving orphan state.
- Prefer updating `note`/`SMP` first, then redraw — LEDs should mirror state, not invent it.  
- Large buffers belong in `EXTMEM` / `DMAMEM`, not as function-local `static` arrays (those land in RAM1).

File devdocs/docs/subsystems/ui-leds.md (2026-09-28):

---
sidebar_position: 1
title: UI & LEDs
description: Matrix drawing, encoder RGB, and optional strip ripples.
---

# UI & LEDs

The 16×16 (optionally dual-module) matrix is both display and note grid. Drawing primitives live in `toern_ui.ino`; optional external strip effects in `toern_leds.ino`.

## Matrix primitives

| Function | Role |
|---|---|
| `light(x, y, color)` | Set a logical grid pixel |
| `light_single(...)` | Address a specific module |
| `drawBase` / `drawCursor` / `drawPages` / `drawStatus` | Compose the main sequencer view |
| `drawIndicator` | Encoder-related on-matrix cues |
| `drawNumber` / overlays | Transient values (volume, channel, load %). `drawPageNrOverlay` flashes the page number on the right when CRSR is CHNR and CTRL is PAGE: digits on rows 11–15, no underline. The channel overlay stays on the left. |

Colors come from `colors.h` and mode `knobcolor[]` values.

## FastLED constraints

- `FASTLED_ALLOW_INTERRUPTS 0` — LED show must not nest badly with audio.  
- Prefer **one** show per frame from the main loop path.  
- WS2812 data pin and module count: `DATA_PIN`, `LED_MODULES`, runtime `maxX`.

## Encoder RGB

`i2cEncoderLibV2` LEDs mirror mode colors and status (e.g. blink helpers `triggerExternalOneBlink`). I2C writes belong in `loop()`, not in the playback ISR.

## External strip

`toern_leds.ino` maintains an optional WS2812 strip: length/enable settings, `triggerLedStripRipple(channel)` on note triggers, `updateLedStrip()` from the main loop.

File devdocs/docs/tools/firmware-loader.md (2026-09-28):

---
sidebar_position: 5
title: Firmware loader
description: Browser Teensy flasher (WebHID) at firmware.tyng.app. GPL-3.0.
---

# Firmware loader

**Live:** [https://firmware.tyng.app/](https://firmware.tyng.app/)  
**Source:** [`standalone-tools/teensyloader-standalone/`](https://github.com/Soundpauli/toern/tree/main/standalone-tools/teensyloader-standalone)

Based on **Teensy Loader Javascript** (WebHID flash + optional serial). Used to put a `.hex` / `.bin` onto a Teensy 4.1 from Chrome/Edge without the desktop Teensy Loader app. The same upstream tree is also kept at `tools/teensyloader/`.

## Typical flow

1. Open the tool in a Chromium desktop browser  
2. Choose the firmware file  
3. Select the Teensy via WebHID  
4. Upload / flash  

## Code / licensing

`Teensy-Loader.js` is from [coelacant1/Teensy-Loader-Javascript](https://github.com/coelacant1/Teensy-Loader-Javascript) and is **GPL-3.0**. That license covers `standalone-tools/teensyloader-standalone/` and `tools/teensyloader/` only. The rest of this repository stays MIT. See `LICENSE` in those folders.

`public/toern_firmware_3.0.ino.hex` is the frozen 3.0 build. A later firmware build copies the new hex to `public/toern_firmware_beta.ino.hex` only.

## Local run

```bash
cd standalone-tools/teensyloader-standalone
python3 -m http.server 8000
```

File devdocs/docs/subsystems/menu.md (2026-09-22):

---
sidebar_position: 3
title: Menu system
description: Nested menu state machine and settings surfaces.
---

# Menu system

[`toern_menu.ino`](https://github.com/Soundpauli/toern/blob/main/toern_menu.ino) implements the on-device settings UI entered via the `MENU` mode.

## Structure

Top-level pages fan into submenus flagged by booleans such as:

- `inLookSubmenu`  
- `inRecsSubmenu`  
- `inMidiSubmenu`  
- `inVolSubmenu`  
- `inEtcSubmenu`  

Each has a `current*Page` index. Exiting restores draw vs single via `menuEnteredFromSingleMode`.

## Notable ETC behavior

**Menu → ETC → SD** toggles the USB serial SD server (`toern_sd_serial.ino`). `loop()` watches `inEtcSubmenu` + the active menu setting id and calls `sdSerialServerSetActive` / `sdSerialServerPoll`.

## Settings backup

Menu changes can mark settings dirty (`markSettingsBackupDirty`) and later flush via `serviceSettingsBackup()` from `loop()` — keeping EEPROM/SD writes off the audio ISR path.

## Adding a menu item

The file list and the EEPROM offset table are in [Firmware edits](../contributing/firmware-edits). Short version: a free `mainSetting` id, a `MenuPage` row, a draw `case`, an encoder `case`, and a new EEPROM offset at the end of the settings block if it must survive reboot.

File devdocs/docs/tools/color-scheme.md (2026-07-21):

---
sidebar_position: 6
title: Color scheme editor
description: Edit LED / UI palette colors and sync live to a connected device.
---

# Color scheme editor

**Live:** [https://toern.live/tools/colorsheme/](https://toern.live/tools/colorsheme/)  
**Source:** [`tools/colorsheme/`](https://github.com/Soundpauli/toern/tree/main/tools/colorsheme) (`index.html` SPA)

## What it does

- Visual editor for TŒRN **palette / channel / UI colors** (previews + pickers)
- Export of scheme data for use with the device
- Optional **Live Sync** over serial to push colors while editing (needs firmware support — UI notes “Requires updated firmware”)

Typo in the folder name (`colorsheme`) is historical; keep paths as-is for existing URLs.

## Local run

Needs the parent tool shell CSS (`tools/tool-shell.css`) and site styles when opened from the website tree. Easiest:

```bash
# from a static server that can resolve ../../styles.css as on the live site
# or open via the website root:
cd website && npx serve -l 3080
# then http://127.0.0.1:3080/tools/colorsheme/
```

## Related firmware

Colors used at runtime are defined largely in [`colors.h`](https://github.com/Soundpauli/toern/blob/main/colors.h) and applied through LED/UI code (`toern_ui.ino`, `toern_leds.ino`). The editor is the host-side way to design palettes without recompiling for every tweak.

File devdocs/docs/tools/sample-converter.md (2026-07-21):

---
sidebar_position: 2
title: Sample converter
description: Browser tool that converts audio to 44.1 kHz mono WAV and ships default SD card content.
---

# Sample converter

**Live:** [https://audioconvert.tyng.app/](https://audioconvert.tyng.app/)  
**Source:** [`standalone-tools/audio-converter-standalone/`](https://github.com/Soundpauli/toern/tree/main/standalone-tools/audio-converter-standalone)

## What it does

- Accepts a **folder** of files or a single **ZIP**
- Converts everything to **44.1 kHz · mono · 16-bit WAV** (TŒRN’s sample format)
- Runs **entirely in the browser** (ffmpeg.wasm) — files are not uploaded to a server
- Normalizes awkward characters in folder/file names to ASCII
- **SD CARD** section: download **`SD-CARD-CONTENT.zip`** — default packs, settings, and folder layout for a fresh microSD

## Use with the device

1. Convert your samples (or grab the default SD ZIP).  
2. Copy the result to the card root (or into `samples/` as documented on the tool page).  
3. Or push files while the card stays in the unit via the [SD tool](./sd-tool).

## Code map

| File / area | Role |
|---|---|
| `index.html` | UI + SD card instructions |
| `client.js` / `worker.js` | Conversion pipeline |
| `ffmpeg-core.*` | In-browser ffmpeg |
| `SD-CARD-CONTENT/` | Default card tree packaged for download |

## Local run

Serve the folder over HTTP (ffmpeg workers need a proper origin):

```bash
cd standalone-tools/audio-converter-standalone
python3 -m http.server 8080
# open http://127.0.0.1:8080/
```

There is also a Netlify-oriented path under `website/` for related convert-audio functions used by the main site — the standalone tree above is the self-contained public converter.

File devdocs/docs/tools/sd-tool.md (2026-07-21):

---
sidebar_position: 4
title: SD tool
description: Web Serial and Python CLI for transferring files while Menu → ETC → SD is open.
---

# SD tool

**Live:** [https://sdtool.tyng.app/](https://sdtool.tyng.app/)  
**Source:** [`standalone-tools/sd-tool-standalone/`](https://github.com/Soundpauli/toern/tree/main/standalone-tools/sd-tool-standalone)

TŒRN does **not** expose the microSD as USB mass storage. While **Menu → ETC → SD** is open, firmware runs a **USB serial file server** (`toern_sd_serial.ino`). The SD tool is the host client.

## Browser (Web Serial)

1. Device: **Menu → ETC → SD** (WAIT → OK when connected)  
2. Computer: Chrome or Edge **desktop** → open the site → **Connect**  
3. Stay on ETC → SD for the whole session  

Features: browse, upload, download, rename, delete; multi-file / folder drops; ZIP extract in-browser; WAV → **44.1 kHz mono 16-bit** on upload.

**Caveats:** Android Chrome usually cannot see the Teensy port. Opening serial can reboot the Teensy — re-enter ETC → SD if needed.

See also firmware notes: [SD & storage](../subsystems/sd-storage).

## Python CLI / local web

```bash
cd standalone-tools/sd-tool-standalone
pip install pyserial
python3 toern_sd.py ports
python3 toern_sd.py -p /dev/cu.usbmodemXXXX list /
python3 toern_sd.py -p /dev/cu.usbmodemXXXX put ./kick.wav /samples/kick.wav
python3 toern_sd.py web   # optional UI at http://127.0.0.1:8787
```

Requires a USB type that includes **Serial**.

## Code map

| File | Role |
|---|---|
| `index.html` / `styles.css` | Hosted Web Serial UI |
| `explorer.html` | UI used by local `web` mode |
| `toern_sd.py` | CLI + local server; ACK-framed `GET` / `PUT` / list / mkdir / rm |

Firmware side: `toern_sd_serial.ino`, enabled from `loop()` when the ETC → SD menu page is active.

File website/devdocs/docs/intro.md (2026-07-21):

---
slug: /
sidebar_position: 1
title: Introduction
description: Developer docs for how TŒRN firmware is structured — not the device handbook.
---

# TŒRN code docs

These pages explain **how the firmware is organized** and how the major pieces cooperate: sequencer data, UI modes, the Teensy Audio graph, MIDI/clock, and SD I/O — plus **hardware design docs** for the current PCB (`toern_revG`) and **host-side tools** (sample converter, MIDI convert, SD tool, …).

If you want to *use* the device (first beat, controls, sequencing), open the **[operator handbook](https://github.com/Soundpauli/toern/tree/main/handbook)** instead.

## What you are looking at

TŒRN runs on a **Teensy 4.1** as an Arduino multi-file sketch:

| Layer | Role |
|---|---|
| `toern.ino` | Globals, mode state, setup/loop, playback timers, most interaction glue |
| `toern_*.ino` | Focused subsystems (UI draw, menu, MIDI, samples, …) compiled into one sketch |
| `*.h` | Shared tables (notes, colors, fonts) and the audio object graph (`audioinit.h`) |
| `src/` | Forked/custom audio code (resampler, DMA freeverb) |

Arduino concatenates all `.ino` files in the sketch folder; headers and `src/` are normal includes/compile units.

## Start here

1. [Architecture overview](./architecture/overview) — mental model of the whole system  
2. [File map](./architecture/file-map) — which file owns which concern  
3. [Main loop](./architecture/main-loop) — ISR vs loop work (timing-critical path)  
4. [Modes](./core/modes) — how encoders and screens switch behavior  
5. [Hardware overview (rev G)](./hardware/overview) — KiCad board, connectors, power  
6. [Tools overview](./tools/overview) — sample converter, MIDI, SD tool, firmware loader, …  

## Explicit non-goals

- Device operation / music-making tutorials → handbook  
- Step-by-step “build the kit” / faceplate tour → handbook hardware page (these docs are design/pinout oriented)  
- Marketing / shop chrome → the rest of `website/` (this Docusaurus app is only `website/devdocs`)

## Where this site lives

Source: **`website/devdocs/`** in the repo. Published at **`/docs/`** on [toern.live](https://toern.live/docs/).  
How to edit, preview, and how Netlify builds it: [This docs site](./contributing/docs-site).

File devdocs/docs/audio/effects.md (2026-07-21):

---
sidebar_position: 4
title: Effects & parameters
description: Filters, bitcrush, reverb, and how UI values become Audio settings.
---

# Effects & parameters

Per-channel FX and synth parameters are stored in `SMP` tables and applied by dedicated modules.

## Modules

| File | Role |
|---|---|
| `toern_filter.ino` | `setFilters`, mixer gain smoothing, filter transitions |
| `toern_filterUI.ino` | Matrix sliders, pages, encoder colors for filter mode |
| `toern_parameters.ino` | `setParams`, defaults, envelope/synth default packs, reset |

## FX chain (conceptual)

For a typical sample channel:

**envelope → bitcrusher → filter → freeverb → mixers → output**

Synth channels insert oscillator/ladder stages earlier but still land in crush/filter/verb → mix.

## UI value vs audio value

The matrix usually shows **0–32** (or enums as text). Mapping functions convert those into Hz, resonance, wet/dry, bit depth, etc. When adding a parameter:

1. Extend the settings array / `FilterType` or related enum if needed.  
2. Teach `setFilters` / `setParams` the mapping.  
3. Add a slider definition for filter UI (`SliderDefEntry` / name index tables).  
4. Keep display enums in sync with `enumNames` pointers.

## Fast filter encoder

During play, encoder #3 can adjust a per-channel “default fast filter” target (`defaultFastFilter`, `setDefaultFastFilterValue`) without entering full filter mode — useful when tracing runtime parameter paths.

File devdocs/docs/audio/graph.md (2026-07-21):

---
sidebar_position: 1
title: Audio graph
description: How audioinit.h wires samples, synths, FX, and the codec.
---

# Audio graph

The Teensy Audio design lives in [`audioinit.h`](https://github.com/Soundpauli/toern/blob/main/audioinit.h): object declarations plus `AudioConnection` patch cords. Open it like a schematic.

## High-level signal flow

```mermaid
flowchart LR
  subgraph samples [Samples 1-8]
    S[AudioPlayArrayResmp]
    SE[Envelope]
    SB[Bitcrusher]
    SF[Filter]
    SR[Freeverb]
  end

  subgraph poly [Poly synth ch11]
    PO[Oscillators]
    PM[Mix / ladder / env]
  end

  subgraph mono [Mono synths 13-14]
    MO[Oscillators]
    ME[Env / crush / filter / verb]
  end

  subgraph mix [Output]
    M1[mixer banks]
    END[mixer_end]
    COD[SGTL5000]
  end

  S --> SE --> SB --> SF --> SR --> M1
  PO --> PM --> M1
  MO --> ME --> M1
  M1 --> END --> COD
```

Exact node names differ per channel (`sound1`, `envelope1`, `bitcrusher1`, … and synth-side `Swaveform*`, `Senvelope*`, `Sladder*`).

## Why some objects are `EXTMEM`

Large Audio objects and mixers are annotated `EXTMEM` so their state lives in PSRAM. That is a deliberate RAM1 conservation strategy — see [Memory](../contributing/memory).

## Custom nodes in `src/`

| Component | Why it exists |
|---|---|
| `resamplerReader.h` | Variable-rate / interpolated playback beyond stock players |
| `effect_freeverb_dmabuf` | Freeverb buffers placed in DMAMEM for Teensy 4.1 |

`toern.ino` includes `src/effect_freeverb_dmabuf.h` and sets `FASTLED_ALLOW_INTERRUPTS 0` so LED updates don’t fight the audio ISR world.

## Changing the graph

1. Edit objects/connections in `audioinit.h` (Arduino Audio System Design Tool exports are a common starting point).  
2. Update any pointers/arrays in filter/synth code that assume channel → object mapping.  
3. Revisit mixer gain constants (`GAIN_*`, `MIX_*`) so summed voices don’t clip.  
4. Test with multiple simultaneous sample hits + synths — headroom bugs show up under load, not silence.

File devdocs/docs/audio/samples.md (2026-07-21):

---
sidebar_position: 2
title: Samples
description: Loading, previewing, and assigning WAV data to voices 1–8.
---

# Samples

Sample voices are channels **1–8**. Logic concentrates in `toern_sample.ino` and browser helpers in `toern_helpers.ino`.

## Responsibilities

- Browse folders/files on the SD card (combined list / manifest hooks)  
- Preview a WAV without committing it  
- Load into a channel’s playback buffer / resampler  
- Trim start/end (`GLOB.seek`, `GLOB.seekEnd`, …)  
- Reverse / direction handling  
- Samplepack 0: per-voice custom paths (`SMP.samplePathRel`, `SMP.sp0Active`)  
- Record paths feeding the same sample machinery  

## Audio-safe SD I/O

Long SD reads must not starve the Audio library. The sample module exposes:

- `sdIoBeginAudioSafe()` / `sdIoEndAudioSafe()`  
- `sdIoYield()`  
- channel reload busy flags (`beginChannelSampleReload` / `endChannelSampleReload`)

Call these around blocking file work when audio should keep playing.

## Players

`AudioPlayArrayResmp` instances (`sound0`…`sound8` in `audioinit.h`) play from memory with rate control via the custom resampler. Channel 0 is used for preview / utility paths; performance voices are 1–8.

## UI modes

- `SET_WAV` — browser / assign  
- `RECORD_MODE` — capture into a slot  
- `SET_SAMPLEPACK` — pack selection  

Drawing for waveforms/peaks lives with UI helpers (`showWave`, peak scan functions in `toern_sample.ino`).

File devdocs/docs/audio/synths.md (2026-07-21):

---
sidebar_position: 3
title: Synths
description: Poly channel 11 and mono channels 13–14.
---

# Synths

Synth code lives mainly in [`toern_synths.ino`](https://github.com/Soundpauli/toern/blob/main/toern_synths.ino), with graph nodes in `audioinit.h` and defaults/presets in `toern_parameters.ino`.

## Channel 11 — poly

- Up to `POLY_VOICES` (3) simultaneous voices  
- Multi-oscillator stacks per voice (`Swaveform*`, mixers, ladder filters, envelopes)  
- Instrument presets: BASS, KEYS, CHPT, PAD, WOW, ORG, FLT, LEAD, ARP, BRSS  
- Preset application: `applySynthInstrumentPreset` / `*_synth(...)` helpers  

## Channels 13–14 — mono

- Dual oscillators each (`waveform13_*`, `waveform14_*`)  
- ADSR, LFO, arpeggiator parameters in synth/filter setting tables  
- Share the crush → filter → reverb pattern with other instruments  

## Voice lifecycle

| Function | Role |
|---|---|
| `playSound(note, ch)` | Start a voice for a sequencer/MIDI note |
| `stopSound(note, ch)` | Release / stop |
| `updateSynthVoice(ch)` | Push current settings into Audio objects |
| `switchSynthVoice(...)` | Change instrument type with parameter bundle |
| `autoOffActiveNotes()` | Housekeeping for hanging voices |

Voice timing/state arrays (`voiceStartTime`, sustain levels, resonance, …) sit at the top of `toern_synths.ino`.

## Interaction with FX

Bitcrush / filter / reverb for synth channels are the same conceptual FX slots as samples, applied through `setFilters` / mixer gain helpers so UI sliders stay consistent across channel types.

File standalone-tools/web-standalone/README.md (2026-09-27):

# TŒRN simulator (standalone)

Early browser emulator of the TŒRN groovebox — concept / feel sketch, not a finished product.

## Hosted site

https://sim.tyng.app serves the Vite **build output** (`dist/`) as static files.

### Local develop

```bash
cd standalone-tools/web-standalone
npm install
npm run dev    # http://127.0.0.1:5173
```

Sample / pattern files come from `SD-CARD-CONTENT/` (dev server mounts them at `/sd/`).

### Build

```bash
npm run build   # writes dist/ (+ copies SD-CARD-CONTENT → dist/sd/)
```

### Deploy to `/var/www/sim.tyng.app`

```bash
npm run build
rsync -avz --delete \
  dist/ \
  root@tyng.app:/var/www/sim.tyng.app/
```

Apache **DocumentRoot** (same pattern as sdtool):

```apache
<VirtualHost *:80>
    ServerName sim.tyng.app
    DocumentRoot /var/www/sim.tyng.app
    <Directory /var/www/sim.tyng.app>
        Options -Indexes +FollowSymLinks
        AllowOverride None
        Require all granted
        DirectoryIndex index.html
    </Directory>
</VirtualHost>
```

Then `certbot --apache -d sim.tyng.app` for HTTPS.

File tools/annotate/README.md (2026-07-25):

# Image Annotate

Standalone tool for handbook-style callout images.

## Run

```bash
cd tools/annotate
python3 -m http.server 8765
# open http://127.0.0.1:8765/
```

Or open `index.html` via any static file server from this folder (needs `../tool-shell.css`).

## Workflow

1. **Open / drop** an image
2. **Image** — rotate, crop (handles + aspect presets), background fill
3. **Annotate** — click a target pixel, drag to place the label
4. **Select** — click / Shift·⌘-click / **Select all** (⌘A); drag target / elbow / label
5. **Align** — stack left/right, distribute Y, snap elbows (acts on selection)
6. **Line → label** — global: text flush on line, or line ends left/right of label with gap
7. **Style** — fonts, sizes, colors, line width, end-dot, text/line halo
8. **Export** — PNG (annotated), image only, or self-contained HTML; Save JSON to reopen

### Tips

- Style panel changes apply **live to all callouts** (font, size, colors, line mode)
- **Label on top of line** draws the leader under the text
- **Select all** is in the top bar (also ⌘A)
- Scroll to zoom; **Space**/Alt-drag to pan
- Crop/rotate keep callouts locked to image points

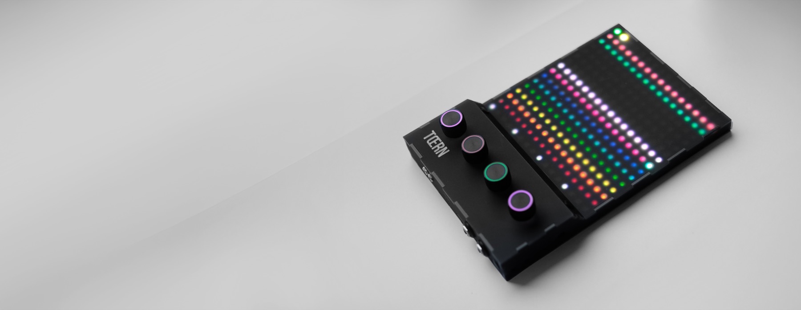
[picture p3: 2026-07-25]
handbook/device_overview.jpg

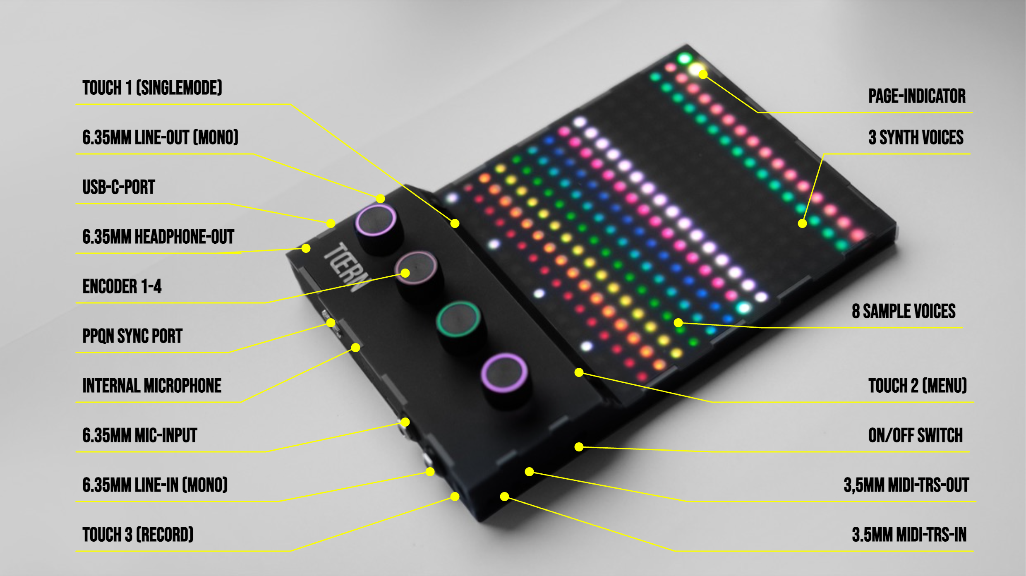
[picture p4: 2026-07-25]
handbook/annotated.png

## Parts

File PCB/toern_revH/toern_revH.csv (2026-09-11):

Reference | Value | Footprint | Qty | lcsc#
C1,C2,C9,C12,C23 | 1u | Capacitor_SMD:C_0402_1005Metric | 5 | C52923
C3,C4,C16,C17,C18,C19,C20,C22,C24,C32 | 10u | Capacitor_SMD:C_0603_1608Metric | 10 | C19702
C5,C26,C29 | 100nF | Capacitor_SMD:C_0603_1608Metric | 3 | C1590
C6 | 1000uF | Capacitor_SMD:CP_Elec_8x10.5 | 1 | C5686929
C7,C8,C25,C37,C38 | 100nF | Capacitor_SMD:C_0402_1005Metric | 5 | C1525
C10,C11,C14,C15,C21 | 100n | Capacitor_SMD:C_0402_1005Metric | 5 | C77020
C13 | 150n | Capacitor_SMD:C_0402_1005Metric | 1 | C162182
C27,C28 | 0.47uF | Capacitor_SMD:C_0603_1608Metric | 2 | C1623
C30,C31 | 1uF | Capacitor_SMD:C_0603_1608Metric | 2 | C15849
C33,C35 | 4.7uF | Capacitor_SMD:C_0603_1608Metric | 2 | C1705
C34 | 10nF | Capacitor_SMD:C_0402_1005Metric | 1 | C15195
C36 | 22µF | Capacitor_SMD:C_0603_1608Metric | 1 | C59461
D1 | BAT54J | Diode_SMD:D_SOD-323F | 1 | C130415
D4 | Red | LED_SMD:LED_0402_1005Metric | 1 | C71911
D5 | Yellow | LED_SMD:LED_0402_1005Metric | 1 | C74342
IC1 | BQ24075TRGTR | BQ24075TRGTR:QFN50P300X300X100-17N-D | 1 | C544783
J1,J5,J6,J7 | AudioJack3_Switch | Connector_Audio:Jack_6.35mm_Neutrik_NMJ6HCD2_Horizontal | 4 | C368502
J2,J18,J19,J20,J21,J22,J23,J24 | Conn_01x05_Socket | Connector_PinSocket_2.54mm:PinSocket_1x05_P2.54mm_Vertical | 8 | C50950
J3,J17 | AudioJack3_Ground | SJ1-3533:CUI_SJ1-3533 | 2 | C4991776
J4 | USB_C_Receptacle_USB2.0 | Connector_USB:USB_C_Receptacle_HRO_TYPE-C-31-M-12 | 1 | C165948
J8 | Micro_SD_Card | Connector_Card:microSD_HC_Hirose_DM3BT-DSF-PEJS | 1 | C597972
J9 | Conn_01x03 | Connector_JST:JST_PH_B3B-PH-K_1x03_P2.00mm_Vertical | 1 | C131339
J10,J16,J25,J26 | Conn_01x02 | Connector_JST:JST_PH_B2B-PH-K_1x02_P2.00mm_Vertical | 4 | C131337
J11,J11.5,J12,J13,J14,J15 | Conn_01x05 | Connector_JST:JST_PH_B5B-PH-K_1x05_P2.00mm_Vertical | 6 | C157993
J28,J29,J30,J31 | 929870-01-12-RA | 3M_929870-01-12-RA:3M_929870-01-12-RA_Assembly | 4 | C20926467
MK1 | Microphone_Condenser | Sensor_Audio:POM-2244P-C3310-2-R | 1 | C529951
R1,R2,R3,R4,R5 | 22R | Resistor_SMD:R_0402_1005Metric | 5 | C25092
R6,R20 | 220R | Resistor_SMD:R_0603_1608Metric | 2 | C22962
R7,R8 | 33R | Resistor_SMD:R_0603_1608Metric | 2 | C23140
R9,R10 | 5.1k | Resistor_SMD:R_0402_1005Metric | 2 | C25905
R11 | 2.2k | Resistor_SMD:R_0603_1608Metric | 1 | C4190
R12,R13,R16,R17,R30 | 10k | Resistor_SMD:R_0402_1005Metric | 5 | C25744
R14 | 49.9k | Resistor_SMD:R_0402_1005Metric | 1 | C100457
R15 | 1M | Resistor_SMD:R_0402_1005Metric | 1 | C26083
R18 | 200k | Resistor_SMD:R_0402_1005Metric | 1 | C25764
R19 | 1.5M | Resistor_SMD:R_0402_1005Metric | 1 | C11812
R21,R22 | 20k | Resistor_SMD:R_0805_2012Metric | 2 | C4328
R23 | 1.1k | Resistor_SMD:R_0402_1005Metric | 1 | C25860
R24 | 1.13k | Resistor_SMD:R_0402_1005Metric | 1 | C166635
R25,R26 | 1.5k | Resistor_SMD:R_0402_1005Metric | 2 | C25867
R27,R29 | 100k | Resistor_SMD:R_0402_1005Metric | 2 | C25741
R28 | 1k | Resistor_SMD:R_0402_1005Metric | 1 | C11702
S1 | EG2219 | EG2219:EG2219 | 1 | C3664594
U1,U7 | SPX3819M5-L-3-3 | Package_TO_SOT_SMD:SOT-23-5 | 2 | C9055
U2 | SPX3819M5-L-1-8 | Package_TO_SOT_SMD:SOT-23-5 | 1 | C24639
U3 | SGTL5000XNBA3 | Package_DFN_QFN:QFN-32-1EP_5x5mm_P0.5mm_EP3.6x3.6mm | 1 | C5196742
U4 | TLP2361V4_E | myLibKicad:5pin SO6_TOS | 1 | C107626
U5 | 74LVC2G14 | Package_TO_SOT_SMD:SOT-23-6 | 1 | C12401
U8 | TPS22918DBVR | TPS22918DBVR:SOT95P280X145-6N | 1 | C131941
U13 | PAM8403D | Package_SO:SOIC-16_3.9x9.9mm_P1.27mm | 1 | C17337
U14 | 74LVC1G17 | Package_TO_SOT_SMD:SOT-23-5 | 1 | C7836
U15 | 74AHCT1G125 | Package_TO_SOT_SMD:SOT-23-5 | 1 | C7484

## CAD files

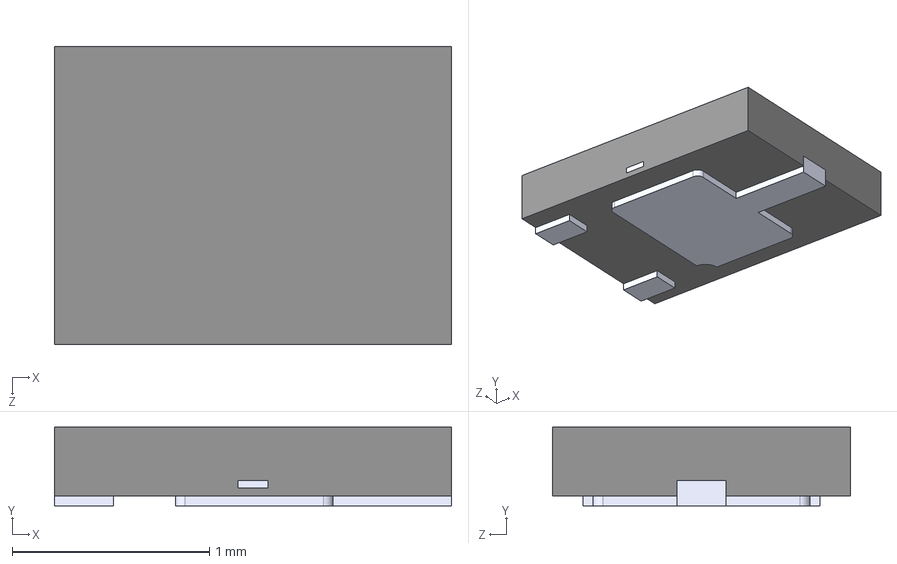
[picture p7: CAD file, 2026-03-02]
PCB/toern_revH/LIB_DMG3415UFY4Q-7/DMG3415UFY4Q-7/3D/DMG3415UFY4Q-7.stp
2.01 x 0.4 x 1.51 mm

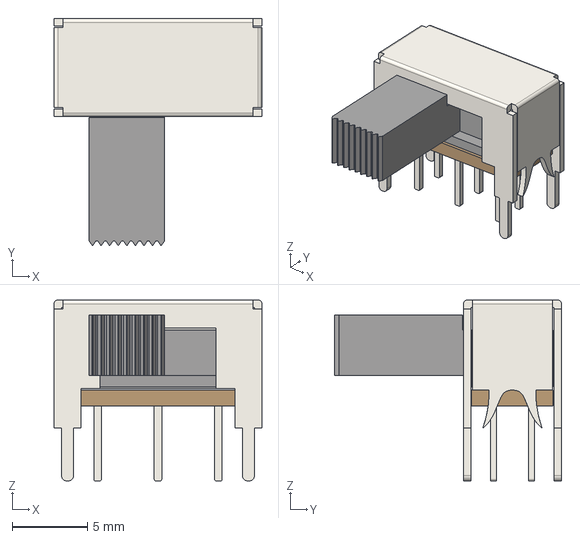
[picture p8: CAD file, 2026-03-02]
PCB/toern_revH/LIB_EG2219/EG2219/3D/EG2219.stp
13.8 x 15.1 x 12.0 mm

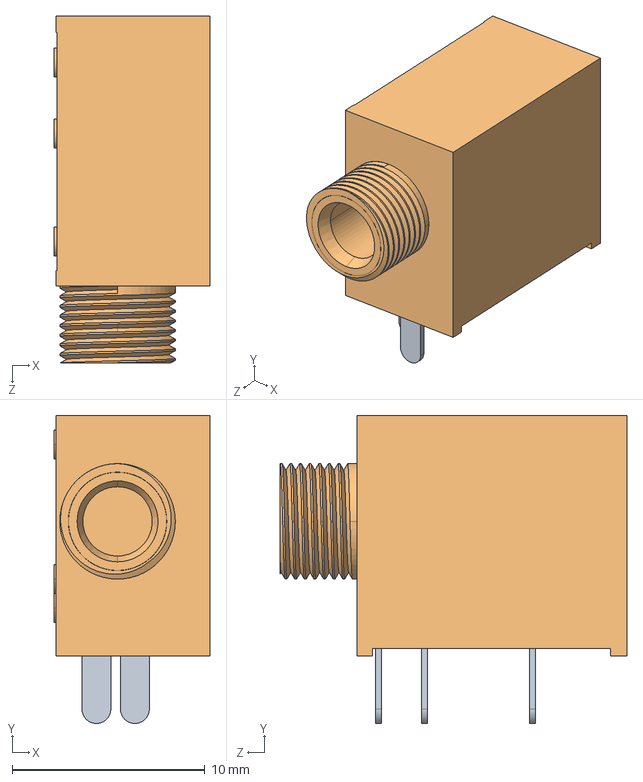
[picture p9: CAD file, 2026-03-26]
PCB/toern_revH/SJ1-3533/SJ1-3533.step
8.10 x 16.0 x 18.0 mm

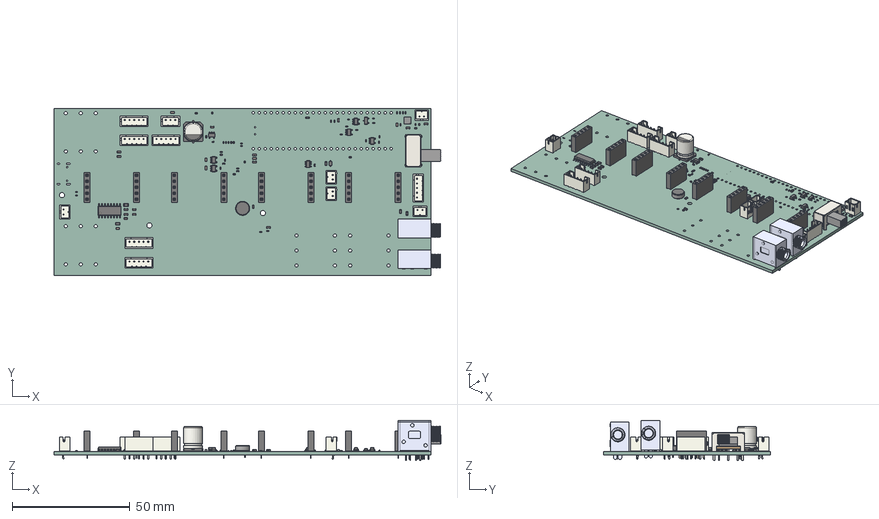
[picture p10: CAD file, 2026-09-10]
PCB/toern_revH/toern_revH.step
164.2 x 71.0 x 17.1 mm
R_0402_1005Metric x 25
POM-2244P-C3310-2-R
PinSocket_1x05_P2.54mm_Vertical x 8
JST_PH_B2B-PH-K_1x02_P2.00mm_Vertical x 5
C_0402_1005Metric x 18
R_0603_1608Metric x 5
C_0603_1608Metric x 20
JST_PH_B5B-PH-K_1x05_P2.00mm_Vertical x 6
ThermalPin
PinsArrayLR
PinsArrayTB
SJ1-3533 x 2
SOT-23-6
SOT-23-5 x 6
LED_0402_1005Metric x 2
JST_PH_B3B-PH-K_1x03_P2.00mm_Vertical
SOT-23
R_0805_2012Metric x 2
CP_Elec_8x10.5
SOIC-16_3.9x9.9mm_P1.27mm
D_SOD-323F
EG2219
toern_revH_PCB

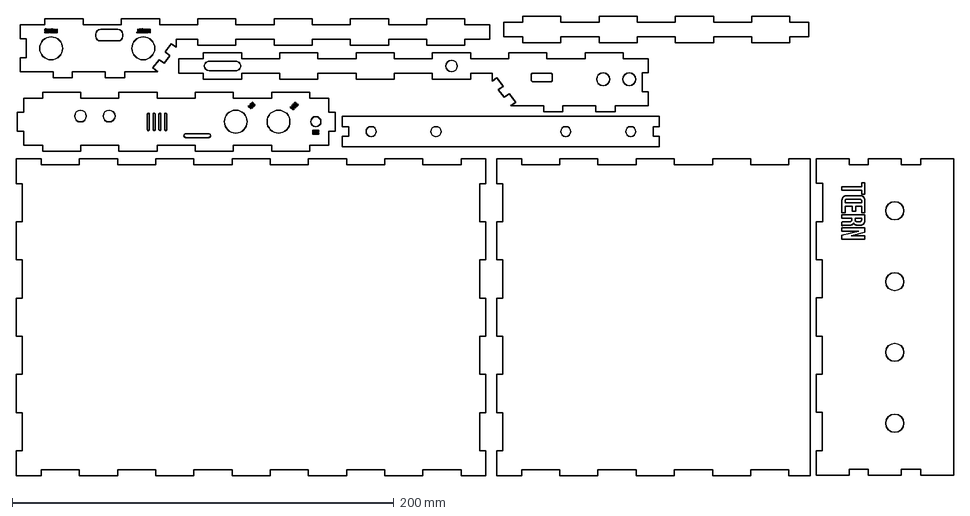
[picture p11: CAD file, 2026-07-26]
tools/case-generator/TOERN_M1_FINAL.dxf
491.0 x 240.6 mm

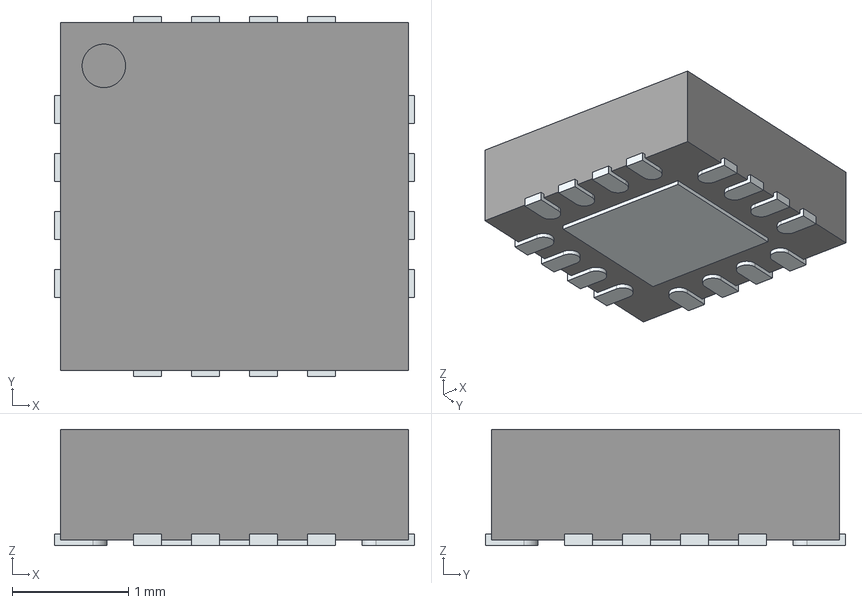
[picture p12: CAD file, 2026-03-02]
PCB/toern_revH/LIB_BQ24075TRGTR/BQ24075TRGTR/3D/BQ24075TRGTR.stp
3.10 x 3.10 x 1.00 mm
ThermalPin
PinsArrayLR
PinsArrayTB

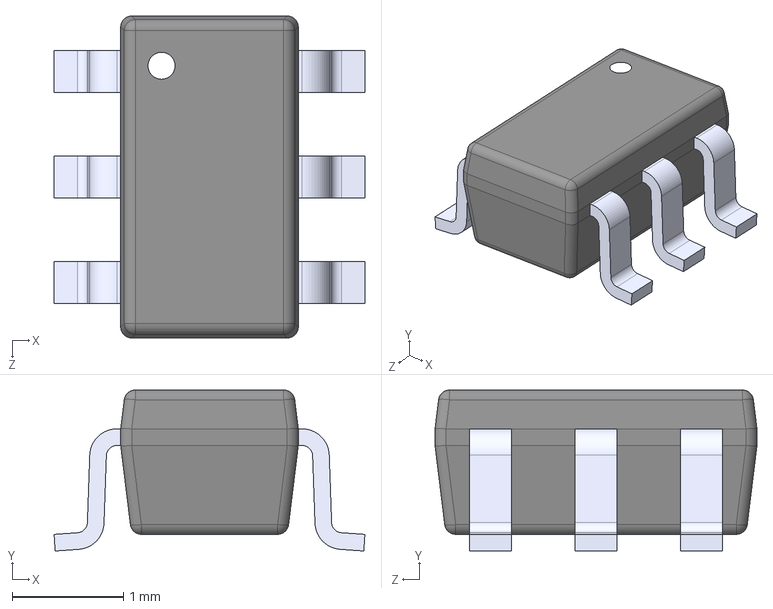
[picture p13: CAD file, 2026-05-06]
PCB/toern_revH/TPS22918DBVR/TPS22918DBVR.step
2.80 x 1.45 x 2.90 mm

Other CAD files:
PCB/toern_revH/LIB_BQ24075TRGTR/BQ24075TRGTR/Allegro/qfn50p300x300x100-17n-d.psm
PCB/toern_revH/LIB_BQ24075TRGTR/BQ24075TRGTR/DEHDL/bq24075trgtr/chips/chips.prt
PCB/toern_revH/LIB_DMG3415UFY4Q-7/DMG3415UFY4Q-7/Allegro/dmg3415ufy47.psm
PCB/toern_revH/LIB_DMG3415UFY4Q-7/DMG3415UFY4Q-7/DEHDL/dmg3415ufy4q_7/chips/chips.prt
PCB/toern_revH/LIB_EG2219/EG2219/Allegro/eg2219.psm
PCB/toern_revH/LIB_EG2219/EG2219/DEHDL/eg2219/chips/chips.prt

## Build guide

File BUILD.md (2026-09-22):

# Fabricating the board

A TŒRN ordered from [toern.live](https://toern.live/) is ready to play. Start at the [handbook](handbook/index.html). This page is only for someone building the rev H board from the design files.

The SGTL5000 codec is on that board. Flash steps live in [`info.md`](info.md).

Hardware files are [CC BY-NC 4.0](https://creativecommons.org/licenses/by-nc/4.0/). Personal builds are fine. Selling boards needs written consent (see the [README](Readme.md)).

## Order the PCB

Upload [`PCB/toern_revH/jlcpcb/production_files/GERBER-toern_revH.zip`](PCB/toern_revH/jlcpcb/production_files/GERBER-toern_revH.zip).

| | |
|---|---|
| Layers | 4 |
| Thickness | 1.6 mm |
| BOM | [`BOM-toern_revH.csv`](PCB/toern_revH/jlcpcb/production_files/BOM-toern_revH.csv) |
| Placement | [`CPL-toern_revH.csv`](PCB/toern_revH/jlcpcb/production_files/CPL-toern_revH.csv) |
| Schematic | [`schematic.pdf`](PCB/toern_revH/schematic.pdf) |

Ask for SMT assembly of the chip parts (SGTL5000, BQ24075, regulators, USB-C, microSD, the small passives). If the quote substitutes the codec or the charger, stop and check the footprint. Those two packages are unforgiving.

### Solder these yourself

The BOM includes them so the positions are documented. Their footprints are through-hole, so a normal SMT quote leaves them empty:

| Refs | Part |
|---|---|
| J28–J31 | 3M 1×12 sockets, LCSC C20926467. The Teensy sits here |
| CN1, CN2 | Pogo pins, LCSC C5157282. USB D− and D+ from the USB-C jack into the Teensy |
| J1, J5–J7 | 6.35 mm jacks, LCSC C368502 |
| J3, J17 | 3.5 mm MIDI jacks, LCSC C4991776 |
| J2, J18–J24 | 1×05 pin sockets, LCSC C50950. Encoder plugs |
| J9–J16, J11.5, J25–J27 | JST-PH headers (2, 3, and 5 pin) |
| S1 | Power switch EG2219, LCSC C3664594 |
| MK1 | Electret mic, LCSC C529951 |
| C6 | 1000 µF electrolytic, LCSC C5686929 |
| JP1 | Solder jumper, not in the BOM. Open until you bridge it. See below |

Pin 1 on a JST header is the marked pin on the footprint. Match the schematic before crimping a cable.

### JP1 — pick one bridge

The jumper is three open pads. The center pad is the “on” side of the power switch. Until you solder one gap, the switch does not connect +5 V and the board stays off.

- **Normal use:** bridge the center pad to **VYS** (the end opposite the pin-1 mark). +5 V then comes from the BQ24075 output, so USB and a LiPo both run the board and the switch turns that rail on and off.
- **USB only:** bridge the center pad to **VBUS** (the pin-1 end). +5 V is raw USB 5 V. Pull the cable and the rail dies, battery or not. Use this while you are still checking the board.

Solder one gap. Bridging both shorts USB 5 V to the charger output.

## Buy separately

These are not on the JLCPCB BOM.

| Qty | Part | Notes |
|-----|---|---|
| 1 | Teensy 4.1 with PSRAM soldered on | Pattern data and the audio objects live in `EXTMEM`. A 4.1 with no PSRAM chip will not run this firmware. The README targets **16 MB** (two PSRAM chips). PJRC’s common add-on is one 8 MB chip; fit what you ordered and check the linker’s EXTMEM size after the first build |
| 4 | [Duppa I2C Encoder V2.1](https://www.duppa.net/shop/i2cencoder-v2-1/) plus their illuminated RGB encoder | The bare board does not include the knob. Schematic footprint name is `DuppaI2CEncoderV2.1`. With `exttouch` left `false` in `toern.ino`, encoder indexes 0–3 use addresses **0x01, 0x41, 0x20, 0x61**. The Duppa sheet shows the solder jumpers. Each module has a 5-pin header on both sides; the board’s eight 1×05 sockets are those headers |
| 1 | 16×16 WS2812 / NeoPixel matrix | Data leaves **J9 pin 1** through R20 (220 Ω) from Teensy pin 17. **J9 pin 2** is GND. **J9 pin 3** is switched 5 V (TPS22918). A second matrix can be chained from the first module’s data out; firmware allows two (`LED_MODULES`) |
| 3 | Touch pads | Pins **2, 3, 4** (single, menu, record). They are on **J13** with pins 6 and 39. J13 has no power pin; take 3.3 V from a header that has it (J12, J14, or J15) and check the schematic before crimping. The record input comment in firmware names a TTP223-style module |
| 1 | Single-cell LiPo, JST-PH 2-pin | **J16 pin 1 = GND, pin 2 = VBAT** into the BQ24075. Reversed polarity is the expensive mistake. Leave the battery off until the rails look right |
| 1 | Small speaker, 4 Ω or 8 Ω | Optional. **J10** is the PAM8403 output (pin 1 ROUT−, pin 2 ROUT+) |
| 1 | microSD | Handbook: SanDisk Ultra, UHS-I. 32 GB FAT32 or 64 GB exFAT both work |
| 1 | USB-C cable | Power and firmware |
| | Case | [`tools/case-generator/TOERN_M1_FINAL.dxf`](tools/case-generator/TOERN_M1_FINAL.dxf), kerf about −0.125 mm. The case generator in that folder is a demo, and its hole template was drawn around an older board. Check holes against rev H before cutting a stack |

## First power

Do this before you trust a battery or a full LED matrix.

1. SMT is on the board. Look at the SGTL5000 (`U3`) and the BQ24075 (`IC1`) for bridges.
2. Solder the Teensy sockets (J28–J31) and the two pogo pins (CN1 = D−, CN2 = D+). USB from the board jack reaches the Teensy only through those pogos.
3. Leave the Teensy out. Leave the LiPo unplugged. **JP1** must already be bridged (VYS for normal use, VBUS for a USB-only check). Plug USB-C, slide **S1** on.
4. Measure before anything else. You want about **5 V** on the switched rail, **3.3 V** from U1/U7, **1.8 V** from U2. If a rail is wrong, unplug and stop.
5. Power off. Seat the Teensy. PSRAM is already soldered on the module. Power on again and confirm 5 V and 3.3 V are still sane.
6. Flash with PlatformIO. Steps and the exact board menu are in [`info.md`](info.md). USB type is **Serial + MIDI**. If the computer sees nothing, the pogos are not touching the Teensy USB pads, or the Teensy needs its PROGRAM button once.
7. Power off. Insert the microSD. Power on. Headphones on **J1**. You want USB serial, a lit matrix once J9 is wired, one encoder that turns, and headphone audio. Battery percentage (Menu → ETC → BATT) only means something after J16 is wired and the divider (R15 1 MΩ, R19 1.5 MΩ) matches the firmware constants.

## SD card

The firmware does not mount the card as a USB disk. Format with the SD Association formatter (FAT32 up to 32 GB, exFAT for 64 GB). Copy a starter layout to the **root** of the card.

The handbook points at [audioconvert.tyng.app](https://audioconvert.tyng.app/) → **SD CARD** → `SD-CARD-CONTENT.zip`. That zip is not in git. If the site is down, put 44.1 kHz mono 16-bit WAVs on the card with the CLI in [`standalone-tools/sd-tool-standalone`](standalone-tools/sd-tool-standalone) while Menu → ETC → SD is open, or with a card reader. Insert and eject only with the unit off.

## Change the firmware

Build with `pio run` from the repo root. The Arduino IDE will not apply [`scripts/platformio_patch_dependencies.py`](scripts/platformio_patch_dependencies.py), so a menu-only edit can still ship a wrong sampler.

Where a new menu page has to land, and which EEPROM bytes are already taken: [firmware edits](devdocs/docs/contributing/firmware-edits.md).

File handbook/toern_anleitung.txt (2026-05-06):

Basics:

* Patterns and Samplepacks are not connected in any way.
* A Pattern is just note triggers + filters, efx + parameters. 
* Used Samples and Soudpacks need to be saved as PACK, and PACKS need to be loaded individually - this enables more flexibility.
* Samplepacks and patterns both can be loaded at runtime individually without affecting settings like filters or bpm.

AutoLoad/Save:
	* Only on Pause, TOERN autosaves pattern / triggers / filters. 
	* SAMPLES and Soundpacks does NOT autosave (see. basics)
	* After turning the unit on, autosaved pattern + parameters + filters gets loaded.

Touch Buttons:
	Touch left: Toggle between FullMode(F) and SingleMode(S). TOERN always starts in FullMode.
	Touch right: Opens main menu
	Touch front: starts a direct recording on the current channel (line/mic) until released (Important: CAN NOT BE SAVED YET!)

Short Clicks:
	E1:Press: REMOVE a note
	E2:Press:toggle MUTE of channel
	E3:Press: Toggle PLAY / PAUSE
	E4:Press: SET a note

Long Clicks:
	E1: Long press+move for remove multiple notes
	E2: Long press Toggles SOLO for current Channel
	E3: Long Press opens FILTERS (+Parameter/Efx/Synth) Mode for the current cannel
	E4: Long press+move to set multiple notes (aka "draw")

FILTERS:
Different Pages for different Filters/EFX/etc.:
> Touch Right: cycles through all pages
> Touch Left: Exit
> E4: LongPress: Resets filters of that page to default

1: PFRB (fully implemented)
	-P: Pass(low+high): (Default/Bypass is Value=15 / middle)
	-F: FilterFreq for Pass
	-R: Reverb. Works on channels 1+2,7+8 and InstrumentVoice(11), and synthVoices(13+14)
	-B: Bitcrusher

3: ADSR: (fully implemented for SynthVoices 11+13+14, nearly no effect on 1-8)
	-A: "ATTC": Attack
	-D:	"DCAY": Decay
	-S; "SUST": Sustain
	-R: "RLSE": Release

4: CRFO (only usable for channel 11) 
	-C: "CUT": Cutoff
	-R: "RES": Resonance
	-F: "FLT": Filterfrequency
	-O: "OCTV": Octave (not yet implemented)

5: WICS (only usable for channel 11)
	-W: "WAVE": Waveform (not yet implemented)
	-I: "INST": Instrument:  Can be 1-8: BA(ss), KE(ys), CH(iptune), PA(d), WO(w), OR(gan), FL(ute), LE(ad), AR(p), BR(ass)
	-C: "CENT": Cent / Octave
	-S: "SEMI": Halbton

6: RDO[W] 
* (Channel 1-8[RDP] / 1-3[RDOS] / 13+14[RDOW])
	-R: "RES": Resonance (not yet implemented)
	-D: "DTNE": Detune
	-O: "OCT": Octave (not yet implemented)
	[-S: "SND": Sound] (not yet implemented)
	[-W: "WAVE": Waveform] (not yet implemented)

7: NDPT (Channel 1-3), 
* 3 Different Drums: BaseDrum(Channel 1), HiHat(Channel 2) and Snare (Channel 3), only usable if SND=DRUM is selected in RDOS
* not yet fully implemented
	-N: "NOTE": Note of Drum
	-D: "DCAY": Decay of Drum
	-P: "PITC": Pitch of Drum
	-T: "TYPE": Type of Drum

Main Menu:
1:LOAD/SAVE PATTERN ("file")
	E1:Press loads
	E2:Press saves
	E3:turn: Selects if pattern should be loaded with all its FILTERS("+") or without
	E4:turn: Selects Pattern slot
	Touch Right or Left: EXIT

	* loading a NEW file (blue numbers) auto resets all Filters, as well as BPM, as long the option ("+") isnt selected with E3.e
	* loading an exisiting file, also loads all saved Filters
	* saving a file also saves all filters
	* saving a file does NOT save samples (yet), they have to be loaded / saved from SAMPLEPACK menu.

2:LOAD/SAVE SAMPLEPACK ("pack")
	E1:Press loads
	E2:Press saves
	E4:turn: Selects PACK slot
	Touch Right or Left: EXIT

	* Saves the current used Samples (which where loaded from SD) to an own samplepack which can be re-used later in the same or another pattern.
	* Important: Edits to Samplelength as well as "live-looping"-recorded samples from using "Toch front" are NOT saved to samplepacks (yet)

3: Record-Input Select
	E4: Press: Toggles beween MIC/LINE
	E3: Turn: Sets the Mic-In-Level (doesnt work well, sadly)

4: LOAD WAVE/SAMPLE ("wave") 
	E1:Press loads SAMPLE to channel (see color)
	E1:Turn: Selects SampleStart position
	E2:Press+hold: record MIC/LINE to SAMPLESLOT (important: overwrites without asking!)
	E4:turn: Selects SAMPLE FOLDER (1-9)
	E4:turn: Selects SAMPLE slot (0-99)
	Touch Right or Left: EXIT

	*LOAD/SAVE only works if a sampleslot is selected with the ypos of the cursor (1-8), otherwise it shows "(-)"

5: SET BPM+VOLUME+BRIGHTNESS ("BPM")
	E2:Turn: Selects brightness
	E3:turn: Selects volume
	E4:turn: Selects bpm
	Touch Right or Left: EXIT

6: Midi Clock ("clck")
	E4: Press: Toggles Intern(TOERN) / Extern (via MIDI-TRS)
	Touch Right or Left: EXIT

7: Midi Channel ("midi")
	E4: Press: Toggles YPOS(cursorpos/channelColor) / MIDI (omnichannel)
	Touch Right or Left: EXIT

8:Transport ("trsp")
	E4: Press: Toggles ON / OFF for TOERN sending/receiving MIDI-play/pause signals
	Touch Right or Left: EXIT

9: PATTERN_MODE ("PMOD", >Matzemode")
	E4: Press: 	Toggles ON/OFF
	Touch Right or Left: EXIT

	* Patternmode ON just repeats the currently visible/active page in an pattern ;)

10: FLOW_MODE
	E4: Press: Toggles ON / OFF. 
	Touch Right or Left: EXIT

	* Flowmode ON always shows the active page while playing ("What you see is what you get")

11: Recording Button ("rec")
	E4: Press: Toggles between OFF / SENS / -CON / +CON
	Touch Right or Left: EXIT

	* SENS uses the touch sensor in front panel (defaultsetting)
	* -CON/+CON uses a connected footswitch ()

12: Clear ("clr") notes when recording
	E4: Press: Toggles between FIX / OFF / ON
	Touch Right or Left: EXIT

	* FIX uses the already set note triggers for recording (default setting)
	* ON does clear the patterns/page note triggers and sets a new trigger at the time/moment of recording
	* off doesnt add or delete any note triggers when record is touched/pressed

13: Preview-Volume
	E4: Press: Toggles LOW/MID/HIGH/SPLT
	Touch Right or Left: EXIT

	* how loud the preview of SAMPLE-Selection should play.
	* SPLT only uses the LEFT channel of the Audio, leaving ALL other SOUNDS of TOERN play on the RIGHT channel! 
	* SPLT enables to use "silent" preview routing in livesets

14: Live-Loop-Monitor-Volume
	E4: Press: Toggles OFF/LOW/MED/HIGH/FULL
	Touch Right or Left: EXIT

	* How loud the Recorded (MIC/LINE) INPUT should be routed to monitor.

15: Reset
	E4: Press: Resets all FILTERS (+Parameters/+FX,etc) of the Pattern do default. 
	Touch Right or Left: EXIT

	* Helps when sound is missing or distorted after a lot of action

16: Set (not ready yet)
	Touch Right or Left: EXIT

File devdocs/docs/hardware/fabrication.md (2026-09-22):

---
sidebar_position: 5
title: Fabrication
description: Gerbers, JLCPCB BOM/CPL, and how to open the KiCad project.
---

# Fabrication (rev H)

Maker steps (what to order, what is through-hole, first power) are in the repo-root [BUILD.md](../../../BUILD.md). This page is the file map.

## Open the design

1. Install a recent **KiCad** (7+; project files are `.kicad_pro` / `.kicad_sch` / `.kicad_pcb`).
2. Open [`PCB/toern_revH/toern_revH.kicad_pro`](../../../PCB/toern_revH/toern_revH.kicad_pro).
3. Project-local libraries are wired via `fp-lib-table` / `sym-lib-table` (`SJ1-3533`, `TPS22918DBVR`, `teensy`, …).

The Teensy 4.1 **symbol** is vendored at [`teensy/teensy.kicad_sym`](../../../PCB/toern_revH/teensy/teensy.kicad_sym) and `sym-lib-table` points at it with `${KIPRJMOD}`. The placed Teensy **footprint** is stored inside `toern_revH.kicad_pcb` (`myLibKicad:Teensy41`). That footprint library is not in the repo. Opening and ordering the board works from the embedded footprint. Updating the footprint from a library needs `myLibKicad` on your machine.

## Gerbers in-repo

| Export | Location |
|---|---|
| KiCad plot | [`PCB/toern_revH/Gerber/`](../../../PCB/toern_revH/Gerber) — Cu top/inner/bottom, mask, silk, paste, edge cuts, `.drl` |
| JLCPCB pack | [`PCB/toern_revH/jlcpcb/`](../../../PCB/toern_revH/jlcpcb) — `gerber/`, `production_files/` |

Stackup: **4 layers**, **1.6 mm**. The placed JLCPCB order Y12 (10 boards, top-side assembly) is written up in [`order-y12.html`](../../../PCB/toern_revH/jlcpcb/order-y12.html).

## JLCPCB SMT helpers

Under `jlcpcb/production_files/`:

| File | Use |
|---|-----|
| [`BOM-toern_revH.csv`](../../../PCB/toern_revH/jlcpcb/production_files/BOM-toern_revH.csv) | Comment / Designator / Footprint / LCSC / Qty |
| [`CPL-toern_revH.csv`](../../../PCB/toern_revH/jlcpcb/production_files/CPL-toern_revH.csv) | Component placement |
| `GERBER-toern_revH.zip` | Zipped gerbers for upload |

`fabrication-toolkit-options.json` stores KiCad Fabrication Toolkit plugin flags used when generating those exports.

### BOM highlights

Passives are in the CSV. Key ICs:

| Comment | Designators | LCSC (as exported) |
|---|---|---|
| BQ24075TRGTR | IC1 | C544783 |
| SGTL5000XNBA3 | U3 | C5196742 |
| SPX3819 3.3V | U1, U7 | C9055 |
| SPX3819 1.8V | U2 | C24639 |
| PAM8403D | U13 | C17337 |
| TLP2361 | U4 | C107626 |
| 74LVC2G14 | U5 | C12401 |
| USB-C | J4 | C165948 |
| microSD | J8 | C597972 |

Jacks, the switch, JST headers, encoder sockets, the Teensy sockets, pogo pins, the mic, and the 1000 µF cap are in the same CSV and are through-hole. The Teensy module, Duppa encoders, LED matrix, LiPo, speaker, and case are not in the CSV. Both lists are in [BUILD.md](../../../BUILD.md).

## Ordering checklist

1. Upload `GERBER-toern_revH.zip`.
2. Confirm 4-layer, 1.6 mm, and the silk/mask colors you want.
3. If using SMT assembly: upload BOM + CPL. Resolve codec / charger substitutions before paying.
4. Solder the through-hole parts. Seat the Teensy only after the 5 V and 3.3 V rails measure right.
5. Flash firmware ([info.md](../../../info.md)). Check USB, SD, headphone audio, one encoder, and the matrix on J9.

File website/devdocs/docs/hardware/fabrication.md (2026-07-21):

---
sidebar_position: 5
title: Fabrication
description: Gerbers, JLCPCB BOM/CPL, and how to open the KiCad project.
---

# Fabrication (rev G)

## Open the design

1. Install a recent **KiCad** (7+; project files are `.kicad_pro` / `.kicad_sch` / `.kicad_pcb`).  
2. Open [`PCB/toern_revG/toern_revG.kicad_pro`](https://github.com/Soundpauli/toern/blob/main/PCB/toern_revG/toern_revG.kicad_pro).  
3. Project-local libraries are wired via `fp-lib-table` / `sym-lib-table` (`SJ1-3533`, `TPS22918DBVR`, …).

:::warning Absolute path in sym-lib-table
`sym-lib-table` currently references a **machine-specific** Teensy symbol path (`D:/PCBs/myKicadLib/...`). On another computer, retarget the `teensy` symbol library or KiCad will show missing symbols for `U6`. Footprints for the Teensy may still resolve from the PCB cache / footprint libs.
:::

## Gerbers in-repo

| Export | Location |
|---|---|
| KiCad plot | [`PCB/toern_revG/Gerber/`](https://github.com/Soundpauli/toern/tree/main/PCB/toern_revG/Gerber) — Cu top/inner/bottom, mask, silk, paste, edge cuts, `.drl` |
| JLCPCB pack | [`PCB/toern_revG/jlcpcb/`](https://github.com/Soundpauli/toern/tree/main/PCB/toern_revG/jlcpcb) — `gerber/`, `production_files/` |

Stackup reminder: **4 layers**, **1.6 mm**.

## JLCPCB SMT helpers

Under `jlcpcb/production_files/`:

| File | Use |
|---|-----|
| [`BOM-toern_revG.csv`](https://github.com/Soundpauli/toern/blob/main/PCB/toern_revG/jlcpcb/production_files/BOM-toern_revG.csv) | Comment / Designator / Footprint / LCSC / Qty |
| [`CPL-toern_revG.csv`](https://github.com/Soundpauli/toern/blob/main/PCB/toern_revG/jlcpcb/production_files/CPL-toern_revG.csv) | Component placement |
| `GERBER-toern_revG.zip` | Zipped gerbers for upload |

`fabrication-toolkit-options.json` stores KiCad Fabrication Toolkit plugin flags used when generating those exports.

### BOM highlights (assembled on PCB)

Not a full shopping list — see the CSV for passives. Key ICs / connectors:

| Comment | Designators | LCSC (as exported) |
|---|---|---|
| BQ24075TRGTR | IC1 | C544783 |
| SGTL5000XNBA3 | U3 | C5196742 |
| SPX3819 3.3V | U1, U7 | C9055 |
| SPX3819 1.8V | U2 | C24639 |
| PAM8403D | U13 | C17337 |
| TLP2361 | U4 | C107626 |
| 74LVC2G14 | U5 | C12401 |
| USB-C | J4 | C165948 |
| microSD | J8 | C597972 |
| 6.35 mm jacks | J1, J5–J7 | C368502 |
| 3.5 mm jacks | J3, J17 | C4991776 |
| EG2219 switch | S1 | C3664594 |
| JST-PH headers | J9–J16, J11.5, … | various |
| Encoder pin sockets | J2, J18–J24 | C50950 |

**Teensy 4.1**, **encoder modules**, **LED matrices**, **LiPo**, and **case** are typically **not** in the JLCPCB PCB+SMT BOM — buy/assemble separately.

## Ordering checklist

1. Upload gerbers (JLCPCB zip or re-plot from KiCad).  
2. Confirm 4-layer, 1.6 mm, and silk/mask colors you want.  
3. If using SMT assembly: upload BOM + CPL; resolve any LCSC substitutions carefully (codec / charger footprints are unforgiving).  
4. Hand-stuff / socket: Teensy, encoders, matrices, battery, optional speaker.  
5. Flash firmware; verify USB, SD, audio loopback, encoder INT, battery ADC.

## Related revisions

- [`PCB/toern_revF/`](https://github.com/Soundpauli/toern/tree/main/PCB/toern_revF) — previous board revision  
- Prefer **rev G** for new builds unless you are maintaining an older unit

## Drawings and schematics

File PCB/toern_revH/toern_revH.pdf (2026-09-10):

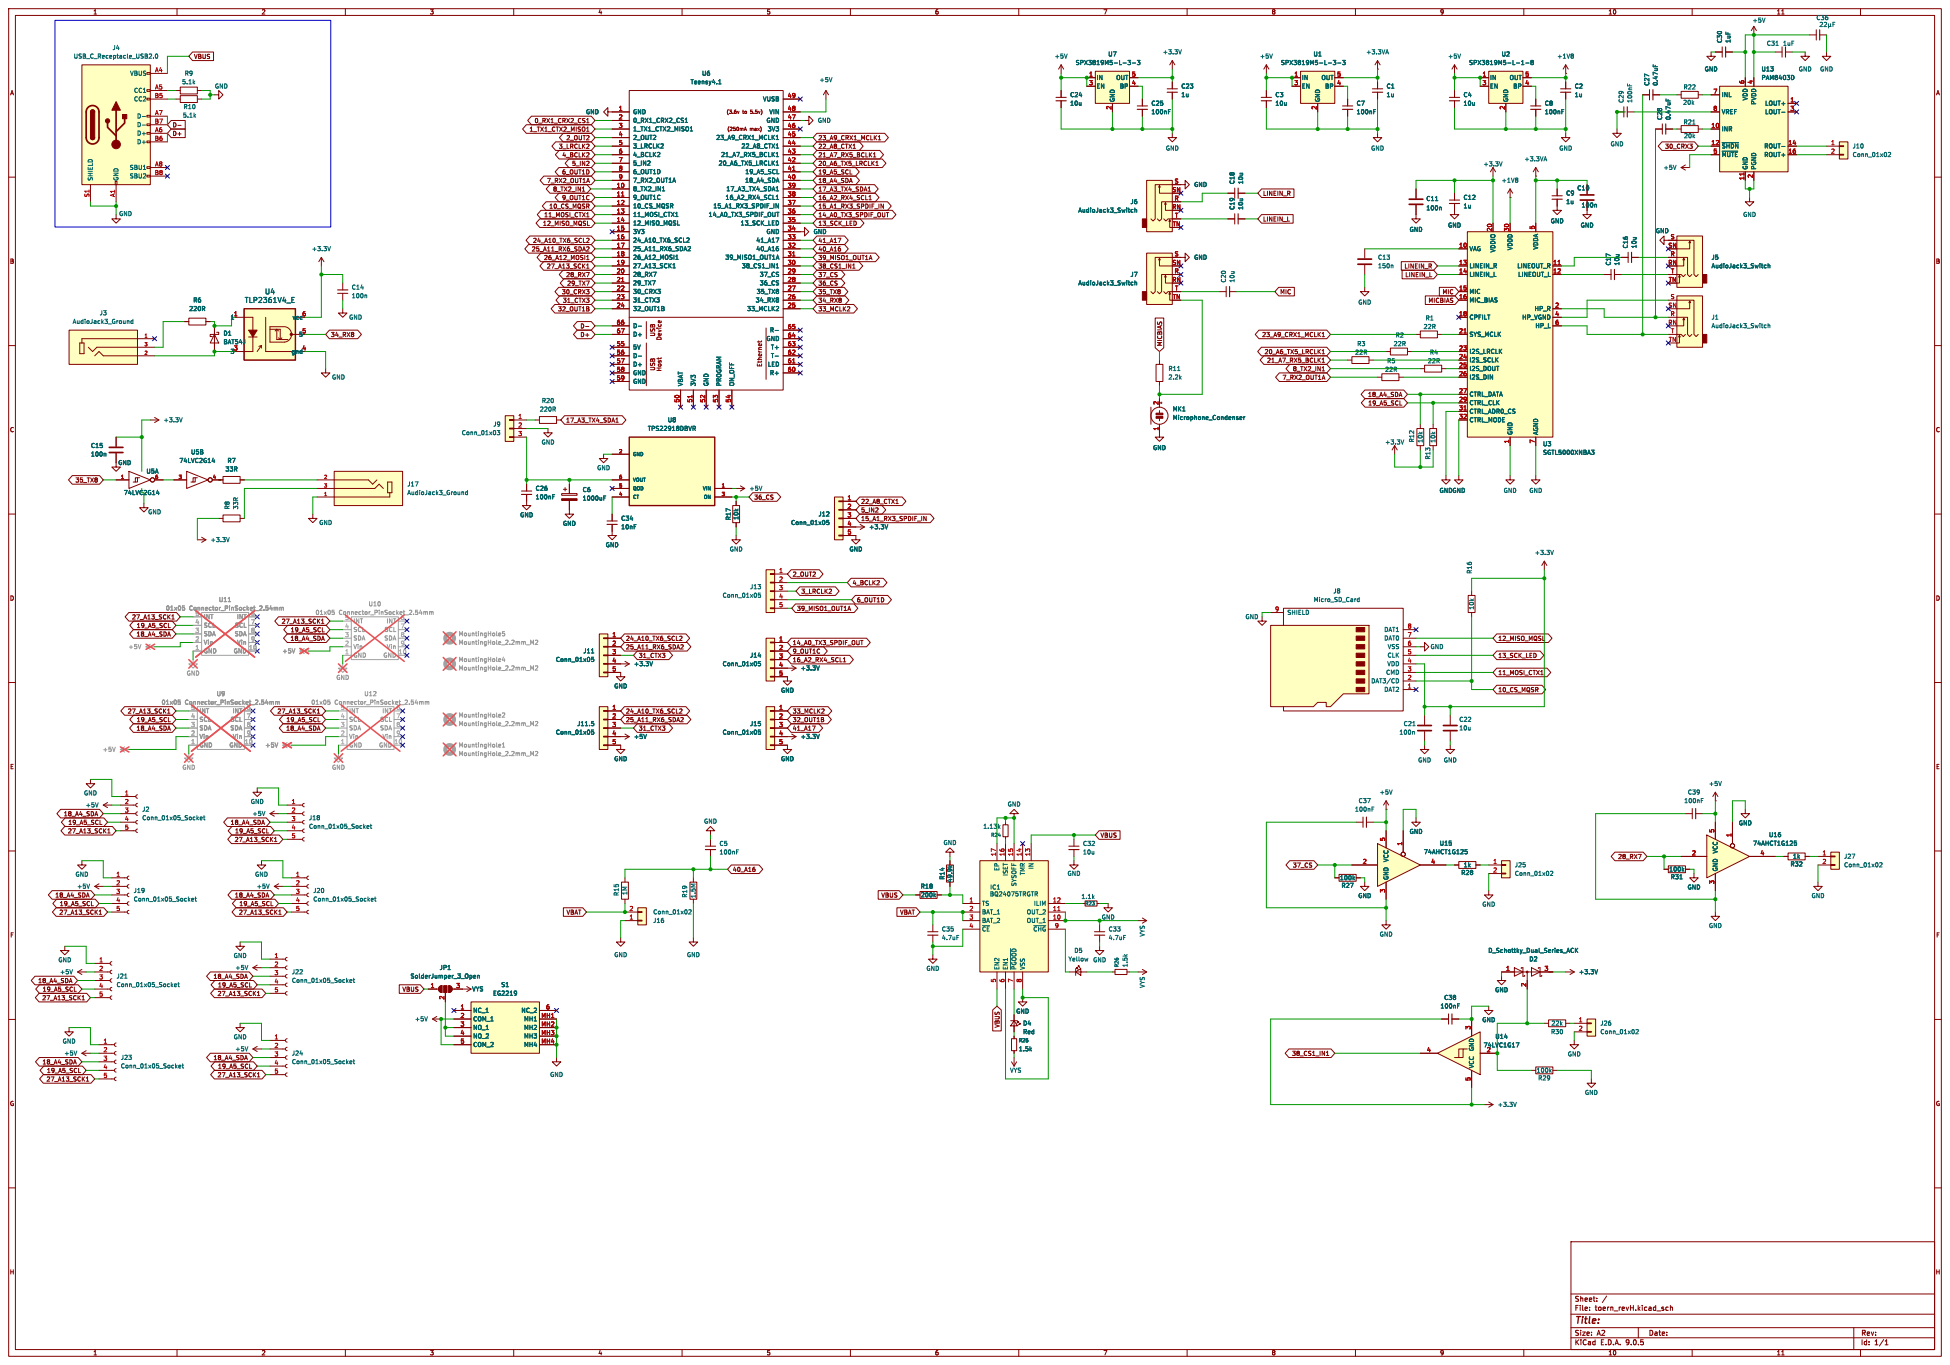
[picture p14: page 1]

22R USB USB Device Host

J13 Conn_01x05 GND
INT 6 SCL 7 SDA 8 Vin 9 GND 10 U11
INT 5 SCL 4 SDA 3 Vin 2 GND 1

INT 6 SCL 7 SDA 8 Vin 9 GND 10 U10

74AHCT1G125 GND

INT 6 SCL 7 SDA 8 Vin 9 GND 10 U9

INT 6 SCL 7 SDA 8 Vin 9 GND 10 U12

6 SYSOFF 15 ~{PGOOD} 7 TMR 14 VSS

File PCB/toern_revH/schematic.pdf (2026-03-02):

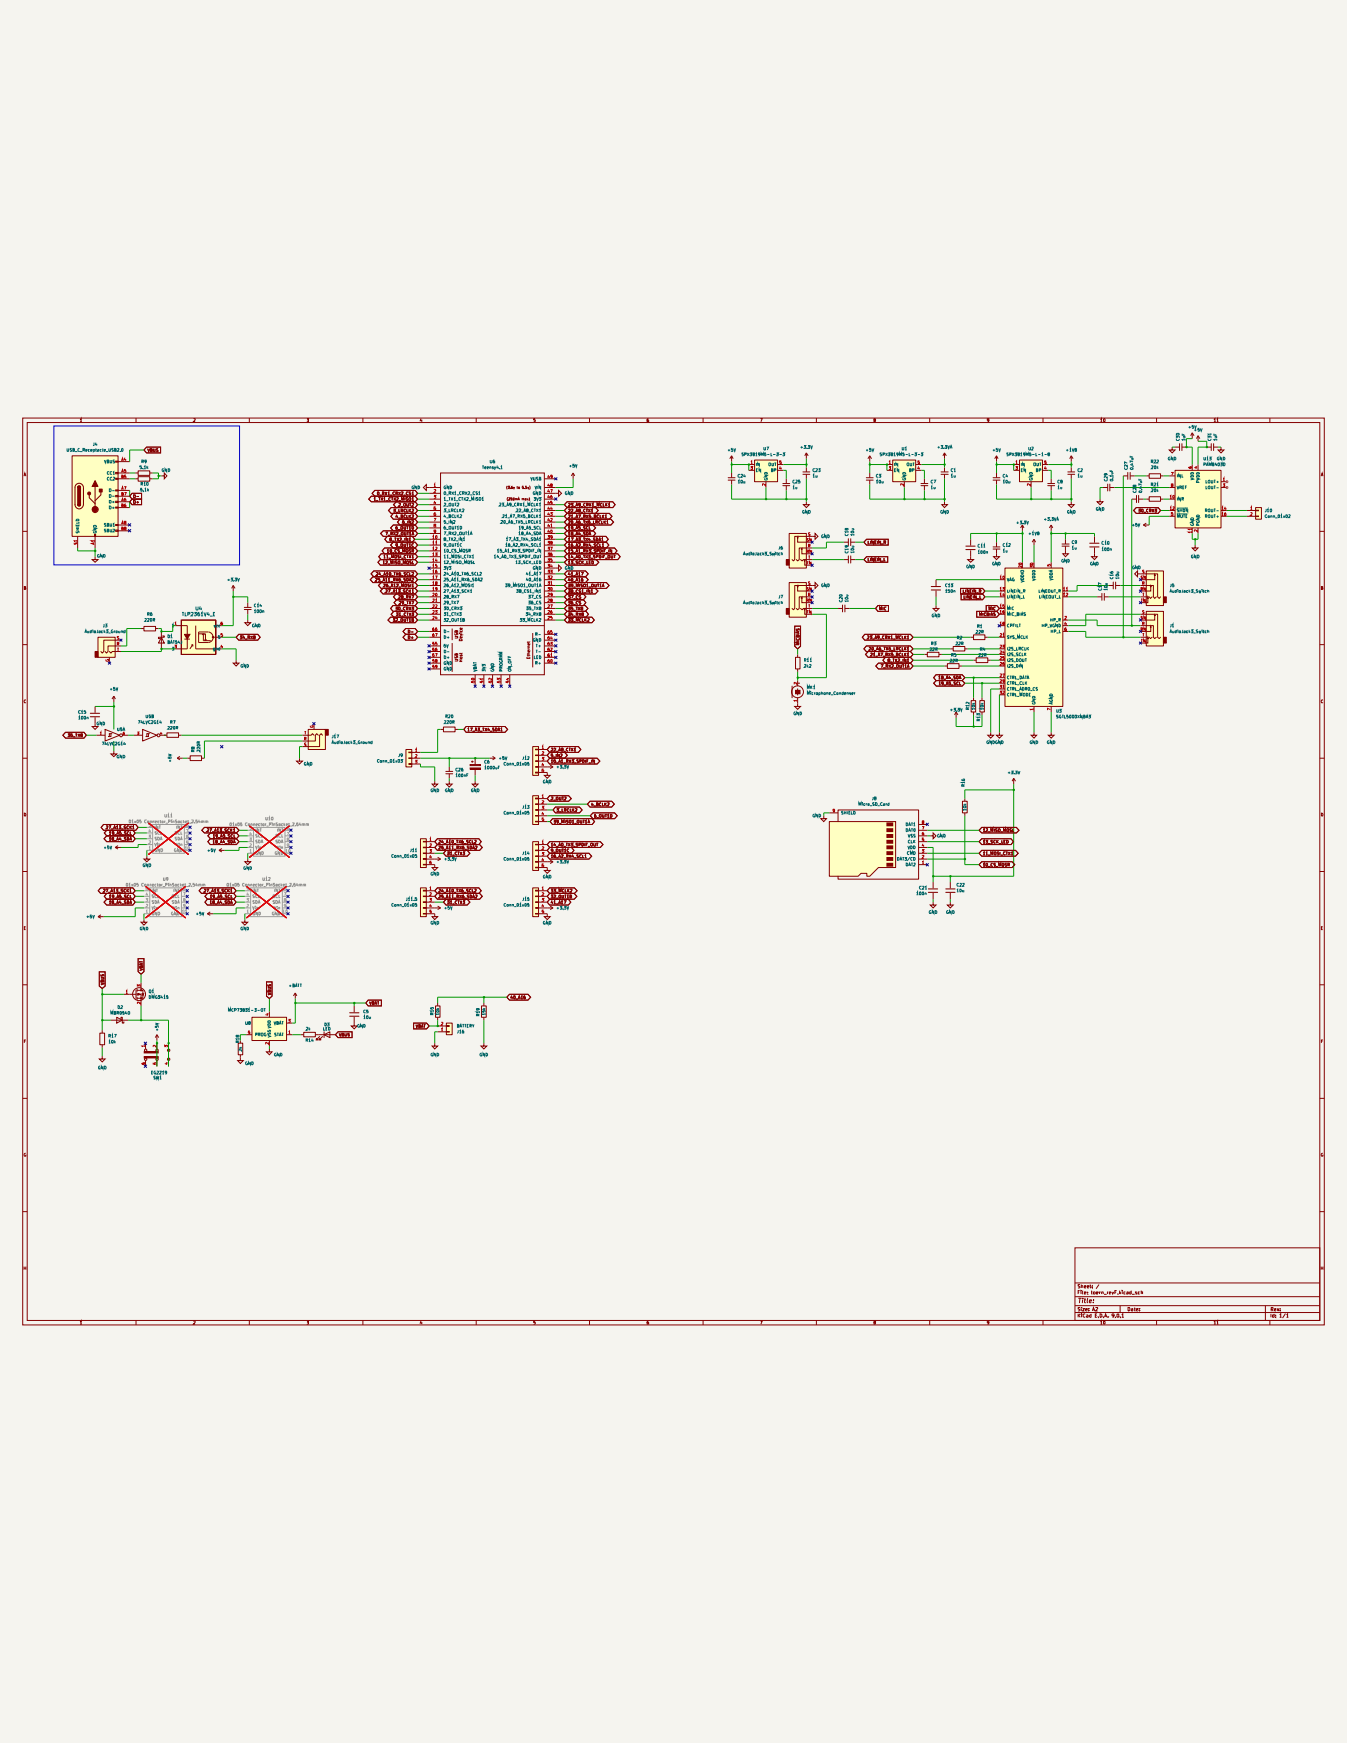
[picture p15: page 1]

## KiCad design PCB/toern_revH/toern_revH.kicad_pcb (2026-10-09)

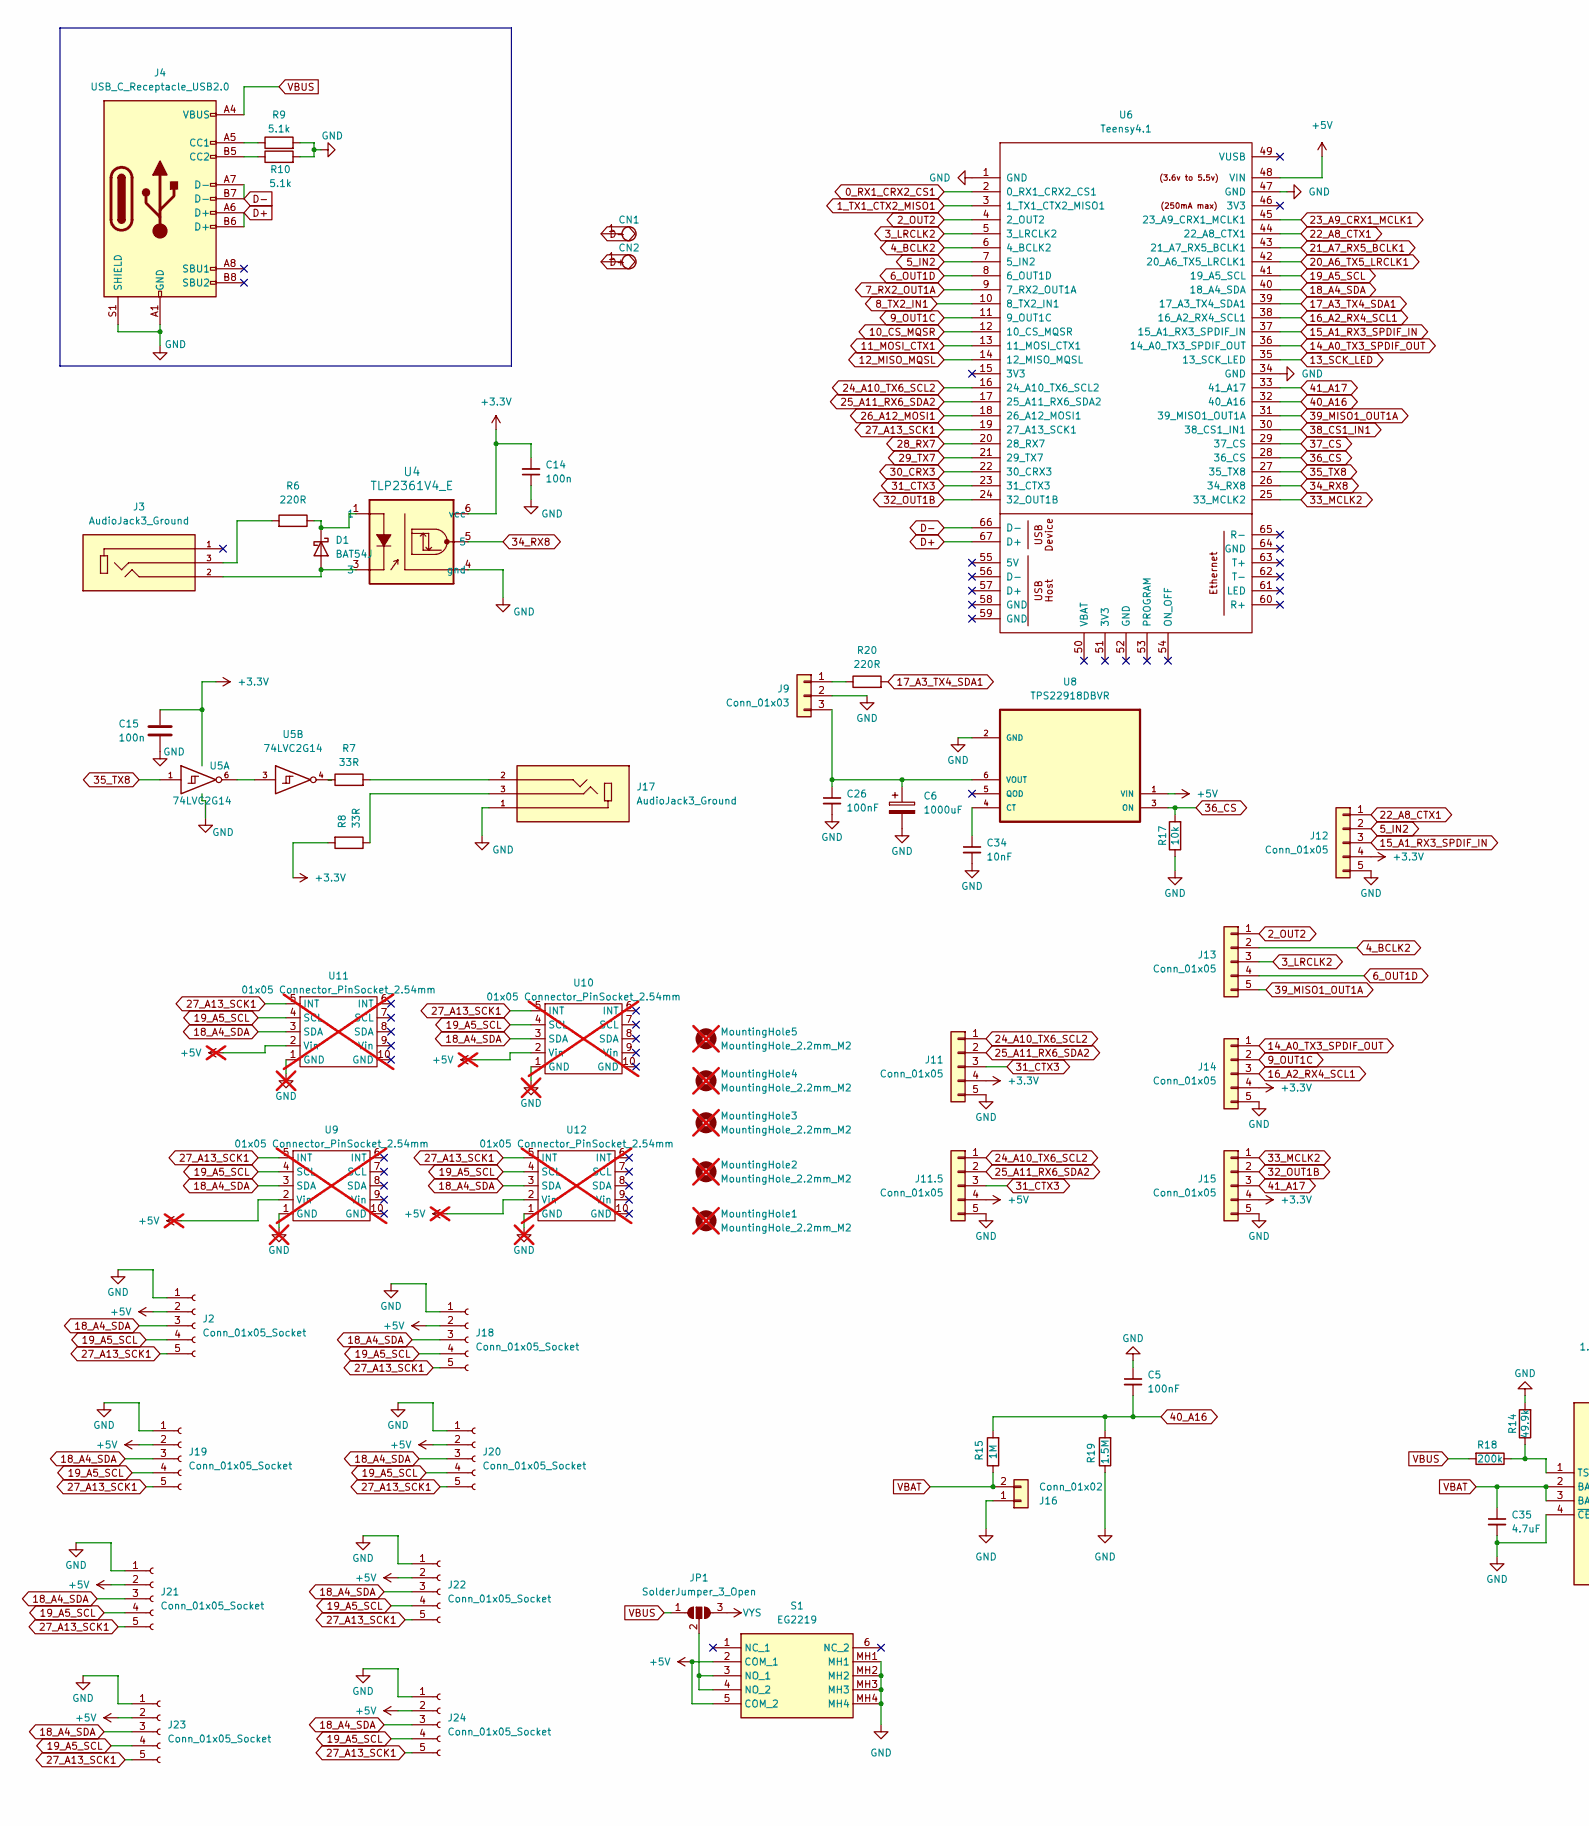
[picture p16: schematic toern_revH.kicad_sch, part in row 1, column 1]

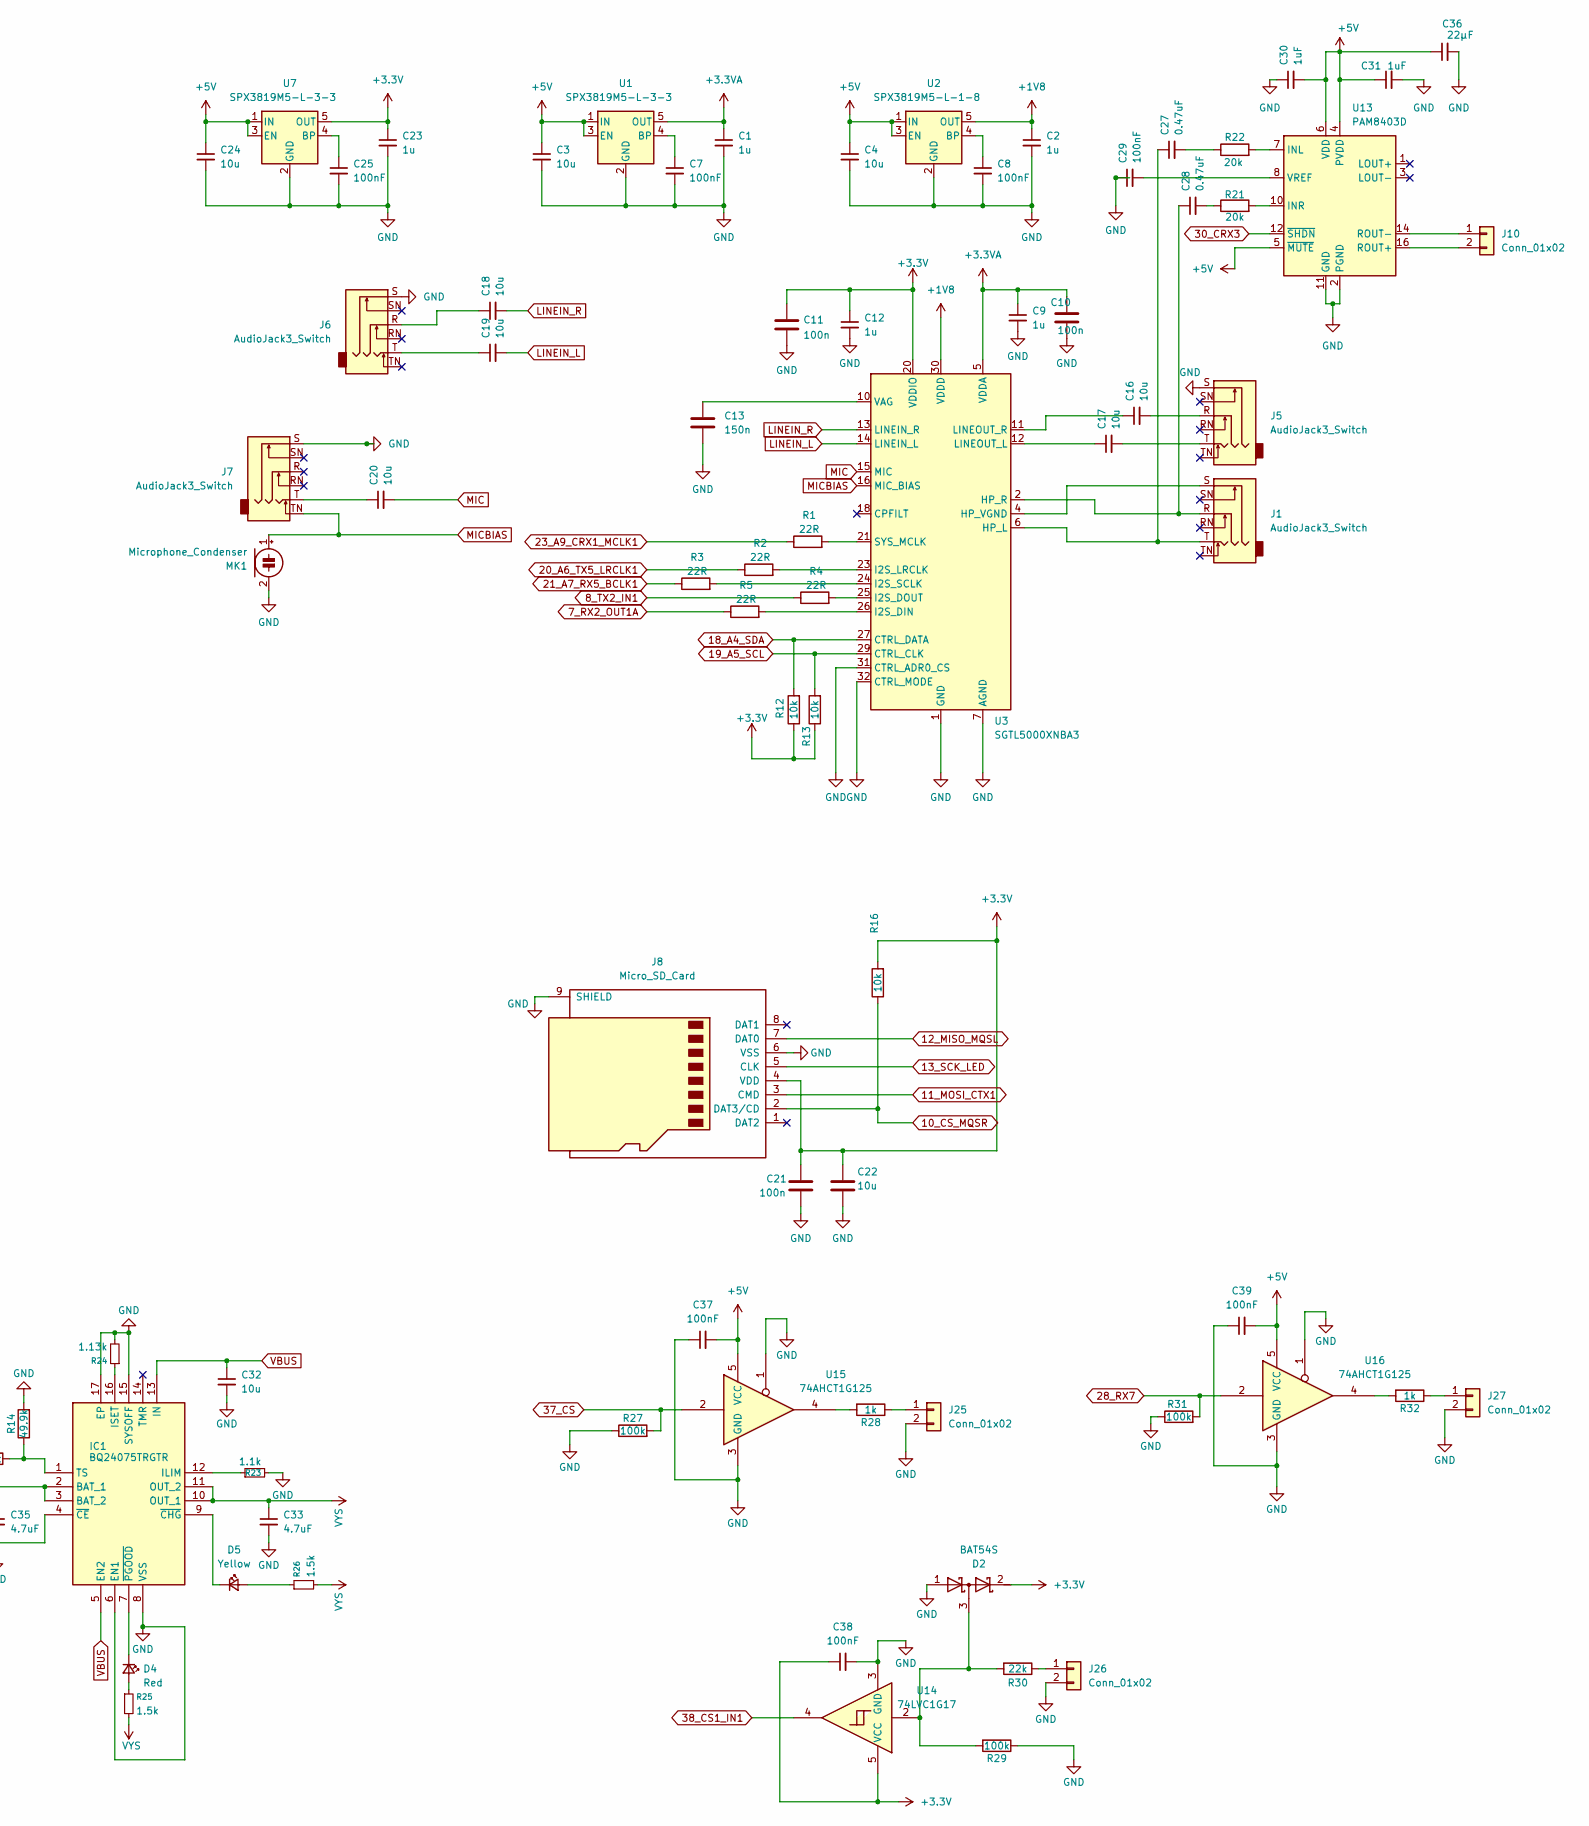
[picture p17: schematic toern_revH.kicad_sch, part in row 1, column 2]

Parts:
C1, C2, C9, C12, C23: 1u; C_0402_1005Metric; lcsc# C52923
C3, C4, C16, C17, C18, C19, C20, C22, C24, C32: 10u; C_0603_1608Metric; lcsc# C19702
C5, C26, C29: 100nF; C_0603_1608Metric; lcsc# C1590
C6: 1000uF; CP_Elec_8x10.5; lcsc# C5686929
C7, C8, C25, C37, C38, C39: 100nF; C_0402_1005Metric; lcsc# C1525
C10, C11: 100n; C_0402_1005Metric; MPN CC0603KRX7R6BB224; lcsc# C77020
C13: 150n; C_0402_1005Metric; lcsc# C162182
C14, C15, C21: 100n; C_0402_1005Metric; lcsc# C77020
C27, C28: 0.47uF; C_0603_1608Metric; lcsc# C1623
C30, C31: 1uF; C_0603_1608Metric; lcsc# C15849
C33, C35: 4.7uF; C_0603_1608Metric; lcsc# C1705
C34: 10nF; C_0402_1005Metric; lcsc# C15195
C36: 22µF; C_0603_1608Metric; lcsc# C59461
CN1, CN2: YZP0354-20100-01; MPN YZP0354-20100-01; lcsc# C5157282
D1: BAT54J; D_SOD-323F; lcsc# C130415
D2: BAT54S; SOT-23; lcsc# C171786
D4: Red; LED_0402_1005Metric; lcsc# C71911
D5: Yellow; LED_0402_1005Metric; lcsc# C74342
IC1: BQ24075TRGTR; QFN50P300X300X100-17N-D; Mouser Part Number 595-BQ24075TRGTR
J1, J5, J6, J7: AudioJack3_Switch; Jack_6.35mm_Neutrik_NMJ6HCD2_Horizontal; lcsc# C368502
J2, J18, J19, J20, J21, J22, J23, J24: Conn_01x05_Socket; PinSocket_1x05_P2.54mm_Vertical; lcsc# C50950
J3, J17: AudioJack3_Ground; CUI_SJ1-3533; PARTREV 1.01; lcsc# C4991776
J4: USB_C_Receptacle_USB2.0; USB_C_Receptacle_HRO_TYPE-C-31-M-12; lcsc# C165948
J8: Micro_SD_Card; microSD_HC_Hirose_DM3BT-DSF-PEJS; lcsc# C597972
J9: Conn_01x03; JST_PH_B3B-PH-K_1x03_P2.00mm_Vertical; lcsc# C131339
J10, J16, J25, J26, J27: Conn_01x02; JST_PH_B2B-PH-K_1x02_P2.00mm_Vertical; lcsc# C131337
J11, J11.5, J12, J13, J14, J15: Conn_01x05; JST_PH_B5B-PH-K_1x05_P2.00mm_Vertical; lcsc# C157993
JP1: SolderJumper_3_Open; SolderJumper-3_P1.3mm_Open_RoundedPad1.0x1.5mm
MK1: Microphone_Condenser; MIC-TH_BD6.0-P1.90-D0.4-L-FD; lcsc# C529951
MountingHole1, MountingHole2, MountingHole3, MountingHole4, MountingHole5: MountingHole_2.2mm_M2; not fitted
R1, R2, R3, R4, R5: 22R; R_0402_1005Metric; lcsc# C25092
R6, R20: 220R; R_0603_1608Metric; lcsc# C22962
R7, R8: 33R; R_0603_1608Metric; lcsc# C23140
R9, R10: 5.1k; R_0402_1005Metric; lcsc# C25905
R12, R13, R16, R17: 10k; R_0402_1005Metric; lcsc# C25744
R14: 49.9k; R_0402_1005Metric; lcsc# C100457
R15: 1M; R_0402_1005Metric; lcsc# C26083
R18: 200k; R_0402_1005Metric; lcsc# C25764
R19: 1.5M; R_0402_1005Metric; lcsc# C11812
R21, R22: 20k; R_0805_2012Metric; LCSC C4328
R23: 1.1k; R_0402_1005Metric; lcsc# C25860
R24: 1.13k; R_0402_1005Metric; lcsc# C166635
R25, R26: 1.5k; R_0402_1005Metric; lcsc# C25867
R27, R29, R31: 100k; R_0402_1005Metric; lcsc# C25741
R28, R32: 1k; R_0402_1005Metric; lcsc# C11702
R30: 22k; R_0402_1005Metric; lcsc# C25768
S1: EG2219; Mouser Part Number 612-EG2219
U1, U7: SPX3819M5-L-3-3; SOT-23-5; lcsc# C9055
U2: SPX3819M5-L-1-8; SOT-23-5; lcsc# C24639
U3: SGTL5000XNBA3; QFN-32-1EP_5x5mm_P0.5mm_EP3.6x3.6mm; lcsc# C5196742
U4: TLP2361V4_E; 5pin SO6_TOS; lcsc# C107626
U5: 74LVC2G14; SOT-23-6; LCSC Part # C12401
U6: Teensy4.1; Teensy41; lcsc# ----
U8: TPS22918DBVR; SOT95P280X145-6N; lcsc# C131941
U9, U10, U11, U12: 01x05 Connector_PinSocket_2.54mm; DuppaI2CEncoderV2.1; lcsc# C50950; not fitted
U13: PAM8403D; SOIC-16_3.9x9.9mm_P1.27mm; lcsc# C17337
U14: 74LVC1G17; SOT-23-5; lcsc# C7836
U15, U16: 74AHCT1G125; SOT-23-5; lcsc# C7484

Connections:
0_RX1_CRX2_CS1: U6.2 (0_RX1_CRX2_CS1)
1_TX1_CTX2_MISO1: U6.3 (1_TX1_CTX2_MISO1)
2_OUT2: J13.1, U6.4 (2_OUT2)
3_LRCLK2: J13.3, U6.5 (3_LRCLK2)
4_BCLK2: J13.2, U6.6 (4_BCLK2)
5_IN2: J12.2, U6.7 (5_IN2)
6_OUT1D: J13.4, U6.8 (6_OUT1D)
7_RX2_OUT1A: R5.1, U6.9 (7_RX2_OUT1A)
8_TX2_IN1: R4.1, U6.10 (8_TX2_IN1)
9_OUT1C: J14.2, U6.11 (9_OUT1C)
10_CS_MQSR: J8.2 (DAT3/CD), R16.1, U6.12 (10_CS_MQSR)
11_MOSI_CTX1: J8.3 (CMD), U6.13 (11_MOSI_CTX1)
12_MISO_MQSL: J8.7 (DAT0), U6.14 (12_MISO_MQSL)
13_SCK_LED: J8.5 (CLK), U6.35 (13_SCK_LED)
14_A0_TX3_SPDIF_OUT: J14.1, U6.36 (14_A0_TX3_SPDIF_OUT)
15_A1_RX3_SPDIF_IN: J12.3, U6.37 (15_A1_RX3_SPDIF_IN)
16_A2_RX4_SCL1: J14.3, U6.38 (16_A2_RX4_SCL1)
17_A3_TX4_SDA1: R20.2, U6.39 (17_A3_TX4_SDA1)
18_A4_SDA: J2.3, J18.3, J19.3, J20.3, J21.3, J22.3, J23.3, J24.3, R12.2, U3.27 (CTRL_DATA), U6.40 (18_A4_SDA), U9.3 (SDA), U10.3 (SDA), U11.3 (SDA), U12.3 (SDA)
19_A5_SCL: J2.4, J18.4, J19.4, J20.4, J21.4, J22.4, J23.4, J24.4, R13.2, U3.29 (CTRL_CLK), U6.41 (19_A5_SCL), U9.4 (SCL), U10.4 (SCL), U11.4 (SCL), U12.4 (SCL)
20_A6_TX5_LRCLK1: R2.1, U6.42 (20_A6_TX5_LRCLK1)
21_A7_RX5_BCLK1: R3.1, U6.43 (21_A7_RX5_BCLK1)
22_A8_CTX1: J12.1, U6.44 (22_A8_CTX1)
23_A9_CRX1_MCLK1: R1.1, U6.45 (23_A9_CRX1_MCLK1)
24_A10_TX6_SCL2: J11.1, J11.5.1, U6.16 (24_A10_TX6_SCL2)
25_A11_RX6_SDA2: J11.2, J11.5.2, U6.17 (25_A11_RX6_SDA2)
26_A12_MOSI1: U6.18 (26_A12_MOSI1)
27_A13_SCK1: J2.5, J18.5, J19.5, J20.5, J21.5, J22.5, J23.5, J24.5, U6.19 (27_A13_SCK1), U9.5 (INT), U10.5 (INT), U11.5 (INT), U12.5 (INT)
28_RX7: R31.2, U6.20 (28_RX7), U16.2
29_TX7: U6.21 (29_TX7)
30_CRX3: U6.22 (30_CRX3), U13.12 (~SHDN)
31_CTX3: J11.3, J11.5.3, U6.23 (31_CTX3)
32_OUT1B: J15.2, U6.24 (32_OUT1B)
33_MCLK2: J15.1, U6.25 (33_MCLK2)
34_RX8: U4.5, U6.26 (34_RX8)
35_TX8: U5.1, U6.27 (35_TX8)
36_CS: R17.2, U6.28 (36_CS), U8.3 (ON)
37_CS: R27.2, U6.29 (37_CS), U15.2
38_CS1_IN1: U6.30 (38_CS1_IN1), U14.4
39_MISO1_OUT1A: J13.5, U6.31 (39_MISO1_OUT1A)
40_A16: C5.2, R15.2, R19.2, U6.32 (40_A16)
41_A17: J15.3, U6.33 (41_A17)
+1V8: C2.1, U2.5 (OUT), U3.30 (VDDD)
+3.3V: C11.1, C12.1, C14.2, C15.1, C21.2, C22.1, C23.1, C38.1, D2.2 (K), J8.4 (VDD), J11.4, J12.4, J14.4, J15.4, R8.2, R12.1, R13.1, R16.2, U3.20 (VDDIO), U4.6 (vcc), U5.5 (VCC), U7.5 (OUT), U14.5 (VCC)
+3.3VA: C1.1, C9.1, C10.1, U1.5 (OUT), U3.5 (VDDA)
+5V: C3.1, C4.1, C24.1, C30.2, C31.1, C36.1, C37.2, C39.2, J2.2, J11.5.4, J18.2, J19.2, J20.2, J21.2, J22.2, J23.2, J24.2, S1.2 (COM_1), S1.5 (COM_2), U1.1 (IN), U1.3 (EN), U2.1 (IN), U2.3 (EN), U6.48 (VIN), U7.1 (IN), U7.3 (EN), U8.1 (VIN), U9.2 (Vin), U10.2 (Vin), U11.2 (Vin), U12.2 (Vin), U13.4 (PVDD), U13.5 (~MUTE), U13.6 (VDD), U13.13 (PVDD), U15.5 (VCC), U16.5 (VCC)
D+: CN2.1 (CONTACT), J4.A6 (D+), J4.B6 (D+), U6.67 (D+)
D-: CN1.1 (CONTACT), J4.A7 (D-), J4.B7 (D-), U6.66 (D-)
GND: C1.2, C2.2, C3.2, C4.2, C5.1, C6.2, C7.2, C8.2, C9.2, C10.2, C11.2, C12.2, C13.2, C14.1, C15.2, C21.1, C22.2, C23.2, C24.2, C25.2, C26.2, C29.1, C30.1, C31.2, C32.2, C33.2, C34.2, C35.2, C36.2, C37.1, C38.2, C39.1, D2.1 (A), IC1.4 (~CE), IC1.6 (EN1), IC1.8 (VSS), IC1.15 (SYSOFF), IC1.17 (EP), J2.1, J4.A1 (GND), J4.A12 (GND), J4.B1 (GND), J4.B12 (GND), J4.S1 (SHIELD), J5.S, J6.S, J7.S, J8.6 (VSS), J8.9 (SHIELD), J9.2, J11.5, J11.5.5, J12.5, J14.5, J15.5, J16.1, J17.1, J18.1, J19.1, J20.1, J21.1, J22.1, J23.1, J24.1, J25.2, J26.2, J27.2, MK1.2 (-), R9.2, R10.2, R14.2, R17.1, R19.1, R23.2, R24.2, R27.1, R29.1, R31.1, S1.MH1, S1.MH2, S1.MH3, S1.MH4, U1.2 (GND), U2.2 (GND), U3.1 (GND), U3.3 (GND), U3.7 (AGND), U3.31 (CTRL_ADR0_CS), U3.32 (CTRL_MODE), U3.33 (GND), U4.4 (gnd), U5.2 (GND), U6.1 (GND), U6.34 (GND), U6.47 (GND), U7.2 (GND), U8.2 (GND), U9.1 (GND), U10.1 (GND), U11.1 (GND), U12.1 (GND), U13.2 (PGND), U13.11 (GND), U13.15 (PGND), U14.3 (GND), U15.1, U15.3 (GND), U16.1, U16.3 (GND)
LINEIN_L: C19.2, U3.14 (LINEIN_L)
LINEIN_R: C18.2, U3.13 (LINEIN_R)
MIC: C20.2, U3.15 (MIC)
MICBIAS: J7.TN, MK1.1 (+), U3.16 (MIC_BIAS)
unnamed: C16.2, J5.R
unnamed: C17.2, J5.T
unnamed: C18.1, J6.R
unnamed: C19.1, J6.T
unnamed: C20.1, J7.T
unnamed: C27.2, R22.1
unnamed: C28.2, R21.1
unnamed: D1.2 (A), J3.2, U4.3
unnamed: D1.1 (K), R6.1, U4.1
unnamed: D2.3 (common), R29.2, R30.2, U14.2
unnamed: D4.2 (A), R25.1
unnamed: D4.1 (K), IC1.7 (~PGOOD)
unnamed: D5.2 (A), R26.1
unnamed: D5.1 (K), IC1.9 (~CHG)
unnamed: IC1.12 (ILIM), R23.1
unnamed: IC1.16 (ISET), R24.1
unnamed: IC1.1 (TS), R14.1, R18.1
unnamed: J3.3, R6.2
unnamed: J4.A5 (CC1), R9.1
unnamed: J4.B5 (CC2), R10.1
unnamed: J9.1, R20.1
unnamed: C6.1, C26.1, J9.3, U8.6 (VOUT)
unnamed: J10.1, U13.14 (ROUT-)
unnamed: J10.2, U13.16 (ROUT+)
unnamed: J17.2, R7.2
unnamed: J17.3, R8.1
unnamed: J25.1, R28.1
unnamed: J26.1, R30.1
unnamed: J27.1, R32.1
unnamed: JP1.2 (C), S1.3 (NO_1), S1.4 (NO_2)
unnamed: R7.1, U5.4
unnamed: R28.2, U15.4
unnamed: R32.2, U16.4
unnamed: C7.1, U1.4 (BP)
unnamed: C8.1, U2.4 (BP)
unnamed: C27.1, J1.T, U3.6 (HP_L)
unnamed: C28.1, J1.R, U3.2 (HP_R)
unnamed: J1.S, U3.4 (HP_VGND)
unnamed: R5.2, U3.26 (I2S_DIN)
unnamed: R4.2, U3.25 (I2S_DOUT)
unnamed: R2.2, U3.23 (I2S_LRCLK)
unnamed: R3.2, U3.24 (I2S_SCLK)
unnamed: C17.1, U3.12 (LINEOUT_L)
unnamed: C16.1, U3.11 (LINEOUT_R)
unnamed: R1.2, U3.21 (SYS_MCLK)
unnamed: C13.1, U3.10 (VAG)
unnamed: U5.3, U5.6
unnamed: C25.1, U7.4 (BP)
unnamed: C34.1, U8.4 (CT)
unnamed: R22.2, U13.7 (INL)
unnamed: R21.2, U13.10 (INR)
unnamed: C29.2, U13.8 (VREF)
VBAT: C35.1, IC1.2 (BAT_1), IC1.3 (BAT_2), J16.2, R15.1
VBUS: C32.1, IC1.5 (EN2), IC1.13 (IN), J4.A4 (VBUS), J4.A9 (VBUS), J4.B4 (VBUS), J4.B9 (VBUS), JP1.1 (A), R18.2
VYS: C33.1, IC1.10 (OUT_1), IC1.11 (OUT_2), JP1.3 (B), R25.2, R26.2

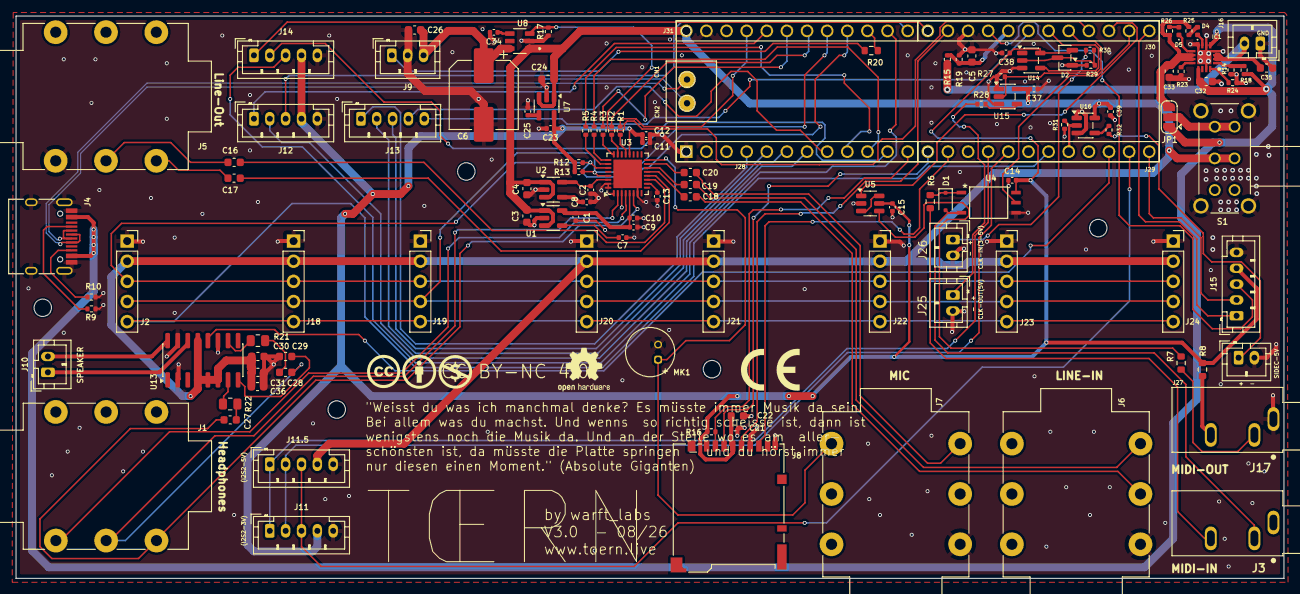
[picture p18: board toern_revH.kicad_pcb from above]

Board: 4 copper layers, 160.0 x 71.0 mm, 130 parts (0 on the bottom side), 104 nets.

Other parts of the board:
J28, J29, J30, J31: 929870-01-12-RA; 3M_929870-01-12-RA_Assembly
LOGOOPENHARDWARE: OSHW-Logo2_7.3x6mm_SilkScreen

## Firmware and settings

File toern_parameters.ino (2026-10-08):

// Forward declarations for ch11 polyphonic voice arrays (defined in toern_synths.ino).
extern uint16_t attackAmp[2][3];
extern uint16_t decayAmp[2][3];
extern float    sustainAmp[2][3];
extern uint16_t releaseAmp[2][3];
extern void     updateVals(int ch);

// Refactored: setParams combines processParameterAdjustment and updateParameterValue
void setParams(ParameterType paramType, int index) {

  float mappedValue;
  switch (paramType) {
    case ATTACK:
      mappedValue = mapf(SMP.param_settings[index][paramType], 0, maxfilterResolution, maxParamVal[ATTACK], 0);
      if (index == 11) {
        for (int v = 0; v < 3; v++) attackAmp[0][v] = (uint16_t)mappedValue;
        updateVals(0);
      } else {
        envelopes[index]->attack(mappedValue);
      }
      break;
    case DECAY:
      mappedValue = mapf(SMP.param_settings[index][paramType], 0, maxfilterResolution, 0, maxParamVal[DECAY]);
      if (index == 11) {
        for (int v = 0; v < 3; v++) decayAmp[0][v] = (uint16_t)mappedValue;
        updateVals(0);
      } else {
        envelopes[index]->decay(mappedValue);
      }
      break;
    /*case HOLD:
      mappedValue = mapf(SMP.param_settings[index][paramType], 0, maxfilterResolution, 0, maxParamVal[HOLD]);
      envelopes[index]->hold(mappedValue);
      break;*/
    case SUSTAIN:
      mappedValue = mapf(SMP.param_settings[index][paramType], 0, maxfilterResolution, 0, maxParamVal[SUSTAIN]);
      if (index == 11) {
        for (int v = 0; v < 3; v++) sustainAmp[0][v] = mappedValue;
        updateVals(0);
      } else {
        envelopes[index]->sustain(mappedValue);
      }
      break;
    case RELEASE:
      mappedValue = mapf(SMP.param_settings[index][paramType], 0, maxfilterResolution, 0, maxParamVal[RELEASE]);
      if (index == 11) {
        for (int v = 0; v < 3; v++) releaseAmp[0][v] = (uint16_t)mappedValue;
        updateVals(0);
      } else {
        envelopes[index]->release(mappedValue);
      }
      break;
  }
}


// Handle waveform changes
void handleWaveformChange(int index, unsigned int waveformType) {
  // Mono synth presets keep oscillator 2 as their contrasting layer.
  if (synths[index][0] != nullptr) {
    switch (waveformType) {
      case 1:
        synths[index][0]->begin(WAVEFORM_SINE);
        break;
      case 2:
        synths[index][0]->begin(WAVEFORM_SQUARE);
        break;
      case 3:
        synths[index][0]->begin(WAVEFORM_SAWTOOTH);
        break;
      case 4:
        synths[index][0]->begin(WAVEFORM_TRIANGLE);
        break;
      default: return;
    }
  }
}

// Set default filter values for a single channel
void setFiltersDefaultValues(int ch) {
  SMP.filter_settings[ch][HCUT] = 32;
  SMP.filter_settings[ch][LOWCUT] = 0;
  SMP.filter_settings[ch][REVERB] = 0;
  SMP.filter_settings[ch][BITCRUSHER] = 0;
  SMP.filter_settings[ch][DETUNE] = 16;
  SMP.filter_settings[ch][OCTAVE] = (ch >= 1 && ch <= 8) ? 24 : 16;
  // EFX setting: 0 = SAMPLE mode (default for all channels)
  SMP.filter_settings[ch][EFX] = 0;

  setFilters(HCUT, ch, true);
  setFilters(LOWCUT, ch, true);
  setFilters(REVERB, ch, true);
  setFilters(BITCRUSHER, ch, true);
  setFilters(DETUNE, ch, true);
  setFilters(OCTAVE, ch, true);
  // EFX parameter doesn't need setFilters call - it's just a control parameter
  initSliders(filterPage[GLOB.currentChannel],GLOB.currentChannel);
  updateSynthVoice(11);
}


// Unified ADSR slider defaults (0..maxfilterResolution): A=32, D=32, S=32, R=0
static void applyDefaultAdsrSettings(int ch) {
  SMP.param_settings[ch][ATTACK] = 32;
  SMP.param_settings[ch][DECAY] = 32;
  SMP.param_settings[ch][SUSTAIN] = 32;
  SMP.param_settings[ch][RELEASE] = 0;
  setParams(ATTACK, ch);
  setParams(DECAY, ch);
  setParams(SUSTAIN, ch);
  setParams(RELEASE, ch);
}

// Set default envelope values for a single channel
//ASDR
void setEnvelopeDefaultValues(int ch) {
  applyDefaultAdsrSettings(ch);
  initSliders(filterPage[GLOB.currentChannel],GLOB.currentChannel);
  updateSynthVoice(11);
}
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

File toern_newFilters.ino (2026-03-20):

extern const uint8_t filterPageCount[NUM_CHANNELS];
extern uint8_t filterPage[NUM_CHANNELS];

// Defined in toern_parameters.ino — resets CUT/RES/FLT/SEMI/CENT/FORM when ch11 instrument changes.
void applySynthInstrumentPreset(int channel, int instrumentIdx);

static bool channelHasFreeverb(uint8_t chan) {
  return !(chan == 3 || chan == 4);
}

// With drum sliders removed, filter pages remain static.
static bool updateFilterPageAvailability(uint8_t /*chan*/) { return false; }
DMAMEM unsigned long lastEncoderChange[4] = { 0, 0, 0, 0 };

int8_t lastChangedEncoder = -1;
DMAMEM unsigned long lastInteraction = millis();  // global timestamp
const unsigned long FILTER_INTERACTION_TIMEOUT = 1000; // ms before reverting to initial view


bool showingAny = false;
DMAMEM bool showSingleFilter[4] = { false, false, false, false };

static inline bool isWideFilterView2B() {
  extern int ledModules;
  extern bool ledModulesRotated;
  return (ledModules == 2 && ledModulesRotated && maxX > MATRIX_WIDTH);
}

static inline void getFilterSliderCols(uint8_t sliderIndex, uint8_t &x0, uint8_t &x1) {
  if (isWideFilterView2B()) {
    // 2B fine layout across 32px:
    // col1 one px right, col4 one px left -> [5,6], [12,13], [20,21], [27,28]
    static const uint8_t wideCols[4][2] = {
      { 5, 6 }, { 12, 13 }, { 20, 21 }, { 27, 28 }
    };
    uint8_t idx = (sliderIndex < 4) ? sliderIndex : 3;
    x0 = wideCols[idx][0];
    x1 = wideCols[idx][1];
  } else {
    x0 = sliderCols[sliderIndex][0];
    x1 = sliderCols[sliderIndex][1];
  }

  if (x0 < 1) x0 = 1;
  if (x1 < x0) x1 = x0;
  if (x1 > maxX) x1 = maxX;
}


uint8_t scaleToDisplay(const SliderDefEntry& meta, uint8_t val) {
  return (meta.displayRange < meta.maxValue) ? constrain(mapf(val, 0, meta.maxValue, 0, meta.displayRange - 1), 0, meta.displayRange - 1) : val;
}

uint8_t scaleFromDisplay(const SliderDefEntry& meta, uint8_t val) {
  return (meta.displayRange < meta.maxValue) ? constrain(mapf(val, 0, meta.displayRange - 1, 0, meta.maxValue), 0, meta.maxValue) : val;
}


#define MAX_FILTER_RESOLUTION 32.0
#define FILTER_BYPASS MAX_FILTER_RESOLUTION
#define FILTER_WET 0
#define FILTER_MID (MAX_FILTER_RESOLUTION / 2)
#define PARAM_COUNT 6  // Number of valid params, must include RELEASE (index 5)

// Read raw 0..MAX_FILTER_RESOLUTION setting directly
uint8_t readSetting(SettingArray arr, int8_t idx, uint8_t chan) {
  //if (idx < 0) return 0;
  uint8_t raw = 0;
  switch (arr) {
    case ARR_FILTER: raw = constrain(SMP.filter_settings[chan][idx], 0, MAX_FILTER_RESOLUTION); break;
    case ARR_SYNTH: raw = constrain(SMP.synth_settings[chan][idx], 0, MAX_FILTER_RESOLUTION); break;
    case ARR_PARAM: raw = constrain(SMP.param_settings[chan][idx], 0, MAX_FILTER_RESOLUTION); break;
    default: return 0;
  }
  return raw;
}


// 2) Helper to draw the name centered at y=10
void drawSliderName(uint8_t x0, uint8_t x1, const char* name, CRGB filtercol) {
  /*int len = strlen(name);
  const uint8_t charW = 3;
  int totalW = charW * len;
  int cx = (x0 + x1) / 2;
  int tx = cx - totalW/2;
  if (tx < 0)           tx = 0;
  if (tx + totalW > 16) tx = 16 - totalW;*/

  // CLEAR just that span on row 10
  for (int x = 1; x <= (int)maxX; ++x) {
    light(x, 12, CRGB::Black);
    light(x, 13, CRGB::Black);
    light(x, 14, CRGB::Black);
    light(x, 15, CRGB::Black);
    light(x, 16, CRGB::Black);
  }

  int textPixelWidth = 0;
  for (int i = 0; name[i] != '\0'; ++i) {
    if (name[i] >= 32 && name[i] <= 126) {
      textPixelWidth += alphabet[name[i] - 32][0] + 1;
    }
  }

  // Center on full width, rounding up when center is fractional.
  int tx = ((int)maxX - textPixelWidth + 3) / 2;
  if (tx < 1) tx = 1;
  if (tx + textPixelWidth - 1 > (int)maxX) tx = (int)maxX - textPixelWidth + 1;
  if (tx < 1) tx = 1;
  drawText(name, tx, 12, filtercol);
}



void drawCornerValueCustom(uint8_t encoderIndex, uint8_t val, const SliderDefEntry& meta) {
  // Special case: Channel 11 WAVE slider (encoder 0) should be at x=6
  uint8_t chan = GLOB.currentChannel;
  uint8_t x;

  bool dualPanel = isWideFilterView2B();

  if (dualPanel) {
    // In 2/2B modes, keep value near the active slider (not at display edges):
    // left pair -> +4px from right slider edge, right pair -> -4px from left slider edge.
    uint8_t sx0, sx1;
    getFilterSliderCols(encoderIndex, sx0, sx1);
    int desiredX = (encoderIndex < 2) ? ((int)sx1 + 4) : ((int)sx0 - 10);
    x = (uint8_t)constrain(desiredX, 1, (int)maxX - 6);
  } else if (chan == 11 && encoderIndex == 0 && meta.arr == ARR_FILTER && meta.idx == FILTER_WAVEFORM) {
    x = 6;
  } else {
    x = (encoderIndex < 2) ? 10 : 2;
  }
  const uint8_t y = 5;
  const uint8_t w = 6, h = 7;

  // Clear background
  for (uint8_t dx = 0; dx <= w; ++dx) {
    for (uint8_t dy = 0; dy < h; ++dy) {
      light(x + dx, y + dy - 1, CRGB::Black);
    }
  }

  char buf[4];
  uint8_t shownVal = scaleToDisplay(meta, val);

  if (meta.displayMode == DISPLAY_ENUM && shownVal < meta.displayRange && meta.enumNames && meta.enumNames[shownVal]) {
    snprintf(buf, sizeof(buf), "%s", meta.enumNames[shownVal]);
  } else {
    snprintf(buf, sizeof(buf), "%u", shownVal);
  }

  // ─── Color according to value ───
  CRGB baseColor = filterColors[filterPage[chan]][encoderIndex];
  CRGB dimmed = baseColor;
  dimmed.nscale8(64);
  uint8_t blendVal = mapf(val, 0, meta.maxValue, 0, 255);
  CRGB textColor = blend(CRGB::Red, CRGB::Green, blendVal);

  drawText(buf, x, y, textColor);
}
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

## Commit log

2025-01-19 added changes from NI404 for new PCB, added final PCB
    [BOM.csv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]
2025-01-26 updated code, fixed nullptr errors, added filters
    [BOM.csv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]
2025-02-03 starting adsr implementation + bugfixing
    [ResamplingReader.h]
2025-02-07 cleaning up files
    [BOM.csv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]
2025-02-17 fixed sample-splicing
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2025-03-25 fixed filters and bugfixes plus menu
    [toern_fileoperations.ino, toern_helpers.ino, toern_ui.ino]
2025-03-28 fixed sample loading and editing
    [toern_sample.ino, toern_ui.ino]
2025-03-29 fixed midi In Clock
    [toern_midi.ino, toern_sample.ino, toern_ui.ino]
2025-03-29 fixed midi in and out
    [toern_midi.ino]
2025-04-11 further fixed for filters and voices
    [toern_fileoperations.ino, toern_sample.ino, toern_synths.ino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]
2025-04-16 more fixes for synths and freqs
    [toern_fileoperations.ino, toern_filter.ino, toern_helpers.ino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]
2025-04-24 more bugfixes and features
    [toern_fileoperations.ino, toern_filter.ino, toern_midi.ino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]
2025-04-26 fixed sample cutting
2025-04-29 fixed sampler and midi + ui
    [toern_midi.ino, toern_sample.ino, toern_ui.ino]
2025-05-11 bugfixes and delay timings
    [toern_parameters.ino, toern_synths.ino]
2025-05-20 added touch and realtime recording
    [BOM.csv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]
2025-05-23 fixed BPM calculations for midi
    [toern_fileoperations.ino, toern_helpers.ino, toern_midi.ino]
2025-05-24 fixed settings and menu
    [toern_helpers.ino, toern_menu.ino, toern_midi.ino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]
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2025-06-17 fixed playback and midi
    [resamplerReader.h, toern_fileoperations.ino, toern_filter.ino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]
2025-07-07 flattend audio setup, fixed bugs with memory during play
    [toern_filter.ino, toern_sample.ino, toern_ui.ino]
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2025-09-18 bugfixes and added filters
    [toern_fileoperations.ino, toern_filter.ino, toern_helpers.ino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]
2025-09-19 bugfixes for encoderlights and midi
    [toern_fileoperations.ino, toern_menu.ino, toern_sample.ino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]
2025-10-04 more bugfixes and some features
    [toern_fileoperations.ino, toern_menu.ino, toern_newFilters.ino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]
2025-10-18 further bugfixes
    [BOM-toern_revE.csv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]
2025-10-18 fixing samplepack saving
2025-10-18 fixing sampl search and midi mode
    [toern_menu.ino, toern_midi.ino, toern_sample.ino]
2025-10-18 added reverse samples
2025-10-22 added fix for multiple panels
    [toern_menu.ino, toern_midi.ino, toern_ui.ino]
2025-10-23 adding fixes for eepromcrash
    [toern_fileoperations.ino, toern_helpers.ino, toern_menu.ino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]
2025-10-25 fixed reset and memory
    [toern_fileoperations.ino, toern_filter.ino, toern_helpers.ino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]
2025-10-28 back to working version after memory/pong fail
    [toern_helpers.ino, toern_menu.ino, toern_midi.ino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]
2025-11-08 memory opt and bugfixes
    [toern_menu.ino, toern_newFilters.ino, toern_sample.ino]
2025-11-15 fixed midi sync and transport
    [toern_menu.ino, toern_midi.ino]
2025-11-25 fixed midi finally + autosave fix
    [toern_fileoperations.ino]
2025-11-26 fixed button debounce 30ms ghostplaypause
2025-11-27 fixed button debounce 30ms ghostplaypause 2
    [toern_menu.ino]
2025-11-30 fixed memory issues with large samples
    [toern_fileoperations.ino, toern_newFilters.ino, toern_sample.ino]
2025-12-01 fixed overflows on long runs
    [toern_newFilters.ino, toern_sample.ino]
2025-12-06 fixes for ram1, freeverbs and more
    [toern_filter.ino, toern_menu.ino, toern_midi.ino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]
2025-12-06 fixes for ch11 fastfilter
    [toern_filter.ino]
2025-12-06 fixes for midi channels and loudness
    [toern_sample.ino]
2025-12-06 fixed synth voices, removed DRUMS
    [toern_filter.ino, toern_helpers.ino, toern_midi.ino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]
2025-12-14 performance fix and filenames
    [toern_fileoperations.ino, toern_filter.ino, toern_helpers.ino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]
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2025-12-22 further fixes for menu
    [resamplerReader.h, toern_filter.ino, toern_menu.ino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]
2025-12-27 fixed samplebrowsing for large files
    [toern_helpers.ino, toern_menu.ino, toern_sample.ino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]
2025-12-27 fixed samplerates
2025-12-27 fix for ch11 bounds
    [toern_menu.ino, toern_synths.ino]
2025-12-28 added error logging to sd2
    [toern_menu.ino, toern_synths.ino]
2026-01-23 varoious fixes in stability
    [BOM-toern_revE.csv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]
2026-01-23 reverted some fixes again
    [toern_helpers.ino, toern_leds.ino, toern_menu.ino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]
2026-01-23 fixed timer display flickering
    [toern_ui.ino]
2026-01-26 fixed sample preview and loader
    [toern_sample.ino, toern_ui.ino]
2026-01-26 fixed sample preview and loader2
    [toern_ui.ino]
2026-02-20 various fixes
    [toern_revE.kicad_pcb, toern_revE.kicad_sch, toern_revF.kicad_pcb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]
2026-02-20 clean up kiCad Files
    [BOM-toern_revE.csv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]
2026-02-20 pcb: locking unmovable parts
    [toern_revF.kicad_pcb]
2026-02-20 pcb: fixing thermal relief
    [toern_revF.kicad_pcb]
2026-03-02 more fixes
    [BQ24075TRGTR.SchLib, BQ24075TRGTR.stp, DMG3415UFY4Q-7.stp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]
2026-03-09 fixes for HD Displays 32x16
    [toern_revG.kicad_pcb, toern_revG.kicad_sch]
2026-03-12 extended reverb and muteAll fix for Draw==R
    [BOM-toern_revG.csv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]
2026-03-12 fixed PCB and shematics for RevG
    [BOM-toern_revG.csv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]
2026-03-12 fixed PCB and shematics for RevG 2
    [BOM-toern_revG.csv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]
2026-03-13 fixed brightnesssettings on load and save
    [toern_fileoperations.ino, toern_helpers.ino, toern_menu.ino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]
2026-03-13 fixed menu and filter touch crashes
    [toern_filter.ino, toern_menu.ino, toern_newFilters.ino]
2026-03-17 fix for sampledirection and mutes
    [toern_helpers.ino, toern_menu.ino]
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2026-03-17 fix for midi sync external transport
    [toern_menu.ino, toern_midi.ino]
2026-03-23 fixed midi ch13+14 release
    [toern_midi.ino]
2026-03-23 fixed ch13+14 filters+pass defaults
    [toern_filter.ino, toern_helpers.ino, toern_parameters.ino]
2026-03-23 fix long press ch11
    [toern_midi.ino]
2026-03-23 fixed CRF settings for ch11
    [toern_helpers.ino]
2026-03-23 fixed midi input ch13+14
    [toern_midi.ino]
2026-03-24 fixed pitch for c13+14
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2026-03-26 better loading and saving speed and progress
    [SJ1-3533.step, toern_revG.kicad_pcb, toern_revG.kicad_sch]
2026-04-08 pre-plan:sync issues
    [BOM-toern_revG.csv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]
2026-05-06 small fixes in code, additional TPS22918DBVR for PCB (leds)
    [TPS22918DBVR.step, toern_revG.kicad_pcb, toern_revG.kicad_sch]
2026-05-09 fixed audio/pack loading and handling, also added eyes screensaver
    [toern_revF.kicad_pcb, toern_revG.kicad_pcb]
2026-05-09 fixed defaults for eeprom
    [toern_fileoperations.ino, toern_helpers.ino, toern_menu.ino]
2026-05-11 fixed PCB: right resistors for TS + componentsize
    [toern_helpers.ino]
2026-05-11 fixed PCB: right resistors for TS + componentsize - final
    [toern_revG.kicad_pcb, toern_revG.kicad_sch]
2026-05-21 fixed battery display and final bugfixes for 2.2
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2026-07-04 fixed samplestructure
2026-07-16 bugfixes, stability and audio quality patches
    [toern_fileoperations.ino, toern_filterUI.ino, toern_helpers.ino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]
2026-07-16 Clean up project folder layout and tooling.
    Drop the oversized SD-CARD-CONTENT.zip from history so the push stays under GitHub's 100MB file limit.
    [BOM-toern_revE.csv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]
2026-07-21 Move Docusaurus app to website/devdocs for Netlify base=website
    Netlify builds inside website/, so ../devdocs was outside the tree.
    Keep the docs app next to package.json and track it via gitignore exceptions.
2026-07-21 Document host-side tools in Docusaurus
    Add pages for sample converter, MIDI convert, SD tool, firmware loader, color scheme editor, and annotate helper.
2026-07-26 almost done
    [TOERN_M1_FINAL.dxf]
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2026-08-18 fix case generator
2026-08-27 Clamp PAGE encoder to legal pages and read pins 5/22 as GND buttons.
    LEDS 2/2B only fit eight 32-step pages in 256 steps, so encoder 2 no longer uses maxX*4 (which walked note[] off the array). Buttons A/B are INPUT_PULLUP, pressed LOW.
    [toern_filterUI.ino]
2026-08-28 various stabilsation fixes, faders now use velocity
    [toern_fileoperations.ino, toern_helpers.ino, toern_menu.ino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]
2026-08-29 changed R14 and R18 to 200Ohm/49.9k
    [toern_revG.kicad_pcb, toern_revG.kicad_sch]
2026-09-09 new hardware: revH fixing loading issues and adding hardware clock
    [BOM-toern_revE.csv, BOM-toern_revG.csv, BQ24075TRGTR.SchLib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]
2026-09-09 fixed production files for revH
    [BOM-toern_revH.csv, toern_revF_kicad_pcb.kicad_pcb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]
2026-09-10 added protection for 5-12v clock input as well as 2nd clockout
    [BOM-toern_revH.csv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]
2026-09-11 added pogo pins and connectors to pcv revH
    [BOM-toern_revH.csv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]
2026-09-11 Add PlatformIO Teensy build and make mute-mode random preview use the SD scan index.
    Pin the Arduino-compatible sampler libraries, stop live SD walks on encoder ticks (eDMA crashes), and keep encoder-2 hold from being treated as a stuck button so random load still works.
    [toern_helpers.ino, toern_menu.ino, toern_sample.ino]
2026-09-12 further stabilisation fixes and new startup
    [toern_revH-B_Cu.gbl, toern_revH-B_Mask.gbs, toern_revH-B_Paste.gbp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]
2026-09-12 added CLMP menu and function + fix for midi-in timing
    [toern_fileoperations.ino, toern_helpers.ino, toern_menu.ino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]
2026-09-13 Fix freeverb wrap and ch11 idle leak, shrink the audio pool, and show a save checkmark.
    Overflow-safe comb mix plus muting leftover ch11 oscillators stops the delayed hiss at high RVRB; AudioMemory 96 frees RAM2; pattern/pack save animates a check then returns to draw.
    [toern_fileoperations.ino, toern_filter.ino, toern_menu.ino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]
2026-09-22 better info routes for buyers
    [toern_revH.kicad_pcb]
2026-09-28 Make sim↔device pattern transfer native and flash page on the right.
    Autoconnect RAM/file transfer without Connect/Disconnect, keep the screensaver off while linked, and show the CTRL=PAGE number on the matrix’s right edge when CRSR=CHNR is on.
2026-09-28 Add ETC FIRE embers and keep solo fastfilter usable.
    Rising embers (size/count/gravity/colour, sideways spread) with an off path that skips pool work; solo holds fastfilter on the 3rd encoder and moves random sample pick to the last.
    [toern_helpers.ino, toern_menu.ino, toern_ui.ino]
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2026-10-01 Allow VMOD CTRL=PAGE to visit empty pages before the last filled page.
    Encoder 2 now ranges 1..last-filled for that voice instead of skipping empty lead-in and gap pages.
2026-10-01 Add IMG mode: black matrix paint cycling voices 1–8, with touch1 brush select.
    Locks VMOD off and CLR to FIX while IMG is on; status-bar dots show the selected brush color.
    [toern_helpers.ino, toern_menu.ino, toern_ui.ino]
2026-10-01 Ship v3.01d: defer EEPROM while playing, fix menu enc3 max dead-zone.
    Avoid mid-playback flash writes that can bus-fault audio; re-apply page-count encoder limits after switchMode leaves max at 16.
    [toern_menu.ino, toern_sample.ino, toern_ui.ino]
2026-10-01 Fix F/F fill timing and one-shot re-arm without pause.
    Start the fill on the trigger step (was ~1 beat late), demote F/F→1/1 when done, and re-arm when the note is set to F/F again.
    [toern_midi.ino]
2026-10-02 Add USB audio out so the host hears the same mix as headphones.
    Switch to USB_MIDI_AUDIO_SERIAL and free DTCM headroom so the composite device still fits.
2026-10-05 Mark canonical build: 816 MHz, USB MIDI+Audio+Serial, smallest-code.
    Keep FLASHMEM and audio fixes; document the verified PlatformIO/Arduino options in info.md.
2026-10-07 Cap FastRec at 12s, debounce rec-touch hold, skip pad scans while capturing.
    Keep the voice-slot write bound, latch SWITCH_3 in time so a hold stays on until release, and stop FastTouch polling other pads in the drain loop so AudioRecordQueue is not starved.
    [toern_helpers.ino, toern_menu.ino]
2026-10-07 3.01f - fixed recording and startup with -0s parameter
    [toern_menu.ino]
2026-10-07 Hide the grid cursor on FILE and PACK.
    Those screens redraw only when the slot changes, so the cursor stayed painted on top. Mark the firmware v3.01f.
2026-10-08 fixed interpolation of samples
    [resamplerReader.h]
2026-10-08 fixed simulator encoder accessibility
2026-10-08 v3.01f-T2: add TIME stretch and stop MIDI live-paint from resetting the beat.
    Publish lastPage atomically and bump it on live notes so single-mode MIDI floods no longer race the playhead back to beat 1.
    [resamplerReader.h, toern_filterUI.ino]
2026-10-08 Make sample OCTV/DTNE true pitch controls and tidy NEW/filter UI.
    OCTV is 0..48 (±24 semis, white at full octaves); DTNE is fine ±1 semi. Also bipolar filter labels, RES/BITC danger colors, remapped NEW encoders, and matching sim.
2026-10-08 Replace EYES BAT/ON with idle timeouts OFF/1/5/15 min.
    Battery detection was unclear in use; ETC→EYES now picks when the screensaver starts instead.
    [toern_helpers.ino, toern_menu.ino]
2026-10-09 Drive play from analog CLK-IN in orange EXT instead of locking a BPM timer.
    CIN is config-only (hold-off and PPQN); the GPIO interrupt is armed only for analog EXT, and Play catches an already-high pulse so the first step is not one clock late.
2026-10-09 updated BAT45s Pins on PCB+Shematics
    [toern_revH.kicad_pcb, toern_revH.kicad_sch]
2026-10-09 updated Pogopins position
    [toern_revH.kicad_pcb]
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2026-10-12 added housing dxf files for both versions
    Document the 16×16 / 32×16 enclosure DXFs, shared COMMON parts, and laser-cutting workflow in the hardware docs.
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2026-10-21 Fix TRIG/sidechain gating and unify PQ-I/PQ-O clock I/O.
    J27 now pulses only on sequencer/fill hits (not paint/audition), shares one PIT end-timer with CLK-OUT, and PQ-I matches PQ-O with OFF/polarity plus EXT clock persistence.
2026-10-22 Share MIDI pitch conversion, extend CHNR to synths, bump to v3.02.
    Centralize fold/preserve pitch math for samples and synths (MIDI 69 = 440 Hz, sample root 60), and flash CHNR for voices 11/13/14 as well as 1–8.
2026-10-22 Add sample voice VOLUME, touch fill chord, and fader/pause polish.
    Voices 1–8 get an independent post-FX VOLUME beside DLAY; touch 3+4 / C+D queues live fills; fader overlays and pause tail cleanup keep exttouch playback cleaner.
2026-10-26 Serve the card from any screen and flash Beta without the program button.
    ETC → SD now only shows SCON wait/ok, the flasher reboots a running sketch into the bootloader, and the simulator follows the current copy gestures plus Sequencer One import.
2026-10-26 Put startup reset on touch 1 and add RAM to ETC → RSET.
    FULL stays a session reset. Holding touch 1 to 10 seconds, or choosing RAM, clears stored settings. Encoder 2 lights pink while FN is held.
2026-10-26 Free the simulator encoder keys and split live transfer from the file browser.
    Touch pads move to E, P, period, X and M so Q and W turn encoders again. SEND and GET stay beside the simulator.
2026-10-26 Align the simulator synth pitch and MIDI import with firmware.
    Held MIDI notes drive the ARP, oscillator tuning matches the device tables, and MIDI files map drums and roles onto TŒRN voices with a selectable song window.
2026-10-28 Restore selected editing and audio fixes on the clean baseline
    Preserve current sounds on manual pattern loads, allow safe shadowed-note painting, respect configured release, correct delay decay and MAIN startup volume, and render filter-reset feedback in the filter path.
    Release sample MIDI envelopes after the last held key and bypass sample cuts when HCUT is open and LCUT is off. Mirror behavior in the simulator, fix fresh dependency patching, and add regression coverage.
2026-10-28 Set full default velocity and refine sequencer display feedback
    Use velocity 127 for new notes, auditions and TOUCHY. Dim shadowed mono notes to 20 percent, suppress their playhead flash, and show lowercase c+p copy feedback.
    Update handbook and developer documentation, refresh simulator and beta firmware artifacts, remove the generated Arduino translation unit, and extend regression coverage.
2026-10-28 Add peak-limited mixing across audio buses and output routes
    Sum signed inputs before limiting with 16-sample lookahead and 50 ms recovery. Restore unity sample bus gains and matching synth gain while preserving existing sample readers and envelopes.
    Cover overload, cancellation, recovery and buffered-tail flushing; update audio documentation and beta firmware.
2026-10-28 Restore sustain bounds, sound-loading defaults and menu controls
    Clamp sustain to 1 across parameters, sliders and presets; correct LOUT UI-to-codec mapping; load saved sounds by default and reset sideload for each selection and browser visit.
    Move SWAP into SETT, add RSET RVRB bypass, polish BPM feedback and show page numbers independently of CHNR. Update simulator behavior, documentation, generated artifacts and regression tests.
2026-10-28 Add browser confirmations and restore external FN controls
    Map external button D to FN while preserving C+D fill, correct SMP FN encoder restoration, and show the full AUTOSAVE label.
    Confirm PATT/KIT overwrites and PATT/KIT/SMP deletion with NO by default. Snapshot action targets, restore browser selections, show cancellation feedback, and preserve empty pattern saves. Update simulator, documentation, beta firmware and regression tests.
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2026-10-29 Unify C4 home rows and restore sample one-shot envelopes.
    Grid and MIDI share channel+1 as C4, FN generation keeps existing notes, and samples play through unless sustain and release are both 0.
2026-10-30 Let FN+0200 generate without SUBP or the page row.
    Companion generate/undo now run from any DRAW or SINGLE row; A–E selection still uses FN + encoder 2 turn only when SUBP is on.
2026-10-30 Restore linear 0–2000 ms ATTACK mapping for samples and synths.
    Drop the quadratic 500 ms attack curve so early slider steps off 32 are audible again, matching the stock Teensy envelope and simulator.
2026-10-30 Cap matrix FPS after boot and ramp encoder volume like NeoSliders.
    Keep the intro at 60 fps, drop the grid to 30 after it, fix SINGLE home-row blending, and apply CTRL volume through the sample reader's ramped amplitude so turning encoder 2 no longer crackles or snaps.
2026-10-30 Bump to v3.03a with SMP loaded-sample mark.
    Show a right-side ">" when the browse row matches the voice's loaded sample, persist that identity across reboot/SP0 restore, and clear it on kit load.
2026-11-02 Swap teensyloader beta-eurorck option for beta-modulr firmware.
2026-11-02 Reduce audio CPU load and fix stale MCP button states
    - Move CH11 DSP state, mixers, routing and sampler controllers to DTCM
    - Optimize ladder DSP with -O2 while retaining size optimization elsewhere
    - Preserve polyphony, oversampling and effects
    - Recover stale physical button holds and missed release events
    - Add MCP performance telemetry, memory-layout checks and hardware results
    Validated on device; sample and delay buffers remain in PSRAM.
2026-11-02 Gate MCP behind active sessions and add a build switch
    Activate remote work only after HELLO, end sessions on BYE or lease expiry, and skip inactive display capture. Add a no-MCP build while preserving SD serial access, plus client handling, tests and developer documentation.
2026-11-02 Changed reverb
    Use a balanced six-comb/four-diffuser network with normalized wet energy and selectable light/full reference profiles.
    Preserve complete sample tails, avoid stale-envelope restart fades, and add automated USB playback, ADSR and reverb quality checks with developer documentation.
    Validated both firmware builds, DSP and lifecycle tests, and 22 USB hardware cases on CH1/CH2.
2026-11-02 Fix sample seek controls returning to full range
    Restore explicit trim encoder bounds and step sizes on sample-page entry without rewinding pending turns after slow previews. Clamp signed seek values and cover zero/full-range round trips, crossing bounds and page re-entry.
2026-11-02 Fix MIDI arp chord starts and CH11 articulation
    Collect opening MIDI chords before choosing the lowest arp note. Preserve CH11 filter drive across velocities and prefer idle poly voices over releasing slots. Add regression coverage and document the behavior.
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2026-11-02 Add temporary on-device AGEN arrangements and harden encoder reads
    Alternate prepared pages with randomized phrase lengths, an anchored key and motif, diatonic chords, probabilities, breaks, builds, fills and drops. Show readiness and countdown on both matrix sizes. Allocate the workspace only while enabled and keep musical knowledge in flash.
    Reject failed/short encoder reads, bound repeated I2C failures with runtime backoff, and expose finer stall diagnostics. Validate native state/music/rendering tests and both firmware builds; physically verify the I2C fix during playback.
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2026-11-09 Improve AGEN phrasing and replace countdown with activity icon
    Show a persistent clock ring with playback progress, an amber preparation spinner and a green ready check at the top-right edge. Keep device and simulator pixels consistent on both panel widths.
    Include the pending AGEN chord/register, buildup/drop, backing-part and simulator parity fixes, with handbook updates and regression tests. Restore the storage overlay helper argument already required by its existing callers so the staged firmware builds independently.
